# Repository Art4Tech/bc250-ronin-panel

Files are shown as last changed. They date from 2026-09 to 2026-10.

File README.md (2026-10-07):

# Ronin: A BC250 desktop

> [!NOTE]
> **Work in progress: the design and manual are changing rapidly.** You're welcome to build and remix Ronin. Check the revision notes and open decisions as you go. Rev0.3 is a provisional first edition, with fabrication and wiring details still to validate. If you have questions, [ask Arthur](https://artfedderson.tech/#start).

Ronin project logo

A custom desktop enclosure built around the BC250 board: a sheet-metal backbone, magnetically attached covers printed in transparent PCTG with a frosted finish, and an animated ESP32-P4 resource display at the base.

BC250 Ronin case visualization (https://artfedderson.tech/work/bc250-ronin)

**[Watch “The Computer They Didn't Make” — 89-second unofficial launch film](https://media.githubusercontent.com/media/Art4Tech/bc250-ronin-panel/main/case-design/Product_Renders_2026-10-03_V6/BC250_The_Computer_They_Didnt_Make_V6c.mp4)** · [Full project write-up](https://artfedderson.tech/work/bc250-ronin)

The film and images are CAD-based Blender visualizations. No case parts have been manufactured yet. Rendered features and lighting treatments are design proposals, not proof of completed hardware or firmware integration.

## Start with the case

| Location | Contents |
| --- | --- |
| [Printing and assembly manual — Rev0.3 draft](case-design/manual/README.md) | Illustrated PDF, editable BOM, open decisions, and proposed parts |
| [case-design/](case-design/README.md) | Design guide, download instructions, and portability notes |
| [BC250-Assy.SLDASM](case-design/BC250-Assy.SLDASM) | Main SolidWorks assembly, with component parts alongside it |
| [Backbone flat pattern](case-design/Flat%20pattern%20-%20Backbone.DXF) | Sheet-metal DXF export |
| [Latest film and website imagery](case-design/Product_Renders_2026-10-03_V6/) | V6c 89-second film, two Matchstick boards and untinted frosted PCTG |
| [Earlier V5 delivery](case-design/Product_Renders_2026-09-30_V5/) | Previous films and editable Blender scenes |
| [display/](display/README.md) | Published display baseline and current prototype status |
| [Rev A harness guide](case-design/manual/Ronin_LED_Harness_Rev_A.md) | Sourced connectors, numbered electrical maps, crimping and unverified interfaces |
| [October 6 manual updates](case-design/manual/REVISION_NOTES_2026-10-06.md) | Ordered adapter, new NVMe working-CAD route and next-revision checks |

Keep the contents of `case-design/` together so relative references stay intact. It includes the saved SolidWorks assembly and 45 part files, neutral CAD files, and all delivered render folders. It is a saved snapshot, not a clean-machine-validated Pack and Go export; see the [case guide](case-design/README.md) before fabrication.

## October 3 lighting revision

The latest rendered assembly replaces the rings and foot strip with two **Rainbow on a Matchstick boards by Blamm**, ten RGB LEDs per board. The revised CAD locations and printed diffusers are reflected in the new film. Untinted transparent PCTG is shown frosted, with 0.20 mm layer texture; the LEDs supply the color. See the [website update](https://artfedderson.tech/blog/bc250-matchstick-lighting-update) for component credits and current integration status. The original SolidWorks snapshot below is preserved and has not been replaced by this media release.

## October 6 hardware and display update

The **Ronin Rev A SATA-powered ESP32 LED adapter is ordered** and modeled in the current working CAD. It supplies two independent ten-pixel Matchstick channels while the display keeps USB power/control. One selector chooses 5 V or 12 V for both ports; **Matchstick V1.0 requires 5 V**. Delivery, bench checks, LED firmware and the real harness remain pending. Start with the [harness preparation guide](case-design/manual/Ronin_LED_Harness_Rev_A.md).

Ronin Rev A LED adapter design visualization

Design visualization from ordered fabrication layers and current CAD, not a physical-board photograph. Some component packages are simplified; the single 5 V selector shunt is illustrative. Native PCB/manufacturing files are not part of this public update.

Ronin Rev A adapter underside with exposed copper logo and board name

Ordered copper/mask artwork visualized in Blender with a gold ENIG finish. This is a design visualization, not an assembled-board photograph.

The working assembly now models an NVMe extension board, two printed extension mounts and an explicit ribbon route to the relocated SSD. Fit, retention and PCIe operation need physical testing. The repository's earlier CAD snapshot is unchanged; [October 6 revision notes](case-design/manual/REVISION_NOTES_2026-10-06.md) track the newer working CAD separately.

Current CAD locator of the NVMe extension, modeled ribbon and twin mounts

Pink identifies the ribbon route, lavender the two printed mounts, and teal the SSD/extension. The backbone and BC250 are ghosted for visibility. This is a current-CAD locator, not a cable cut-length, physical fit or storage-link validation.

## Current build status

- Machine internals are built and validated, with an initial cooling check complete.
- Software and the resource display are set up and working.
- Case fabrication is next. Fit and cooling need checking again inside the finished enclosure.
- Gamepad startup remains unfinished. The proposed LED layout still needs physical mounting and control integration.

Approximately **$375** has been spent so far, including the required filament. The remaining sheet-metal piece is estimated at **$275** for one unit, for an expected total around **$650**. A run of at least five targets a reduction of at least 60% in the sheet-metal cost (about $110 or less per piece); this is a target, not a confirmed quote for the whole machine.

## Get the complete design

CAD, Blender, and case media files use **Git LFS**. Install Git LFS, then:

```powershell
git lfs install
git clone https://github.com/Art4Tech/bc250-ronin-panel.git
cd bc250-ronin-panel
git lfs pull
git lfs fsck
```

Use a Git LFS checkout for the complete case assets. The [case-design README](case-design/README.md) includes SHA-256 verification instructions for the imported snapshot.

## Display and companion progress

The Windows prototype now has a native menu, profiles and six touch application tiles. Existing SolidWorks, Steam, Claude, PrusaSlicer, OBS and Codex windows come forward without duplicates; OBS also passed fresh-launch focus. USB resource telemetry and scene/audio controls work. [Current prototype status](display/CURRENT_STATUS.md) separates this local tested work from the earlier software package published here.

Linux, initially Bazzite, remains the design baseline. The shared app/protocol and portable profiles keep the workflow consistent; installed programs, sensors and desktop activation need host-specific bindings. Physical Linux/Wayland/Gaming Mode tests, Matchstick output, gamepad host wake and AI voice remain pending. Display Sleep/Wake affects the display, not PC power. Claude/Codex tiles open host apps; they are not the voice companion.

## Work on the display

The published baseline ESP32 firmware, resource companion, media, build scripts and original documentation live in **[display/](display/README.md)**. Start with that README and run its commands from `display/`. Its internal `project/` and `external-originals/` layout and pinned dependency release are preserved.

Third-party component models, software, and supplied media retain their existing rights. This repository assigns no blanket license to them.

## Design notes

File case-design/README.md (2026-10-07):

# Ronin case design

Ronin project logo

[Project overview](../README.md) · [Display software and its original README](../display/README.md)

> [!NOTE]
> **Work in progress: the design and manual are changing rapidly.** You're welcome to build and remix the case. The [Rev0.3 printing and assembly manual](manual/README.md) records the current revision and open decisions. Mounting, wiring, fit and assembly details still need validation. If you have questions, [ask Arthur](https://artfedderson.tech/#start).

Saved design and rendering snapshot imported on 2026-10-01. The original folder layout is retained so nearby parts, media and relative Blender references stay together.

## Printing and assembly manual

Start with the [Rev0.3 manual and editable companion files](manual/README.md). The PDF records current CAD locators, printing guidance, component evidence, and unresolved build decisions. The CSV and JSON files make the BOM, open items, and proposed parts easy to review and update. The saved October 1 CAD snapshot in this folder and the manual's later source revision must be checked together before fabrication.

## Latest media revision

[Product_Renders_2026-10-03_V6/](Product_Renders_2026-10-03_V6/) contains the new 89-second V6c film and compressed website images. It shows the updated two-board, twenty-LED Matchstick arrangement and frosted untinted PCTG. This is a media release; the October 1 SolidWorks snapshot is retained unchanged. The earlier V5 editable scenes remain available at their original paths.

## Open the design

- `BC250-Assy.SLDASM`: main SolidWorks assembly. The supplied `.SLDPRT` files are alongside it.
- `Flat pattern - Backbone.DXF`: backbone flat-pattern export.
- `.STEP` / `.stp` files: supplied neutral CAD component files.
- `bazziteBC250gui.png`: display reference artwork.
- `Product_Renders_2026-09-30_V5/`: earlier delivered photography and films, including the calm-audio commercial revisions and their editable Blender masters. Start with its `README.txt` and `Preview.html`.
- The original, V2 and V3 render folders preserve earlier deliverables.

The V5 handover states that GUI images, fonts and audio are packed where supported, and image strips use relative paths. Keep `cinematic_assets`, `stills`, and the other companion directories beside the Blender files. No raw render caches or rendering scripts are required to reopen these delivered scenes according to that handover.

The V5 lighting layout is a Blender proposal. Its reversed LED rings and foot strip are not completed mounting changes in the SolidWorks model. Rendered captions and effects do not establish that the panel firmware implements the depicted feature; see the repository's software status.

## October 6 working-CAD changes

The current working assembly includes one visible **Ronin Rev A SATA LED adapter**, one NVMe extension board, two printed extension mounts, one modeled extension ribbon and a relocated M.2 2280 SSD. The adapter has been ordered; delivery and bench acceptance are pending. The explicit ribbon route and mounts are modeled proposals awaiting physical fit, retention and PCIe checks.

Ordered LED adapter design visualization

Visualization from ordered fabrication layers and current CAD, not a physical photograph. Some packages are simplified; the optional single 5 V shunt is illustrated. This documentation/media update does not replace the saved October 1 assembly or publish native PCB/manufacturing files. See [manual revision notes](manual/REVISION_NOTES_2026-10-06.md) and [harness preparation](manual/Ronin_LED_Harness_Rev_A.md).

Ronin Rev A adapter underside with exposed copper logo and board name

Ordered copper/mask artwork visualized in Blender with a gold ENIG finish. This is a design visualization, not an assembled-board photograph.

Current CAD locator of the NVMe extension, modeled ribbon and twin mounts

Pink identifies the ribbon route, lavender the two printed mounts, and teal the SSD/extension. The backbone and BC250 are ghosted for visibility. This is a current-CAD locator, not a cable cut-length, physical fit or storage-link validation.

## Display progress

The current local Windows prototype has verified USB telemetry, scene/audio controls, a native menu/profiles and six application tiles. Existing app focus and duplicate suppression passed; OBS also passed fresh-launch focus. The repository retains an earlier software baseline. [Current status](../display/CURRENT_STATUS.md) explains the distinction and the Linux-first shared workflow.

Physical Linux GUI/Wayland/Gaming Mode, Matchstick output, gamepad host wake and AI voice remain pending. The two independent LED channels use SATA power; the display stays USB-powered. Matchstick V1.0 requires the adapter's **5 V** selection. Final wiring, mounts and firmware must be validated before applying power.

## Download and verify

CAD and media binaries are stored with Git LFS. With Git LFS installed:

```powershell
git lfs install
git clone https://github.com/Art4Tech/bc250-ronin-panel.git
cd bc250-ronin-panel
git lfs pull
git lfs fsck
```

`FILES-SHA256.json` lists every imported file, its size and SHA-256. From the repository root, verify the materialized files:

```powershell
$items = Get-Content -LiteralPath .\case-design\FILES-SHA256.json -Raw | ConvertFrom-Json
foreach ($item in $items) {
    $path = Join-Path .\case-design $item.path
    if ((Get-Item -LiteralPath $path).Length -ne $item.bytes -or
        (Get-FileHash -LiteralPath $path -Algorithm SHA256).Hash -ne $item.sha256) {
        throw "Verification failed: $($item.path)"
    }
}
"Verified $($items.Count) imported files."
```

Third-party component models retain their existing rights. No blanket license is assigned by this import.

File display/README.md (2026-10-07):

# Ronin display and companion

This is the original ESP32 resource-panel package, now contained in `display/`. The firmware and companion retain their existing paths under `project/` within this folder. For the enclosure, see the [project overview](../README.md) and [case-design guide](../case-design/README.md).

Case binary assets use **Git LFS**. Install Git LFS, then run `git lfs install` before cloning and `git lfs pull` inside the checkout afterward. Download ZIP is intended for the panel software workflow below; use a Git LFS checkout to obtain the complete case assets reliably.

## Baseline and newer prototype

The source, binaries and commands below are the **earlier published resource-panel baseline**. The newer local prototype has verified native menu/profiles and six Windows app tiles with existing-window focus and duplicate suppression. [Current status](CURRENT_STATUS.md) records its physical checks and Linux limits; this documentation update does not update the baseline firmware package.

The **Rev A SATA-powered LED adapter is ordered**. See [harness preparation](../case-design/manual/Ronin_LED_Harness_Rev_A.md) for sourced parts and unverified connector/mux interfaces. Two independent Matchstick channels, startup/fault handling and physical LEDs remain firmware/bench work.

## Resource panel — published baseline

An Elecrow CrowPanel Advanced **5-inch ESP32-P4 V1.0** display for a BC250 desktop, with a serene animated ronin/onsen scene, day/night transitions, per-clip sound, and USB serial resource monitoring from Windows or Linux.

**Working in this baseline:** CPU/RAM/disk usage, optional Windows CPU temperature through LibreHardwareMonitor, touchscreen sleep/wake, four SD video/audio clips, settings QR helper, and Bluetooth scanning/pairing experiments.

**Unfinished in this baseline:** the voice-companion workflow, two-board Matchstick ARGB control, app/page-aware touch shortcuts, reliable GameSir button input and PC power-on relay, standby wiring, controller handoff, and native USB microphone/speaker and video streaming. A successful BLE connection is not a completed PC power-on solution.

## Next display work

Linux, initially Bazzite, is the product baseline. Keep one shared companion/protocol and portable profiles, with explicit host-local paths, sensors, permissions and desktop bindings. Linux GUI/Wayland/Gaming Mode acceptance remains pending. Elgato software is not intended as a normal-operation requirement.

Planned work includes advanced effects for the two ten-pixel Matchsticks, resource-module configuration, automatic app-context/held shortcuts, gamepad host wake and AI voice. Current touch releases/manual profiles do not establish those broader features. Display Sleep/Wake does not operate PC power; scene audio and Claude/Codex host-app tiles are not a completed voice workflow. See [current status](CURRENT_STATUS.md) before choosing a package or making feature claims.

## Continue on Windows

Clone this repository into a short path, then open PowerShell there:

If Git is not installed yet, use GitHub's **Code → Download ZIP**, extract it to a short path such as `C:\BC250`, and run the same commands below. The dependency release includes Git for the firmware build.

```powershell
cd .\display
powershell -NoProfile -ExecutionPolicy Bypass -File .\Get-Dependencies.ps1
powershell -NoProfile -ExecutionPolicy Bypass -File .\Build-Firmware.ps1
```

Run all subsequent commands from `display/`. The dependency script downloads hash-verified release assets containing the pinned Windows SDK, toolchains and Python environments, then relocates them. The build script creates a fresh `build-migrated` directory. It does not flash the board. Windows x64 is required for these prebuilt tools. Firmware source and installed managed components are in `project/work/panel-test`.

The existing display can be moved without reflashing. Start the companion using the newly assigned COM port:

```powershell
$py='.\project\work\idf-tools\python_env\idf5.5_py3.12_env\Scripts\python.exe'
& $py .\project\outputs\Resource-Panel\resource_panel.py --list-ports
& .\project\outputs\Resource-Panel\Windows-Monitor.ps1 -Action Start -Port COM7
```

See [HANDOVER.md](HANDOVER.md) for build, flashing, SD layout, Windows temperature setup, Linux companion instructions, testing and unfinished work. It also describes the separate complete private migration package; private-only files mentioned there are intentionally absent from this public repository. See [PUBLICATION.md](PUBLICATION.md) for the exact boundary.

## Media and firmware

All six supplied MP4 originals and the generated artwork versions are included. Current SD files are the eight `day3`, `nite3`, `sleep3`, and `wake3` `.rvj`/`.pcm` assets under `project/outputs/Resource-Panel/video/movies-v3`; place them in `/BC250` on the card. Each clip has its own audio; transition audio continues into the idle scene. Initial caching takes about 47 seconds and playback is approximately 10 fps.

Current release binary: `project/outputs/Resource-Panel/firmware/dashboard-movies-v3.bin`. Historical C exports in outputs are snapshots; **edit the full project source** in `project/work/panel-test`.

`Prepare-Media.py` rebuilds conversions into a new directory without overwriting supplied assets. The old procedural warp preview was rejected; the current animation uses supplied videos.

Third-party source and tools retain their own licenses. No new blanket license is assigned to vendor code or supplied media by this repository.

## Display preview

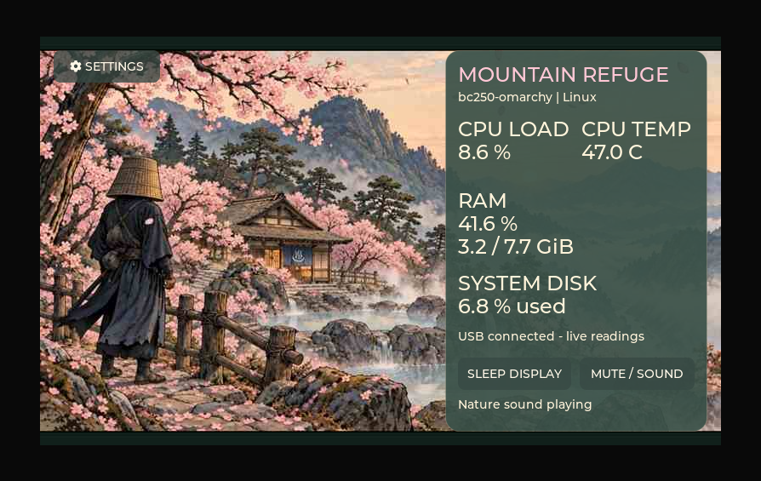
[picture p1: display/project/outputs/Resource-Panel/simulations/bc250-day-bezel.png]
Day scene with simulated Omarchy/BC250 readings


This preview uses an unchanged frame of the current day video and the firmware's bitmap fonts. The active image is 800 × 480 pixels. The [printable sizing preview](project/outputs/Resource-Panel/simulations/bc250-day-actual-size.html) and [physical-size SVG](project/outputs/Resource-Panel/simulations/bc250-day-actual-size.svg) use a 120.7 × 76.3 mm black front, with a centered 108 × 64.8 mm active area. Values are illustrative, assuming approximately 8 GiB assigned to system RAM; they are not measured BC250 results. See preview-details.json for assumptions. This is not a fabrication drawing.

## Bazzite preview — historical UI concept

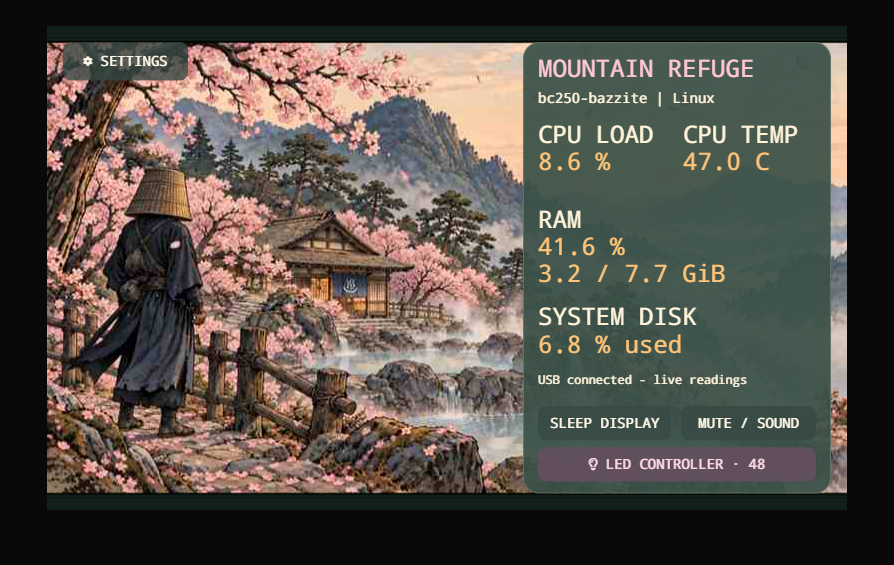
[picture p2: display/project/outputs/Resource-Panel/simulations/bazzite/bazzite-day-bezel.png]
Bazzite dashboard concept


[Interactive preview](project/outputs/Resource-Panel/simulations/bazzite/bazzite-interactive-preview.html) (download and open locally): DroidSansM Nerd Font Mono, LED controller concept for two 24-pixel rings, and 120.7 × 76.3 mm outer dimensions with 3.5 mm top and 7.5 mm bottom bands. Native image is 800 × 480; the physical illustration models a 108 × 65.3 mm active area. This is a simulated UI, not flashed firmware or a fabrication drawing. [Preliminary wiring notes](project/outputs/Resource-Panel/simulations/bazzite/NEOPIXEL-WIRING.md).

This preserved Bazzite preview predates the current lighting hardware. Its two 24-pixel ring controls are historical UI concepts; the current target is two ten-LED Rainbow on a Matchstick boards. Matchstick control, voice interaction, host gamepad wake and automatic context switching remain pending. Manually selected action pages now work in the newer local prototype described in [current status](CURRENT_STATUS.md); this historical preview remains unchanged.

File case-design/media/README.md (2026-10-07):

# Ronin October 6 hardware illustrations

These are Blender renders from the October 6 working CAD and the Gerbers used for the ordered Rev A PCB. They are design visualizations, not photographs of manufactured hardware.

- [Adapter top](ronin-led-adapter-top.jpg) and [detail](ronin-led-adapter-detail.jpg): current component bodies and ordered copper/mask/silkscreen. Some IC/fuse packages are simplified, and the single 5 V selector shunt is illustrative rather than a confirmed shipment configuration.
- [Adapter back](ronin-led-adapter-bottom.jpg): actual ordered exposed-copper logo and board-name artwork, with an ENIG material.
- [NVMe locator](ronin-nvme-route.jpg): current modeled extension, relocated 2280 SSD, two printed mounts and ribbon route. Pink is the ribbon, lavender the mounts, and teal the SSD/extension. Ghosted backbone/BC250 geometry makes the route visible. Colors do not describe actual material, temperature or airflow.

Board arrival, assembly inspection, electrical/thermal checks, installed fit and LED control remain pending. The cable drawing is not a cut-length, bend-limit or PCIe validation. The public CAD/software packages elsewhere in the repository remain earlier snapshots; see the manual revision notes and current display status.

Native PCB/CAD manufacturing inputs, Gerbers, BOM/CPL and Blender source files are withheld from this public media update.

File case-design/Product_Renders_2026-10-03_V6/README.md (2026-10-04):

# V6c — The Computer They Didn't Make

[Watch the 89-second film](https://media.githubusercontent.com/media/Art4Tech/bc250-ronin-panel/main/case-design/Product_Renders_2026-10-03_V6/BC250_The_Computer_They_Didnt_Make_V6c.mp4) · [Case study](https://artfedderson.tech/work/bc250-ronin) · [Lighting revision](https://artfedderson.tech/blog/bc250-matchstick-lighting-update)

Published media revision, October 3, 2026. 1920 × 1080, 24 fps, 89 seconds, H.264 with stereo AAC and fast-start metadata. Instrumental score; no narration, typing clicks or abrasive transition wipes. Twenty seconds of additional reading time are distributed across the captions. The final card uses “soon™.”

The current lighting assembly uses two Rainbow on a Matchstick boards by Blamm, ten RGB LEDs each, and their printed diffusers in the updated CAD positions. The earlier rings and foot strip have been removed. Transparent 3D-Fuel PCTG is visualized with frosted surfaces and visible 0.20 mm FDM layer lines; color comes from the RGB LEDs.

The case and its contents are native CAD renders. The maker-desk scenes combine them and official Voron V0.2r1 CAD with generated room/person backgrounds. This is an independent, unofficial thought experiment with no Voron endorsement. Images do not show a fabricated enclosure or establish performance, fit or thermal results. Enclosure fabrication, revised lighting integration and gamepad startup remain unfinished.

Specific contributor credits: Rainbow on a Matchstick by Blamm; EPS Power Adapter and PS_ON adapter by Mosfet.Party; the single 92 mm fan-shroud remix based on MandicReally's CAD.

This folder publishes the final film, its verification report, and compressed website imagery. It does not replace the original SolidWorks snapshot or claim to be a new Pack and Go export. Earlier V5 films and editable scenes retain their original paths. The new editable Blender masters and complete companion assets are in the local V6 delivery.

Binary files use Git LFS. `FILES-SHA256.json` records this media release independently of the original case snapshot's manifest. Third-party model/media rights remain with their respective owners; this release assigns no blanket license.

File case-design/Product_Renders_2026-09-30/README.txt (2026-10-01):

BC250 PRODUCT STUDIO — 30 September 2026

Open BC250_Product_Studio.blend in Blender 5.2 or newer.
The GUI image is packed into the project; no texture relinking is required.

DELIVERABLES (16-bit PNG masters; JPEG versions in share-ready)
01_BC250_Dark_Hero.png — dark front / left three-quarter, 2400 x 2400
02_BC250_Bright_Studio.png — bright front / right three-quarter, 2400 x 2400
03_BC250_Rear_Illumination.png — rear view with the two illuminated buttons, 2400 x 2400
04_BC250_Display_Detail.png — original backlit GUI and front detail, 2600 x 1800
05_BC250_PCTG_Layers.png — rear vents, printed texture and button lighting, 2600 x 1800
06_BC250_Animated_Studio_Loop.mp4 — four-second seamless 1080 x 1080 H.264 loop at 24 fps

BLENDER SCENES
01 | Dark studio
02 | Bright studio
03 | Animated studio loop

The CAD assembly, lighting additions and photographic studio are in separate
collections. Component and body names are retained. The model uses meters;
the interface is configured to display millimeters. Stills use Cycles,
adaptive sampling and denoising. The project supports AMD HIP GPU rendering.

PRINTED PCTG
Purple translucent appearances have been translated to rough transmission,
volume absorption and procedural ridges at 0.20 mm pitch. Wall panels use
assembled vertical as the print direction. The top cover stands on its rear
edge. Change each "Print direction" empty to adjust the build direction;
change the layer-pitch math node and bump distance in the PCTG materials
to adjust layer height and prominence. This is a visual surface model, not
a slicer toolpath simulation, volumetric infill or a measured filament match.

LIGHTING AND ANIMATION
A concept LED strip is placed beneath the BC250 PCB with soft internal fill.
The existing left power-ring diffuser and rear power/reset button geometry
have emissive finishes. The original GUI is textured at its SolidWorks sketch
picture coordinates. The animation adds a small live-status pulse and gentle
backlight variation, plus a slow camera move; it is not a live software feed.

IMPORT NOTE
67 visible components were imported from the open BC250-Assy assembly,
using 2,281,689 source triangles. Source CAD files were not saved or altered.
SolidWorks did not provide mesh triangles for four small curved surfaces on
the two 92 mm fans (approximately 330 square millimeters per fan). A second
CAD tessellation method also failed. The affected faces are omitted and
listed in the Blender project's READ ME text. Enclosure and display meshes
were unaffected. CAD material colors and assignments were translated to
Blender's physically based shaders; the shading systems are not identical.

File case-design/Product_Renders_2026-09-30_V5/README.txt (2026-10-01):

BC250 — V5 / INDEPENDENT LED OUTPUT

The 48 ring LEDs have 20 times their V3 output; the 12-pixel foot strip has 8 times its V3 output. This is 10 times and 4 times, respectively, the V4 preview output. LED direction, geometry, studio exposure, colors and animation timing are retained.

Lighting revision
The two imported 24-pixel rings now face the sheet-metal backbone in the Blender proposal. Their light bounces into real gaps and perforations; the PCB and backbone remain opaque. Only the forward lens faces emit. Package sides and backs do not emit, and the previous omnidirectional RGB light helpers have been removed.

An 80 mm strip with 12 individual RGB LED packages sits at the foot of the board and points upward along the component side. It uses lower output than the rings and follows their color treatments, animated rainbow, wake-up and dimming. There are 60 individually animated RGB emitters in total. Neutral white is included alongside cyan, magenta, mint and rainbow.

The ring orientation and foot strip are proposed physical layout changes represented in Blender. Original SolidWorks files were not changed. The strip is a rendering concept, not a completed CAD mounting design. Intensity is composed for photography, not a calibrated prediction of physical LED output.

Deliverables
BC250_60s_Directional_RGB.mp4 — 60 seconds, 1920 × 1080, 24 fps, H.264.
BC250_Showcase_Directional.blend — complete editable assembly, camera, lighting, animation and feature captions.
BC250_Directional_Studio.blend — separate still-photography studio.
stills — eight full-resolution 16-bit PNG masters.
share-ready — matching full-resolution JPEGs, quality 95.
Preview.html — local photo gallery and movie player.
Photo_Contact_Sheet.jpg — photo overview.

Photo treatments
01 Cyan / dark hero
02 Neutral white / rear three-quarter
03 Magenta / dark hero
04 Mint / bright studio
05 Addressable RGB / rear three-quarter
06 Addressable RGB / display and power-button detail
07 Addressable RGB / PCTG surface detail
08 Neutral white / dark hero

Film timing
00–03 Opening hero
03–10 Front view, 5.3-inch touch display, integrated ESP32, LED control and resource monitoring
10–16 Right side and four USB ports; neutral-white LEDs
16–22 Rear view and Wi-Fi 7 / BLE 5.3 via NVMe splitter; mint LEDs
22–28 Elevated flyover and NVMe in cooling airflow; magenta LEDs
28–34 Left side and Dual Arctic P9 PWM PST fans; neutral-white LEDs
34–41 Magnetic cover removal and reassembly; rainbow LEDs
41–46 Bright studio and gamepad startup
46–49 Studio fades to dark
49–51 Rings and foot strip wake in sequence
51–55 Display wakes while the rainbow pattern moves through individual LEDs
55–58 Display sleeps; RGB emitters dim to 8 percent
58–60 Dimmed hero and fade to black for looping

Blender scenes
01 | Dark studio
02 | Bright studio
03 | 60 second flyover — camera, RGB, studio lighting, screen and cover movement
04 | Final film + feature captions — editable captions and fades over Scene 03

Source and materials
All 79 visible SolidWorks component instances are represented. Both 24-pixel rings and ten additional magnets were imported from the refreshed assembly, together with changed backbone and front/top/rear-cover geometry. Raised LED packages and lens surfaces were added at the ring CAD footprints. The original GUI and fonts are packed. GUI animation represents backlight/status behavior rather than a recording of the software.

Translucent PCTG retains procedural 0.20 mm layers with upright panel print orientation. These surface layers approximate FDM appearance; internal infill and slicer toolpaths are not simulated. Cover movement is an illustrative exploded view returning to the imported positions. As in the previous deliverable, four small curved fan faces failed SolidWorks tessellation, about 330 square millimeters per fan; the other visible fan geometry is present.

Rendering
Cycles with ray-traced shadows and indirect illumination. Stills use 96 samples; the film uses 16 during motion and 48 on stationary holds, with denoising. Identical static film states reuse an identical rendered frame. The 60-pixel RGB animation, studio transitions, screen wake/sleep and original feature captions remain baked into the Blender files. No external scripts are required for playback or editing.

COMMERCIAL FILMS

BC250_Cinematic_Commercial.mp4
The first requested commercial: the 60-second all-sides camera tour with five close-up cutaways, animated feature captions, the magnetic-cover demonstration, and the studio / RGB / display wake-and-sleep finale. The close-ups are 2304 x 1296 Cycles renders with depth of field and subtle editorial push-ins. The cooling close-up temporarily removes the front cover for visibility; its caption states that the cover is removed.
BC250_Cinematic_Commercial.blend is the editable source. It contains the original full 3D tour, macro cameras, image cutaways, typography and audio.

BC250_Made_To_Be_Seen.mp4
The second requested commercial, with a separate creative treatment: 'Made to Be Seen'. A new grazing-light macro and low hero camera move open the film; a tighter editorial sequence moves through touch control, connectivity, airflow, magnetic covers and three lighting personalities. The studio-to-night sequence returns before the final BC250 signature. It has a new original score and effects mix.
BC250_Made_To_Be_Seen.blend is the editable master. It includes the original tour scene and the new eight-second light-study scene, using live 3D Scene strips rather than requiring the cached render frames.
BC250_Director_Light_Study.blend is the standalone new cinematography setup. The case and component mesh coordinates and topology were hashed before and after its preparation; all matched. No product meshes were added or edited. Cameras, studio lamps, LED output animation, editing, typography and sound were changed. Product surface materials and the physical LED occlusion are retained.

Both commercials are 60 seconds, 1920 x 1080, 24 fps, H.264 with 48 kHz stereo AAC audio at 256 kbps. BC250_60s_Directional_RGB.mp4 is the additional silent all-sides showcase.

The music and sound design were synthesised specifically for these films, with no third-party recordings or sampled songs. The two 60-second 48 kHz / 24-bit stereo WAV masters are included in cinematic_assets. Audio peaks and durations were checked numerically; the film containers were checked for both video and AAC audio tracks.

The new moving macro uses 48 Cycles samples, and the new moving hero uses 32, with denoising. The existing tour uses the sampling described above. The new eight-second shot sequence is reused for the closing hero; the rest of the second film uses a fresh edit of the accurate V5 tour and photographs.

PORTABLE PROJECTS
Keep the cinematic_assets and stills directories alongside the Blender files. GUI images, fonts and audio are packed where Blender supports it; VSE image strips use relative paths to the included images. No rendering scripts or raw frame caches are needed to reopen and edit the projects. The live tour scenes include compositor-based AgX finishing followed by a Standard inverse conversion, with the scene view set to Standard, so the editable scene strips retain the same photographic look as the final films. Comparison frames were rendered directly from both commercial projects and checked against the decoded exports. The videos are ready to share directly.

Preview.html and Photos.html play all three videos and display the eight photographs. The verification reports record video frame counts, dimensions, durations, audio tracks, and unchanged geometry. Original SolidWorks files remain untouched.

CALM AUDIO REVISION
Both commercials now have calm replacement mixes. Every noise-based transition sweep and scratchy mechanical click has been removed. The second film's noise-based hi-hat is also removed. The music retains its previous level; the remaining soft LED/display tones are approximately 14 dB quieter. No gain normalization was applied to compensate for the removed effects.

BC250_Cinematic_Commercial_Calm_Audio.mp4
BC250_Made_To_Be_Seen_Calm_Audio.mp4

The original video streams were copied without re-encoding and their hashes match exactly. The canonical commercial MP4 filenames also contain the revised mixes. Both editable commercial Blender files and their packed WAV masters have been updated. The silent all-sides showcase and photographs are unchanged.

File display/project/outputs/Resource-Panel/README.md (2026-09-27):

# USB Resource Panel

Elecrow CrowPanel Advanced 5-inch ESP32-P4 V1.0. Connect the computer to the panel's **UART0 USB-C** port with a data cable. No Wi-Fi is used.

## Current features

- Total CPU utilization, RAM utilization and used/total GiB.
- Used percentage of the host's system filesystem (not all attached drives).
- CPU temperature when a supported Linux sensor is available. The displayed Linux value is the hottest reading in the selected CPU sensor group.
- Host name and operating system.
- Readings clear after five seconds without valid updates.
- The on-panel microphone/speaker recording test remains available.

This firmware does **not** yet provide USB microphone/speaker endpoints, Bluetooth gamepad reception, GPU utilization, fan monitoring, or power-button control. The audio button runs a local recording/playback test only. Windows CPU temperature needs an additional hardware-monitor integration; this version shows Unavailable. It does not use the ESP32's own temperature as the PC temperature.

## Windows setup

Install Python 3 if necessary, then open a terminal in this folder:

```powershell
py -m venv .venv
.\.venv\Scripts\python.exe -m pip install -r requirements.txt
.\.venv\Scripts\python.exe resource_panel.py --list-ports
.\.venv\Scripts\python.exe resource_panel.py --port COM10
```

COM10 was the port on the development PC. Confirm the port on each computer. Keep the terminal open; Ctrl+C stops monitoring. Close serial monitors before running this program. No administrator privileges or network access are needed during normal monitoring.

## Debian, Ubuntu, Raspberry Pi OS, or Omarchy

Install Python 3 with venv/pip support through the distribution's package manager. For Debian/Ubuntu this is normally `sudo apt install python3-venv python3-pip`; Omarchy/Arch uses `sudo pacman -S python python-pip`.

```sh
python3 -m venv .venv
.venv/bin/python -m pip install -r requirements.txt
.venv/bin/python resource_panel.py --list-ports
.venv/bin/python resource_panel.py --port /dev/serial/by-id/YOUR-PANEL
```

Use the actual stable /dev/serial/by-id path when available; otherwise use the listed /dev/ttyUSB device. If access is denied, check its owning group with `ls -l /dev/ttyUSB*`. Add your user to the owning serial-access group (commonly dialout on Debian/Ubuntu or uucp on Arch), then log out and back in. Do not make the device world-writable.

The same script supports Windows and Linux; only Windows has been tested on physical hardware so far. Linux sensor availability depends on the board, kernel and exposed hwmon/thermal drivers.

## Checks

1. Start the companion; readings and host name should appear within two seconds.
2. Compare RAM usage with the host's monitor. Sampling and accounting may differ from Windows Task Manager.
3. Stop the companion. Within five seconds the panel should show Disconnected and clear its readings.
4. Restart it; readings should return. Unplugging/replugging is retried automatically when the port path remains the same.
5. Move the panel to another supported computer and run its local companion. No firmware change is required.

Use `--once` to inspect one sample without USB. Use `--disk D:\\` on Windows or `--disk /mnt/data` on Linux to monitor another filesystem. Use `--seconds 30` for a timed test.

The companion sends resource numbers and the host name over the USB cable. It does not open a network listener or send commands to the computer. It is not installed as an automatic startup service.

## Recovery

The adjacent Panel-Recovery folder contains the original 16 MB factory flash backup and its checksum. App-only images are not substitutes for that full backup. Preserve recovery files before modifying firmware.

## Convenient Windows start/stop

The panel's SETTINGS button now shows a verified QR code and readable link to the official Libre Hardware Monitor downloads, plus USB/CPU-temperature status. See [Windows-Setup.md](Windows-Setup.md). The companion optionally reads CPU temperatures from Libre Hardware Monitor's local WMI feed; keep windows_temperature.py beside resource_panel.py. No network listener is required. The QR links to the sensor helper, not an installer for this companion.

Run Windows-Monitor.ps1 -Action Start -Port COM10 to start monitoring in the background, and Windows-Monitor.ps1 -Action Stop to stop it. It uses this folder's .venv, or the existing development environment on this PC. It does not register a startup task. The monitor retries if USB is unplugged. Logs and a process record are kept beside the script.

## Sakura mountain refuge

The dashboard embeds matching day/night paintings, 36 drifting petals, a gently swaying foreground sakura branch, subtle water ripples, slow cloud drift and daytime mist. The ronin's poses crossfade over 2.2 seconds; this is not a skeletal or frame-by-frame character animation. Original artwork and built-in image-generation prompts are in `art/`.

Sleep Display hides the resource overlay, shows the sleeping ronin and dims the backlight from 60% to 12%. The panel stays powered and touch-sensitive. Tap anywhere to return to daylight. This button does not shut down the host computer.

The companion marks its first packet after opening USB, or after a sending gap longer than five seconds, as a wake event. The display also wakes when valid telemetry resumes after a five-second gap. Ordinary updates leave a manually sleeping display asleep. Restarting the companion therefore wakes the display too; this is a host-connection indication, not a verified BC250 power-state signal. Powering off the panel's USB supply prevents it from showing the night scene or receiving Bluetooth.

Test with the companion running: press Sleep Display, wait at least ten seconds, then tap to wake. Press Sleep again, stop the companion for more than five seconds and restart it: daylight should return automatically. Repeat during a transition to check responsiveness. Confirm the resource text stays readable and petals move smoothly. The local audio test remains available.

The experimental video firmware plays day/night MJPEG clips from microSD and includes GameSir BLE testing. The GameSir has paired in G-Touch mode; waking the display on a new controller connection is implemented but still needs a physical test. Home-button reports and BC250 power-relay operation are not implemented. No Wi-Fi connection is needed. See TEST-STATUS.md for current limitations; dashboard.bin remains the earlier artwork-only fallback.

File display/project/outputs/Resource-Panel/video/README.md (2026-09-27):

# Full-screen motion test

Open preview.html to preview the animated painting locally. These loops animate water, clouds, blossoms and the canopy from the existing artwork. The ronin remains in the standing or sleeping pose; this is not a frame-by-frame sit/stand character animation.

Each day.rvj/night.rvj contains 60 distinct baseline JPEG frames at 800×480, requesting 15 fps. The panel's P4 hardware JPEG decoder renders them from the card, retaining the live resource overlay and touch sleep/wake controls. Actual delivered FPS is logged as PANEL_VIDEO and must be measured on hardware with Bluetooth and SD activity running.

Files go in /BC250/day.rvj and /BC250/night.rvj on the card. The uploader refuses to overwrite existing clips or temporary files. It verifies SHA-256 on the panel and only renames the temporary file after a complete, matching transfer. No formatting is performed. Existing unrelated card files are preserved.

Stop Windows-Monitor.ps1 before running ../upload_video.py day.rvj night.rvj with the development Python environment. The uploader briefly changes serial speed to 460800 for transfer, then returns it to 115200. Restart Windows-Monitor.ps1 afterward. Do not remove the card or disconnect power during transfer. These RVJ files use our small frame container, not an AVI/MP4 container; arbitrary MP4 files do not play directly.

RV01 container: 16-byte little-endian header: magic RV01, uint16 width, uint16 height, uint16 fps, uint16 reserved, uint32 frame count. Each frame: uint32 JPEG byte length followed by JPEG data. Accepted dimensions are exactly 800×480, 1–30 fps, at most 9000 frames, and at most 256 KiB per compressed frame.

With no valid clip, the built-in scene remains available. Native USB live video streaming from the host is not implemented yet. This first test verifies local decode, display refresh, and SD throughput before adding a streaming transport.

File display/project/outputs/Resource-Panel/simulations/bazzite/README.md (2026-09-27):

# Bazzite preview

UI mockup only, not flashed firmware. Open bazzite-interactive-preview.html; the LED button opens a working local interaction preview with power, colors, brightness and effect selection. No hardware connection is made.

The PNG active area is exactly 800x480. The black bezel is horizontally centered and raised vertically: 3.5mm top / 7.5mm bottom with a modeled 108x65.3mm active area. Overall size is 120.7x76.3mm, as requested. Native PNGs remain 800x480; the bezel illustration applies slight vertical scaling. Print the HTML at Actual size / 100% for physical dimensions; on-screen size depends on monitor scaling.

Font: DroidSansM Nerd Font Mono, from https://github.com/ryanoasis/nerd-fonts/tree/master/patched-fonts/DroidSansMono . Font license is included under fonts/. The HTML embeds its font and video frame for offline viewing.

Readings are simulated light-desktop values, not Bazzite benchmarks. The planned count is 48 RGB pixels (two 24-pixel rings). Exact NeoPixel product, connector and a confirmed free ESP32-P4 GPIO are required before implementing its output.

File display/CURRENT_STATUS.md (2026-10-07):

# Ronin display and companion — current prototype

**Updated:** 2026-10-06. This summarizes the newer local prototype. Firmware, binaries and the resource helper elsewhere in this repository remain the earlier published baseline; this documentation update does not replace them.

## Working on the Windows test host

Live USB CPU/memory/disk telemetry, animated local scenes/audio, display Sleep/Wake and mute controls have physical verification. The newer prototype adds a native menu, saved profiles and a two-row, three-column application page:

| | Left | Middle | Right |
| --- | --- | --- | --- |
| Top row | SolidWorks | Steam | Claude |
| Bottom row | PrusaSlicer | OBS | Codex |

The user verified all six buttons bringing existing windows forward without duplicates; the existing-window path also restores minimized windows. OBS passed a fresh-launch/focus check. Other fresh launches have not been separately established. The host checks exact application identity and reports refused focus instead of blindly opening another copy.

In the current prototype, choose **RONIN MENU → Actions → Applications**. Normal startup requires **Enable reviewed tap actions for this session** in the companion. Short, completed releases execute reviewed actions; canceled/incomplete touches do not. One worker owns USB; run the paired companion rather than a second serial helper.

Physical Next/Previous/Home passed, with cached repeat changes faster than first load. A counter-only Bitfocus Satellite proof and guarded handoff are implemented; this does not establish every Bitfocus integration or automatic app-context switching.

The latest change is host-only: installed firmware remains **`ronin-inc3-20261004-r1`**. Verification recorded **302 Windows host tests** and **264 Linux pure-code tests**, plus physical Windows checks. Automated tests do not establish Linux desktop operation or physical LED output.

## Linux is the design baseline

Ronin targets Linux, initially Bazzite on the BC250, with one shared companion, firmware protocol and portable profiles wherever practical. Program paths, sensors, serial permissions, startup and desktop activation are host-specific bindings. A Windows SolidWorks binding does not make SolidWorks available on Linux: unavailable programs need an explicit alternative or remain unavailable.

The Linux X11 activation path uses `wmctrl`/`xprop` and exact process identity. Physical Linux GUI, native Wayland and Bazzite Gaming Mode tests remain pending. Normal operation is not intended to require Elgato Windows/macOS software. Bitfocus is the shared control-backend direction, with the Ronin app retaining sole USB ownership.

## Still being built

| Function | Status |
| --- | --- |
| Two ten-pixel Matchstick channels | Rev A SATA-powered adapter ordered; harness, mux, firmware and physical output unverified. See [harness preparation](../case-design/manual/Ronin_LED_Harness_Rev_A.md). |
| Resource monitor configuration/modules | Live telemetry works; broader module installation/configuration remains to develop. |
| Automatic app-context / held shortcuts | Pending; current reviewed releases and manually selected profiles are narrower. |
| Gamepad host wake/startup | Pending. **Display Sleep/Wake changes the display, not PC power.** |
| AI voice companion | Pending. Mic/speaker hardware and scene audio are not a completed voice workflow; Claude/Codex tiles launch host apps. |
| Linux GUI / hardware / Gaming Mode | Pending physical testing on the target BC250. |

Build and remix Ronin freely. It is evolving quickly; [reach out with questions](https://artfedderson.tech/#start). New source deliveries and tested instructions will have their own revision/evidence. The [Rev0.3 manual](../case-design/manual/README.md) is a frozen first-edition PDF, with newer work in [revision notes](../case-design/manual/REVISION_NOTES_2026-10-06.md).

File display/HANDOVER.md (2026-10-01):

# BC250 / Elecrow resource panel — migration handover

**Repository layout:** the package root referenced below is now `display/`. Open PowerShell there for these commands. The historical validation and private migration-package notes are retained.

Prepared 2026-09-26 for a new **Windows x64 development PC**. All original files on the old PC are preserved. This folder is the copyable package; copy the whole folder, not just the companion. No device was flashed, erased, or reformatted during packaging.

## First use on the new PC

1. Copy this folder to a short local path such as `C:\BC250`. Allow roughly 15 GB of free space for the package plus a fresh build. Avoid OneDrive and very deep folder paths for compilation.
2. Open PowerShell in that folder. Before changing anything, verify the supplied files:
   ```powershell
   & .\project\work\python\cpython-3.12.13-windows-x86_64-none\python.exe .\Verify-Package.py
   ```
   Expect zero failures. The manifest covers the payload, scripts and documentation; it excludes itself and the verification report.
3. Repair the two Python environments for their new location:
   ```powershell
   powershell -NoProfile -ExecutionPolicy Bypass -File .\Setup-Windows.ps1
   ```
   This uses bundled runtimes and packages, without pip downloads or global Python installation. Run it again if the folder moves. It updates the copied environments only. Use `python.exe -m pip`, not their old `pip.exe` launchers, which retain old paths.
4. Plug the display into a USB data port. Keep its existing microSD in place. No reflashing is needed to continue using it. Identify its new serial port:
   ```powershell
   $py='.\project\work\idf-tools\python_env\idf5.5_py3.12_env\Scripts\python.exe'
   & $py .\project\outputs\Resource-Panel\resource_panel.py --list-ports
   ```
   COM10 belonged to the old PC; substitute the detected port below.
5. Start monitoring, then check the display:
   ```powershell
   & .\project\outputs\Resource-Panel\Windows-Monitor.ps1 -Action Start -Port COM7
   # Stop it before flashing or uploading media:
   & .\project\outputs\Resource-Panel\Windows-Monitor.ps1 -Action Stop -Port COM7
   ```
   Start may require the same per-process PowerShell execution-policy invocation as setup. No startup task or service is installed. The original `running.json` is a historical PID record; the controller checks the exact script path and process creation time before acting, so it will not treat an unrelated PID as its companion.

## What is included

* `project/work/`: the entire original development tree, including the full ESP-IDF checkout, vendor checkout, managed components, toolchains, Python environments, standalone Python 3.12, build output, scripts, tests and diagnostic logs. Redundant pip/uv caches are excluded; their installed dependencies are included.
* `project/outputs/`: the complete runbook, companion, firmware versions, factory backup, artwork, prompts, previews, media conversions and status documents.
* `external-originals/Downloads/`: all six user-supplied MP4s, copied directly from Downloads: day, night, dayidle, nightidle, sleepytime, wakeuptime.
* `external-originals/generated-images/`: all five images generated for this task, including earlier versions outside the project folder.
* `dependencies/Python314/`: the original Python 3.14.7 base used by the esptool environment; `dependencies/Git/`: Git for Windows 2.52.0 including its command-line runtime and licenses.
* `dependencies/LibreHardwareMonitor.NET.10.zip` and its extracted application folder, including existing settings. The optional system runtime/driver requirements are below.
* `SOURCE-PROVENANCE.json`: original absolute path, copied path and size for every source file; hashes or prior-copy verification records accompany them. This records the pre-migration source snapshot. `MANIFEST-SHA256.json` describes the final package, including migration scripts. Source files adapted for relocation may therefore intentionally differ between these two records.
* Exact Python package lists and ESP-IDF revision/submodule inventory are at the package root. Licenses supplied with dependencies are retained in their original directories.

## Authoritative source and build

**Edit `project/work/panel-test`, not the exported historical C files in outputs.**

* `main/main.c`: dashboard, settings/QR, resource parsing and scene state.
* `main/panel_movie.c`: current four-clip player, caching, clocks and audio-tail behavior.
* `main/panel_video.c`: SD mount, JPEG decode and serial upload protocol.
* `main/panel_bluetooth.c`: experimental GameSir pairing/reconnect/display wake.
* `peripheral/bsp_illuminate/bsp_illuminate.c`: RGB/LVGL display synchronization and byte order.
* `sdkconfig`, `partitions.csv`, `dependencies.lock`, `main/idf_component.yml`, all CMake files and `managed_components/`: reproducible configuration and resolved source dependencies.

ESP-IDF **5.5.4**, LVGL **9.1.0**, esp_hosted **2.12.12**, esp_wifi_remote **0.16.3**. Target ESP32-P4; 16 MB flash, 32 MB PSRAM; CPU 360 MHz, PSRAM 200 MHz. RISC-V compiler `esp-14.2.0_20260121`, Ninja 1.12.1. The vendor checkout revision is `76dac1b5754d17771f5a15acf0d4606e80164ea2`.

```powershell
powershell -NoProfile -ExecutionPolicy Bypass -File .\Build-Firmware.ps1
```

The migration build script uses bundled Git and creates `project/work/panel-test/build-migrated/`, avoiding the archived original build cache's absolute paths. Do not reuse `build/` on the new PC. The original `work/build-panel.ps1` is preserved as historical source and assumes system Git. If you move the package again after building, use a new build directory or remove only the disposable `build-migrated` directory after verifying its path. Do not delete the archived build.

Some historical preview, media and vendor-probing scripts contain the old username or Edge path. The portable media preparation script described below handles current media; archival experimental scripts are not the supported build entry point.

## Firmware and recovery

Installed/current release: `project/outputs/Resource-Panel/firmware/dashboard-movies-v3.bin`.
SHA256: `75AEC525CFAF081945918EC849013312C9163561432A1B804DCBC90FF78F9791`.

The existing board only needs the application at **0x10000**. Stop the companion and any serial terminal first:

```powershell
& .\project\work\panel-tools\Scripts\python.exe -m esptool --chip esp32p4 --port COM7 --baud 460800 write-flash --flash-mode dio --flash-size 16MB --flash-freq 80m 0x10000 .\project\outputs\Resource-Panel\firmware\dashboard-movies-v3.bin
```

Substitute `project/work/panel-test/build-migrated/5inch_Lesson09.bin` only after a successful new build. Restart the companion afterward. Do not erase all flash or flash the C6 radio as part of ordinary development.

Original P4 factory backup: `project/outputs/Panel-Recovery/elecrow-p4-v1-factory-backup.bin` (16 MB), SHA256 `5D5B6C9437E802AB09C00E48050198035139E6D17A66325358690804546D085F`. Its recovery documents are beside it. This is an original factory snapshot, **not a current NVS/bonding backup**, and does not contain C6/STC8 firmware or eFuses. The physical board retains those when moved. Replacing hardware requires additional consideration.

The archived build includes bootloader, partition table, initial OTA data, ELF/map and flasher arguments. Its documented layout is bootloader 0x2000, partition table 0x8000, OTA data 0xd000, app 0x10000. These extra images are for deliberate recovery, not routine app updates. Earlier binaries in outputs are preserved fallbacks/experiments, not the current release.

## Media and SD card

Current assets are in `project/outputs/Resource-Panel/video/movies-v3/`:

| State | Original | Board files |
|---|---|---|
| Awake idle | dayidle.mp4 | day3.rvj, day3.pcm |
| Sleep idle | nightidle.mp4 | nite3.rvj, nite3.pcm |
| Going to sleep | sleepytime.mp4 | sleep3.rvj, sleep3.pcm |
| Waking | wakeuptime.mp4 | wake3.rvj, wake3.pcm |

All eight belong in **`/BC250/` on the microSD**. They are already on the existing display's card. The package contains all project-generated card assets, but is not a byte-for-byte image of the card and does not copy unrelated card contents. No card adapter is needed just to move the display.

The two idle loops are 20.1 seconds; visible transitions are 5.2 seconds, with black video tails removed. Each file uses its **own audio**. The full approximately 7.8/9.13-second transition audio is retained and continues into idle before handing over to idle audio. The obsolete shared nature track belongs to v2 only.

RV01 is a 16-byte little-endian header (`<4sHHHHI`, magic, width, height, fps, reserved, frame count), then length-prefixed JPEG frames. Current frames are 800x480 at 10 fps, with 800x450 content letterboxed by 15 pixels. PCM is signed little-endian 16-bit, stereo, 16 kHz, 35% source gain. JPEG quality 28. All 506 frames were validated. Playback caches about 23.7 MB; loading takes about 47 seconds, while built-in artwork remains visible. Measured playback is about 10 fps.

`Prepare-Media.py` is the relocated version of the current conversion script. Run from the package root with the build Python. It reads the bundled external originals and writes a **new** `media-rebuilt/` directory, preserving all supplied originals and installed assets. It retains the original script separately in project/work. FFmpeg 7.1 is bundled through imageio-ffmpeg.

For serial card uploads use `project/outputs/Resource-Panel/upload_video.py --help`. Stop the companion first. Current firmware supports `--chunk-size 1024`, CRC32 per packet and SHA256 verification on finish. Uploads reject existing destinations and an existing `UPLOAD.TMP`; do not assume overwrite/resume. Existing `work/install-v3-assets.ps1` refers to COM10 and is historical. For a replacement card, a card reader and direct copy of the eight files is simplest. Keep the existing FAT filesystem; don't format a card with data you need.

Rejected procedural preview `preview-motion-v2-standalone.html` distorted the scene and was never installed. Preserve it as history, but use the user's current MP4s for further work.

## Windows temperature monitoring

The companion alone supplies CPU/RAM/disk usage. CPU temperature additionally needs LibreHardwareMonitor running with sensor access, generally elevated. Its app ZIP and extracted files are included, but the **.NET 10 Windows Desktop x64 runtime and PawnIO kernel-driver installation are system prerequisites**, not transferable by copying an app directory. The old PC has WindowsDesktop 10.0.11; the runtime inventory is included. Use the official runtime/helper installation prompts on the new PC if missing.

Enable LibreHardwareMonitor's Remote Web Server on port **8085**. The companion reads `http://127.0.0.1:8085/data.json`; its HTTP client bypasses proxies. The old application bound to `0.0.0.0`, which also listens on other interfaces. Keep access local with Windows Firewall if that is still the available binding. No LAN access is needed for this project.

The installed .NET 10 app's WMI namespace was unavailable; HTTP worked. The reader handles numeric and unit-bearing RawValue, Celsius/Fahrenheit and decimal commas, prefers CPU Package/Tctl/Tdie, excludes GPU/disk and distance-to-TjMax, and expires stale readings after 20 seconds. A background poll avoids blocking USB updates. User confirmed live temperature operation on the old PC.

The on-device Settings QR links to the official LibreHardwareMonitor releases page, not a hosted installer for the companion. Some on-device instructions still describe WMI and need updating to the working HTTP method. No automatic LHM installation or startup was implemented.

## Linux host use

The firmware and SD media do not change. A Linux companion still must be installed and run; it is not plug-and-play telemetry without host software. Copy `project/outputs/Resource-Panel` and create a Linux Python venv (the bundled Windows runtimes cannot run on Linux):

```sh
python3 -m venv .venv
.venv/bin/python -m pip install -r requirements.txt
.venv/bin/python resource_panel.py --list-ports
.venv/bin/python resource_panel.py --port /dev/ttyUSB0
```

Debian/Ubuntu may need `python3-venv` and serial membership in `dialout`; Arch/Omarchy commonly uses `uucp`. Check the device's actual owning group and log out/in after membership changes. Prefer `/dev/serial/by-id/...` for stable naming. Linux temperature collection uses psutil sensors plus thermal-zone fallback, subject to hardware/kernel support. No systemd service is supplied or installed. Physical validation on Linux is still pending.

## Hardware and unfinished work

Elecrow CrowPanel Advanced **5-inch ESP32-P4 V1.0**, 800x480 RGB panel. CH340 USB serial, normal 115200 baud; flashing/uploads 460800 when requested. UART GPIO38/37. Native USB audio/video is not implemented. The speaker/microphone board tests passed, but that does not make it a USB sound card for the host.

RGB clock 18 MHz; internal bounce buffers and correct frame-completion synchronization fixed earlier corruption/flashing. Native display byte swapping is disabled; JPEG video conversion applies its required byte swap separately. Avoid undoing one to fix the other. Resource float labels deliberately use libc snprintf rather than LVGL's formatter, which previously displayed literal `f`.

C6 hosted radio: SDMMC slot1 CLK53/CMD54/D0=52/D1=51/D2=50/D3=49, reset GPIO20; factory hosted firmware 2.3.0 uses a legacy initialization path. SD card: slot0 CLK43/CMD44/D0=39, one-bit 10 MHz. Do not casually change these shared peripheral settings.

GameSir Nova 2 Lite: G-Touch BLE mode Home+RB for 2 seconds (cyan); Home+Screenshot for rapid pairing. It appeared as `GameSir-Nova 2 Lite_G`. BLE scan, pairing and HID connection succeeded; **A/Home input reports did not**, and button-specific wake is unfinished. Firmware wakes the display on a new successful HID connection; reliable physical confirmation is still needed. Android Home+A/yellow mode was not successfully discovered. No BC250 power-switch relay output, standby-power integration or gamepad handoff is implemented.

The intended future chain is standby-powered panel + Bluetooth wake + isolated pulse across the BC250 starter's power-button contacts, with serial telemetry when the host is on. Consult `project/outputs/BC250-Omarchy-Runbook.html` for the hardware plan. Do not wire a GPIO directly to ATX power or infer a completed relay design from this software.

Commander Duo's two temperature probes and lightweight RGB control are **future work**. Linux OpenLinkHub was identified as a possible host-side backend, but no backend or display controls have been implemented or tested. Confirm the exact controller and USB connection, then integrate through the host companion. Keep pump/fan safety independent of display availability.

## Checks and next steps

The user reported the current dashboard working well, including usage and Windows temperature. Historical TEST-STATUS entries contain older pending items and superseded binaries; this handover identifies the current source. Detailed transition audio-tail behavior still merits a specific listening test.

After migration: verify files, run setup, start companion on the new port, confirm live CPU/RAM/disk readings, configure optional LHM temperature, then test sleep/wake and all four clips with sound. Allow a minute after power-up for card caching. Build before editing to establish a baseline. Continue next with controller input reports and power hardware, then Commander Duo integration.

## Excluded or nonportable dependencies

* Windows itself, system .NET runtimes, installed PawnIO/CH340 drivers, registry entries, device bindings, elevation state and firewall rules are **not cloned**. LHM app files are included; its drivers/runtime must be installed on the new PC if needed. Windows may install the CH340 driver automatically; otherwise obtain the manufacturer's driver.
* Edge/Chromium and its browser profile are not copied. Old procedural preview scripts expect system Edge; this is not needed to build firmware, run the companion or convert current MP4s.
* Global Git credentials/configuration, SSH keys, Wi-Fi credentials, unrelated Downloads and unrelated Codex sessions are not part of this project migration. Git program files and project repository metadata are included.
* Live board NVS/bonding, C6/STC8 firmware/eFuses, and unrelated SD files are not read back in this task. The existing hardware retains them. The original P4 factory backup and all known project media are included.
* Linux-native runtimes/packages and future OpenLinkHub/Commander Duo software are not bundled. Exact installed Windows Python package versions are recorded; their installed files are bundled, not a cross-platform wheelhouse.

No old-PC application, original media, source tree or tool installation has been deleted or disabled. Retire the old setup after the new PC passes the above device checks.

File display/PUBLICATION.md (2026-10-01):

# Public repository contents and private migration boundary

The panel package now lives in `display/`. Paths in the case-design section below are relative to the repository root; the [case-design guide](../case-design/README.md) is alongside this package.

## Case-design addition (2026-10-01)

`case-design/` adds the saved SolidWorks assembly and component files, neutral CAD files, display reference image, and all four delivered render folders (original, V2, V3 and V5). CAD and media binaries use Git LFS. `case-design/FILES-SHA256.json` records the imported files and their verified SHA-256 hashes. SolidWorks lock files and local `.codex` state are excluded. The original design folder is preserved. Third-party component models retain their existing rights; this addition assigns no blanket license to them.

This is a snapshot of saved files, not unsaved SolidWorks edits or a validated SolidWorks Pack and Go export. External assembly references have not been resolved by reopening the model on a clean machine. See the case-design README for portability limits.

## Panel software and migration package

The public repository contains the full application source, companion, managed component source, project configuration, firmware application versions, user-supplied media originals, generated artwork, conversion tools, tests, hardware runbook and handover. Large SDK/toolchain/runtime dependencies are attached to the pinned GitHub release rather than committed as Git objects.

The separate local migration package preserves the complete old setup, including the following **not published** items:

* Raw factory/full-flash recovery backups, which can contain device state outside the application.
* Serial/runtime/build logs, PID records and personal-machine telemetry.
* Original source-provenance manifest with personal absolute filesystem paths.
* Old build cache/objects, duplicate pip/uv/download caches, local editor state and repository reflogs.
* LibreHardwareMonitor's machine-specific settings. Obtain the app from its official release link in Settings or the handover; the local package also contains the original ZIP.

Account credentials, GitHub sign-in state, SSH keys and unrelated user files are never part of either project publication. Source copies generalize the old Windows username/path and controller address in documentation. Bundled Python environment configuration is deliberately reset and repaired by `Setup-Windows.ps1` after download.

Windows/.NET/PawnIO/USB-driver installations are not portable application folders. The new machine may need those system dependencies. Edge is optional for historical browser previews; it is not required for current video conversion or firmware builds.

The existing physical display retains its card and NVS/bonding state when moved. This repository is not a clone of every flash partition or every file on its microSD card.

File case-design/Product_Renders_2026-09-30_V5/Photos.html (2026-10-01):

BC250 / THE V5 COLLECTION

# Made to be seen.

Photorealistic studio imagery built from the SolidWorks assembly. Concealed RGB arrays, a 12-pixel foot strip, and the texture of upright 0.20 mm translucent PCTG layers.

60 seconds1920 × 1080 / 24 fpsOriginal music + sound design8 product photographs

## The cinematic showcase · Calm audio

The complete feature story, macro cutaways, RGB wake and sleep, and an original electronic score.

Download MP4Editable Blender project

## Made to Be Seen · Calm audio

A second creative treatment: grazing light, a closer hero reveal, a color triptych, and a new music and sound-design mix.

Download MP4Editable Blender project

## The all-sides showcase

The uninterrupted camera tour and feature captions, without music.

Download MP4Editable Blender project

## Product photography

Click an image for the full-resolution JPEG. Each photograph also has a 16-bit PNG master.

CyanNeutral whiteMagentaMintRGB rainbow

Cyan / dark studio

Cyan / dark studioPNG master

Neutral white / rear

Neutral white / rearPNG master

Magenta / dark studio

Magenta / dark studioPNG master

Mint / bright studio

Mint / bright studioPNG master

RGB rainbow / rear

RGB rainbow / rearPNG master

Display and power-ring detail

Display and power-ring detailPNG master

0.20 mm PCTG layer detail

0.20 mm PCTG layer detailPNG master

Neutral white / dark studio

Neutral white / dark studioPNG master

Photography studioProject notesPhoto overview

The V5 rings use 20× V3 output; the foot strip uses 8× V3 output. The commercial lighting is composed for the camera. The proposed foot strip and ring orientation are represented in Blender; SolidWorks files are unchanged. Keep the cinematic_assets and stills folders beside the Blender projects.

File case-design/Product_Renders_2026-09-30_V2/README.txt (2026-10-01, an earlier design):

BC250 — V2 PRODUCT SHOWCASE / CORRECTED LED OCCLUSION

Deliverables
• BC250_60s_Showcase.mp4 — 60 seconds, 1920 × 1080, 24 fps, H.264.
• stills — seven 16-bit PNG masters, 2400 × 2400 or 2600 × 1800.
• share-ready — matching full-resolution JPEGs, quality 95.
• BC250_Showcase_V2.blend — complete editable assembly, animation and captions.
• BC250_Showcase_Cycles.blend — original Cycles animation scene for alternate offline rendering.
• BC250_LED_Studio.blend — separate still-photography studio with the updated assembly and lighting.

Photo treatments
01 Cyan / dark hero
02 Amber / rear three-quarter
03 Magenta / dark hero
04 Mint / bright studio
05 Addressable RGB / rear three-quarter
06 Addressable RGB / display and power-button detail
07 Addressable RGB / PCTG surface detail

Film timing
00–03 Opening hero
03–10 Front view and 5.3-inch touch display / ESP32 / LED control / resource monitoring
10–16 Right side and four USB ports
16–22 Rear view and Wi-Fi 7 / BLE 5.3 via NVMe splitter
22–28 Elevated flyover and NVMe in the cooling airflow
28–34 Left side and Dual Arctic P9 PWM PST fans
34–41 Magnetic cover removal and reassembly
41–46 Bright studio and gamepad startup caption
46–49 Studio fades to dark
49–51 The two RGB arrays wake
51–55 Display wakes and the rainbow pattern moves through individual pixels
55–58 Display goes to sleep; LEDs dim to 8 percent
58–60 Dimmed hero and fade to black for looping

Blender scenes
01 | Dark studio
02 | Bright studio
03 | 60 second flyover — camera, lighting, RGB pixels, screen and covers
04 | Final film + feature captions — editable text and fades over Scene 03

Import and rendering notes
The current SolidWorks assembly was read without saving or changing the CAD files. All 79 visible component instances are represented. Both 24-pixel NeoPixel rings and ten additional magnets were imported. Changed geometry on the backbone and front, top and rear covers was also refreshed. Other existing mesh data was checked against the new export.

The ECAD ring models provide package footprints. Small raised packages and emitting diffusers were added at the 48 original CAD footprint centers, in the original component transforms. The older concept LED strip was removed. All 48 light helpers now cast shadows and sit just above the added diffuser surfaces, outside the PCB. The prior helper overlap with the PCB and the shadow bypass have been removed. The opaque PCB and aluminum backbone block light; visible illumination passes through actual gaps and perforations. LED intensity is composed for product photography and is not a calibrated prediction of physical lumen output.

The power-button ring and rear indicators remain illuminated. The original GUI image is packed in the Blender files. Its backlight, status indicator and sleep behavior are animated; this is not a live recording of the controller software.

Translucent PCTG keeps the 0.20 mm procedural surface layers. Wall panels use upright print orientation; the top cover is oriented as standing on its rear edge. These are surface-shader approximations rather than slicer toolpaths or simulated internal infill. Covers move for an illustrative exploded view and return to their imported positions.

As in V1, SolidWorks could not tessellate four small curved faces on the two fan components (about 330 square millimeters per fan). The remaining visible fan geometry is present. No new export warnings appeared.

Feature specifications and the fan/display wording follow the owner's supplied descriptions. Both stills and the film use Blender Cycles with ray-traced shadows and indirect light. Stills use 96 samples; animation uses 16 samples during motion and 48 on stationary holds, with denoising. All 48 emitting surfaces and matching shadow-casting helpers retain independent RGB animation. Both animation project files contain the corrected Cycles scene. Fonts and GUI artwork are packed. No external Python scripts are required to edit or render the saved scene.

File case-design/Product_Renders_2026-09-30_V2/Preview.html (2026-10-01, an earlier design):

PRODUCT SHOWCASE / V2 · UPDATED LIGHTING

# BC250

A 60-second tour. Two RGB arrays. Bright and dark studio photography.

Download the 1080p filmEditable Blender showcaseProject notes

BC250 front hero with cyan LEDs

01 · Cyan / dark hero

BC250 rear view with amber LEDs

02 · Amber / rear three-quarter

BC250 front hero with magenta LEDs

03 · Magenta / dark hero

BC250 in a bright studio with mint LEDs

04 · Mint / bright studio

BC250 rear view with multicolor RGB illumination

05 · Addressable RGB / rear

Backlit GUI and illuminated power ring detail

06 · Display and power-button detail

Translucent PCTG with procedural 0.20 mm print layers

07 · PCTG surface detail

JPEGs are ready to share. Full-resolution 16-bit PNG masters are in the stills folder. Geometry comes from the updated SolidWorks assembly; material and lighting approximations are documented in the project notes.

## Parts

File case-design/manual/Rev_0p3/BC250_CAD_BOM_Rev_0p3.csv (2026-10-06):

ID | CAD source | CAD quantity | Provisional class | Source-named PN | Purchased PN | Purchase status | Source links | Instances | Open notes
cad_5d363ea21b12 | 10x2_Magnet.SLDPRT | 6 | bought |  |  | unconfirmed |  | 10x2_Magnet-1 | 10x2_Magnet-2 | 10x2_Magnet-3 | 10x2_Magnet-4 | 10x2_Magnet-6 | 10x2_Magnet-5 | Modeled count is the active assembly count, not a purchased or final required quantity. | Dimension label comes from CAD basename; magnet grade/coating/polarity/retention and supplier PN are unconfirmed.
cad_8d5f897e6762 | 16mm_Power_Button.SLDPRT | 1 | bought |  |  | unconfirmed |  | 16mm_Power_Button-1 | Modeled count is the active assembly count, not a purchased or final required quantity.
cad_6d644622411d | 180degree_USB_Adapter.SLDPRT | 2 | bought |  |  | unconfirmed |  | 180degree_USB_Adapter-2 | 180degree_USB_Adapter-3 | Modeled count is the active assembly count, not a purchased or final required quantity.
cad_770e1006735b | 6x3_Magnet.SLDPRT | 14 | bought |  |  | unconfirmed |  | 6x3_Magnet-3 | 6x3_Magnet-4 | 6x3_Magnet-9 | 6x3_Magnet-10 | 6x3_Magnet-8 | 6x3_Magnet-7 | 6x3_Magnet-13 | 6x3_Magnet-15 | 6x3_Magnet-11 | 6x3_Magnet-12 | 6x3_Magnet-14 | 6x3_Magnet-16 | 6x3_Magnet-1 | 6x3_Magnet-2 | Modeled count is the active assembly count, not a purchased or final required quantity. | Owner requests additional 6 x 3 magnets; extra quantity and final magnet specification remain open. | Dimension label comes from CAD basename; magnet grade/coating/polarity/retention and supplier PN are unconfirmed.
cad_cc9b0a25d7ac | 80mm_Fan_Grill.SLDPRT | 1 | printed |  |  | unconfirmed |  | 80mm_Fan_Grill-1 | Modeled count is the active assembly count, not a purchased or final required quantity.
cad_bbb76eda1cce | 90718A110_High-Strength Glass-Filled Nylon Plastic Washer.SLDPRT | 3 | bought | 90718A110 |  | unconfirmed | https://www.mcmaster.com/products/shims/thickness~0-500-mm/thickness~0-5-mm/ | 90718A110_High-Strength Glass-Filled Nylon Plastic Washer-1 | 90718A110_High-Strength Glass-Filled Nylon Plastic Washer-2 | 90718A110_High-Strength Glass-Filled Nylon Plastic Washer-3 | Modeled count is the active assembly count, not a purchased or final required quantity.
cad_ebda0ab48c7d | 92MM_Arctic_PST_FAN.SLDPRT | 2 | bought |  |  | unconfirmed | https://www.arctic.de/en/P9-PWM-PST-Black/ACFAN00298A | 92MM_Arctic_PST_FAN-1 | 92MM_Arctic_PST_FAN-2 | Modeled count is the active assembly count, not a purchased or final required quantity. | P9 ACFAN00298A is a primary product candidate; generic Arctic PST CAD filename does not prove this purchased SKU.
cad_5a28d4baaf93 | 92MM_Arctic_PST_Split_Insert.SLDPRT | 2 | printed |  |  | unconfirmed |  | 92MM_Arctic_PST_Split_Insert-2 | 92MM_Arctic_PST_Split_Insert-1 | Modeled count is the active assembly count, not a purchased or final required quantity.
cad_0f109b8e4c7a | 93657A009_Nylon Unthreaded Spacer.SLDPRT | 3 | bought | 93657A009 |  | unconfirmed | https://www.mcmaster.com/products/94639A258/ | 93657A009_Nylon Unthreaded Spacer-2 | 93657A009_Nylon Unthreaded Spacer-1 | 93657A009_Nylon Unthreaded Spacer-3 | Modeled count is the active assembly count, not a purchased or final required quantity.
cad_e4d8bb1694b8 | 93886A220_Reinforced Plastic Knurled-Head Thumb Nut.SLDPRT | 3 | bought | 93886A220 |  | unconfirmed | https://www.mcmaster.com/products/knurled-thumb-screw-nuts/ | 93886A220_Reinforced Plastic Knurled-Head Thumb Nut-2 | 93886A220_Reinforced Plastic Knurled-Head Thumb Nut-1 | 93886A220_Reinforced Plastic Knurled-Head Thumb Nut-3 | Modeled count is the active assembly count, not a purchased or final required quantity.
cad_dc7f205830dd | 94180A333_Brass Tapered Heat-Set Inserts for Plastic.SLDPRT | 8 | bought | 94180A333 |  | unconfirmed | https://www.mcmaster.com/products/ultrasonic-inserts/ | 94180A333_Brass Tapered Heat-Set Inserts for Plastic-1 | 94180A333_Brass Tapered Heat-Set Inserts for Plastic-5 | 94180A333_Brass Tapered Heat-Set Inserts for Plastic-6 | 94180A333_Brass Tapered Heat-Set Inserts for Plastic-4 | 94180A333_Brass Tapered Heat-Set Inserts for Plastic-3 | 94180A333_Brass Tapered Heat-Set Inserts for Plastic-8 | 94180A333_Brass Tapered Heat-Set Inserts for Plastic-2 | 94180A333_Brass Tapered Heat-Set Inserts for Plastic-7 | Modeled count is the active assembly count, not a purchased or final required quantity. | Owner states modeled heat-set inserts may not be final; final PN, dimensions, holes and quantity remain open.
cad_4b6ba0b506c2 | Apevia_500_SFX.SLDPRT | 1 | bought |  |  | unconfirmed |  | Apevia_500_SFX-1 | Modeled count is the active assembly count, not a purchased or final required quantity.
cad_0af6f34f1220 | Backbone.SLDPRT | 1 | custom |  |  | unconfirmed |  | Backbone-1 | Modeled count is the active assembly count, not a purchased or final required quantity. | Sheet-metal manufacture is owner-confirmed; exact alloy, thickness, fabrication source and final drawing remain open.
cad_e99f1dd5efea | bc250_after_heatsink_mod.step.SLDPRT | 1 | custom |  |  | unconfirmed |  | bc250_after_heatsink_mod.step-3 | Modeled count is the active assembly count, not a purchased or final required quantity. | Custom/modified geometry; source assembly instance is not a retail part number. Fabrication process and final revision remain unconfirmed.
cad_4dd575723499 | bc250_am4_adapter_mount_v1.SLDPRT | 1 | custom |  |  | unconfirmed |  | bc250_am4_adapter_mount_v1-1 | Modeled count is the active assembly count, not a purchased or final required quantity. | Custom/modified geometry; source assembly instance is not a retail part number. Fabrication process and final revision remain unconfirmed. | Decompose the imported subassembly into fabricated parts and required hardware; reconcile against top-level washers, spacers and thumb nuts to avoid double-counting. Modeled component count remains one.
cad_3f9bb53cd308 | Dual_92MM_FAN_Shroud.SLDPRT | 1 | printed |  |  | unconfirmed |  | Dual_92MM_FAN_Shroud-1 | Modeled count is the active assembly count, not a purchased or final required quantity.
cad_69b1461d44c0 | ESP32-P4-5_0-inch-20251230.stp.SLDPRT | 1 | bought |  |  | unconfirmed | https://www.elecrow.com/crowpanel-advanced-5inch-esp32-p4-hmi-ai-display-800x480-ips-touch-screen-with-wifi-6.html | ESP32-P4-5_0-inch-20251230.stp-2 | Modeled count is the active assembly count, not a purchased or final required quantity. | Elecrow model identity supported; exact physical revision/options, GPIO harness and mounting fit need confirmation.
cad_7190ca57490e | Front_Cover.SLDPRT | 1 | printed |  |  | unconfirmed |  | Front_Cover-1 | Modeled count is the active assembly count, not a purchased or final required quantity.
cad_57be749e2d42 | Left_Apron.SLDPRT | 1 | printed |  |  | unconfirmed |  | Left_Apron-1 | Modeled count is the active assembly count, not a purchased or final required quantity.
cad_8c980fa3a192 | M2_Splitter.SLDPRT | 1 | bought |  |  | unconfirmed |  | M2_Splitter-1 | Modeled count is the active assembly count, not a purchased or final required quantity.
cad_d2362404ca8e | M3x16_91294A134_Black-Oxide Alloy Steel Hex Drive Flat Head Screw.SLDPRT | 3 | bought | 91294A134 |  | unconfirmed | https://www.mcmaster.com/products/flat-head-screws/specifications-met~din-7991/ | M3x16_91294A134_Black-Oxide Alloy Steel Hex Drive Flat Head Screw-1 | M3x16_91294A134_Black-Oxide Alloy Steel Hex Drive Flat Head Screw-2 | M3x16_91294A134_Black-Oxide Alloy Steel Hex Drive Flat Head Screw-3 | Modeled count is the active assembly count, not a purchased or final required quantity. | Owner requests different M3 countersunk bolts; replacement PN, length, head geometry and final quantity remain open.
cad_c7528557a862 | M3x45_91420A138_Steel Phillips Flat Head Screws.SLDPRT | 8 | bought | 91420A138 |  | unconfirmed | https://www.mcmaster.com/91420A138/ | M3x45_91420A138_Steel Phillips Flat Head Screws-5 | M3x45_91420A138_Steel Phillips Flat Head Screws-1 | M3x45_91420A138_Steel Phillips Flat Head Screws-2 | M3x45_91420A138_Steel Phillips Flat Head Screws-3 | M3x45_91420A138_Steel Phillips Flat Head Screws-4 | M3x45_91420A138_Steel Phillips Flat Head Screws-8 | M3x45_91420A138_Steel Phillips Flat Head Screws-6 | M3x45_91420A138_Steel Phillips Flat Head Screws-7 | Modeled count is the active assembly count, not a purchased or final required quantity. | Owner requests different M3 countersunk bolts; replacement PN, length, head geometry and final quantity remain open.
cad_6ab458265e62 | PanelMnt_SMA_Antenna_Cable.SLDPRT | 2 | bought |  |  | unconfirmed |  | PanelMnt_SMA_Antenna_Cable-2 | PanelMnt_SMA_Antenna_Cable-1 | Modeled count is the active assembly count, not a purchased or final required quantity.
cad_001439195b30 | rainbow-matchstick-diffuser.SLDPRT | 2 | printed |  |  | unconfirmed |  | rainbow-matchstick-diffuser-2 | rainbow-matchstick-diffuser-1 | Modeled count is the active assembly count, not a purchased or final required quantity.
cad_a2d7b506c6d9 | Rainbow_Matchstick.step.SLDPRT | 2 | bought |  |  | unconfirmed | https://github.com/VoronDesign/Voron-Hardware/tree/master/Daylight/Rainbow_on_a_matchstick | Rainbow_Matchstick.step-5 | Rainbow_Matchstick.step-4 | Modeled count is the active assembly count, not a purchased or final required quantity. | Chosen positions exist in CAD, but mounting, connectors, harness, display output and power/current budget are unresolved.
cad_e6f58f0613fe | Rear_Cover_Whole.SLDPRT | 1 | printed |  |  | unconfirmed |  | Rear_Cover_Whole-1 | Modeled count is the active assembly count, not a purchased or final required quantity.
cad_3cf2ecf0674e | Right_Apron.SLDPRT | 1 | printed |  |  | unconfirmed |  | Right_Apron-1 | Modeled count is the active assembly count, not a purchased or final required quantity.
cad_f49a6b79ecc5 | snowman_mc75-8_heatsink_v1.SLDPRT | 1 | bought |  |  | unconfirmed |  | snowman_mc75-8_heatsink_v1-1 | Modeled count is the active assembly count, not a purchased or final required quantity.
cad_35bc922ba3c7 | Speaker.SLDPRT | 2 | bought |  |  | unconfirmed |  | Speaker-2 | Speaker-1 | Modeled count is the active assembly count, not a purchased or final required quantity.
cad_a3f594caf952 | SSD_M2_2230.SLDPRT | 2 | bought |  |  | unconfirmed |  | SSD_M2_2230-1 | SSD_M2_2230-2 | Modeled count is the active assembly count, not a purchased or final required quantity.
cad_124f6fc1c790 | SSD_M2_2280.SLDPRT | 1 | bought |  |  | unconfirmed |  | SSD_M2_2280-1 | Modeled count is the active assembly count, not a purchased or final required quantity.
cad_5429a83cd569 | Stubby_SMA_Wifi_Antenna.SLDPRT | 2 | bought |  |  | unconfirmed |  | Stubby_SMA_Wifi_Antenna-1 | Stubby_SMA_Wifi_Antenna-2 | Modeled count is the active assembly count, not a purchased or final required quantity.
cad_6e2a9d87d639 | Top_Cover.SLDPRT | 1 | printed |  |  | unconfirmed |  | Top_Cover-2 | Modeled count is the active assembly count, not a purchased or final required quantity.
cad_8a5caa14b72d | USB_Hub.SLDPRT | 1 | bought |  |  | unconfirmed |  | USB_Hub-1 | Modeled count is the active assembly count, not a purchased or final required quantity.

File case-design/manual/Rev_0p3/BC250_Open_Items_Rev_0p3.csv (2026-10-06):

ID | Item | Modeled baseline | Additional/final qty | Final PN | Status | Confirmation needed
additional_6x3_magnets | Additional 6 x 3 magnets | 14 | TBD |  | open | Additional quantity, grade, coating, polarity/orientation and retention fit.
m3_countersunk_replacements | Different M3 countersunk bolts | 11 | TBD |  | open | Length, head angle/diameter, drive, grade, quantity, thread engagement and countersink fit; existing model has 3 x16 and 8 x45.
threaded_magnets | Owner-requested 3 mm threaded magnets | 0 | TBD |  | open | Clarify M3 thread versus 3 mm body size, male/female thread, envelope, quantity, mounting and polarity.
final_heatsets | Final heat-set inserts | 8 | TBD |  | open | Final PN, thread, OD/length, hole geometry, insertion method, quantity and pull-out test.
display_led_harness | Display to LED bar 1 to LED bar 2 harness | 0 | TBD |  | open | Display output GPIO/header mapping, logic levels, +5V source/budget, common ground, LED revision pinout, connector housings/crimps, wire gauge, lengths, keyed orientation and test.
led_mounting | Mounts/fasteners/clips for two chosen LED positions | 0 | TBD |  | open | Support surfaces, hole alignment, insulated clearance, insert/bolt selection, connector access, diffuser retention and service removal; no mount validated.
usb_extensions | USB extension cables | 0 | TBD |  | open | Connector genders, USB speed/power requirements, length, bend radius, panel retention and exact quantity.
usb_right_angle | 90 degree USB-C to USB-A cable | 0 | TBD |  | open | Connector genders/orientation, data capability, cable length, bend clearance, strain relief and exact quantity; separate from two modeled 180-degree USB adapters.
optional_p12 | Possible ARCTIC P12 Slim PWM PST | 0 | TBD |  | open | Selection/quantity, airflow direction, 120 x120 x15 mm clearance, hole pattern, fan power/header budget, wiring and mount validation.
mosfet_distribution | Mosfet.Party EPS power distribution adapter | 0 | TBD |  | open | Confirm product/revision/quantity, PSU cable compatibility, board bounds, mounting, both BC250 power paths and harness retention.
mosfet_ps_on | Mosfet.Party PS_ON control adapter | 0 | TBD |  | open | Confirm ATX button/header versus LITE variant, board bounds/holes, button/LED connector pinout, PSU and BC250 sense wiring, quantity and mounting.
psu_cable_management | Excess PSU cable retention | 0 | TBD |  | open | Choose case anchor/tie-point locations, zip-tie/mount PN/quantity, routing, bend radius, insulation, fan clearance and service slack.
small_cable_management | Small/USB/LED/audio cable retention | 0 | TBD |  | open | Choose separate anchor/tie-point locations, zip ties/mounts/retainers, lengths, strain relief, connector access and service slack.
speakers | Speaker wiring and final speaker parts | 2 | TBD |  | open | Exact speaker PN/impedance/rating, PH2.0 housing/pin orientation, harness length, mounting and clearance.
wireless_identity | Wireless card and antenna identity | 0 | TBD |  | open | No explicitly named wireless card instance; confirm installed card PN, interface, adapter and antenna/bulkhead cable identities from owner evidence.
nvme_splitter_identity | M.2 splitter identity | 1 | TBD |  | open | Manufacturer/PN, topology/interface compatibility, power, mounting and attached devices; generic CAD filename cannot establish exact purchased splitter.
storage_identity | Final SSD identities | 3 | TBD |  | open | PN/capacity/interface and role for 2 modeled 2230 and 1 modeled 2280 bodies.
usb_hub_identity | USB hub identity | 1 | TBD |  | open | Exact PN, ports/speed, power source, cable and mounting.
psu_identity | PSU identity and cable set | 1 | TBD |  | open | Apevia 500 SFX filename only; confirm exact label PN/revision, connectors/pinouts and cable gauges.
am4_custom_subassembly_bom | Decompose the custom AM4 adapter subassembly | 1 | TBD |  | open | One imported custom CAD component contains 19 exported bodies. Identify fabricated parts and separately required hardware, checking against top-level washers, spacers and thumb nuts to avoid double-counting. Manufacturing/material and final physical quantities remain open; do not decompose bought board/PSU chips into separate purchases.
remaining_items | Other owner-mentioned missing components |  | TBD |  | open | Owner to identify remaining components; inventory is not a purchasing checklist.

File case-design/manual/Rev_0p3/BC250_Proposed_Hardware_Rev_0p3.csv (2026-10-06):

Proposal ID | Item | Role | Kind | Owner proposed quantity | Unit | Quantity basis | Proposed specification | Related CAD IDs / modeled counts | Reconciliation status | Family arithmetic only | Final quantity | Purchased quantity | Purchased PN | Open notes
proposal_heatsets_fan_inserts | Fan-insert heat-set inserts | Four in each of two 92 mm fan inserts | hardware | 8 | piece | explicit_owner_quantity | {"thread": "M3 candidate; final insert selection open", "per_insert": 4, "insert_count": 2} | cad_dc7f205830dd: 8 | cad_5a28d4baaf93: 2 | owner_count_matches_candidate_cad_family | 0 |  |  |  | Owner scope explicitly establishes eight. The CAD has eight 94180A333-named heatsets, but source-named PN is not a final purchased selection. | Verify insert geometry, thread, plastic hole/installation fit and screw engagement before ordering.
proposal_heatsets_filter_mounts | Future fan-filter mount heat-set inserts | Filter mounts not yet designed | hardware | 4 | piece | explicit_owner_quantity | {"thread": "not finalized", "mount_design": "absent/unresolved"} | cad_dc7f205830dd: 8 | additional_proposed_allocation_not_modeled_as_filter_mounts |  |  |  |  | Separate proposed allocation of four; do not allocate the same eight modeled inserts twice. | The additional filter mounts, insert selection and joints require design. Aggregate proposal is twelve inserts versus eight modeled, a planning difference of four only.
proposal_fan_filter_mounts | Printed fan-filter mounts | Bottom of backbone | custom_part |  | piece | not_specified | {"design_status": "not yet designed"} |  | no_separately_named_cad_row |  |  |  |  | Number of mount pieces and all mount-to-backbone fastener quantities remain unstated. | Four proposed filter heatsets do not establish four physical mounts.
proposal_magnets_6x3 | 6 x 3 magnets in printed parts | Magnetic cover/apron retention | hardware |  | piece | not_specified | {"owner_size_label_mm": "6x3"} | cad_770e1006735b: 14 | related_cad_rows_require_role_and_spec_confirmation |  |  |  |  | Owner gives no total quantity or distribution. Keep the fourteen actual modeled instances unchanged; do not use maximum suffix 16 as a count. | Extra magnets were an earlier owner open item; supplier grade/coating/polarity, hole fit and retention remain open.
proposal_magnets_10x2 | 10 x 2 magnets in printed parts | Magnetic retention | hardware |  | piece | not_specified | {"owner_size_label_mm": "10x2"} | cad_5d363ea21b12: 6 | related_cad_rows_require_role_and_spec_confirmation |  |  |  |  | Owner gives no total quantity or distribution. Keep six modeled instances unchanged. | The source name does not establish that these six are the six threaded magnets later requested.
proposal_threaded_magnets | Threaded magnets on backbone | Rear-cover magnetic retention | hardware | 6 | piece | explicit_owner_quantity | {"thread": "M3 requested in earlier owner open item; exact purchased thread and body dimensions unconfirmed", "body_size_mm": null} | cad_5d363ea21b12: 6 | threaded_identity_and_cad_role_unresolved |  |  |  |  | Six is an owner-proposed requirement, not six verified additional purchases. | The six generic 10x2 modeled magnets are not proof of six threaded magnets; distinguish by actual drawings and purchased revision before replacing or adding rows. | Exact size, polarity, thread depth and countersunk attachment geometry remain open.
proposal_threaded_magnet_fasteners | Countersunk bolts for threaded magnets | Front of backbone into rear threaded magnets | hardware |  | piece | not_specified | {"head": "countersunk", "thread": null, "length_mm": null} |  | no_separately_named_cad_row |  |  |  |  | Six threaded magnets do not authorize inventing an explicit bolt quantity in this reconciliation. | Check exact magnet thread, depth, countersink, sheet thickness and clearance.
proposal_bc250_spacers | 6 mm BC250 spacers | Three board mounting positions | hardware | 3 | piece | explicit_owner_quantity | {"length_mm": 6, "threaded_or_unthreaded": "unresolved"} | cad_0f109b8e4c7a: 3 | cad_d2362404ca8e: 3 | cad_e4d8bb1694b8: 3 | count_matches_but_joint_and_spacer_type_unresolved | 0 |  |  |  | Three modeled 93657A009 parts are explicitly Nylon Unthreaded Spacer with a 6 mm local envelope. | Owner proposes rear countersunk bolts plus separate front M3x8 screws. Resolve the complete joint stack and where each screw engages; do not silently treat an unthreaded spacer as a threaded standoff. | Final material, insulation, length, screw thread engagement and stand-off clearance need confirmation.
proposal_bc250_spacer_rear_bolts | Rear countersunk bolts for BC250 spacer joint | Rear of backbone | hardware |  | piece | not_specified | {"head": "countersunk", "thread": null, "length_mm": null} | cad_d2362404ca8e: 3 | related_cad_rows_require_role_and_spec_confirmation |  |  |  |  | Owner gives three spacer positions but does not state rear-bolt quantity or length. | Determine the complete spacer/bolt/nut arrangement without double-counting existing M3x16 screws and thumb nuts.
proposal_bc250_mount_m3x8 | BC250-to-spacer screws | Board attachment to three 6 mm spacers | hardware | 3 | piece | explicit_owner_quantity | {"thread": "M3", "length_mm": 8, "head": "not specified"} | cad_0f109b8e4c7a: 3 | cad_d2362404ca8e: 3 | new_specification_needs_joint_reconciliation |  |  |  |  | Root task explicitly clarifies three M3x8 screws. No separately named M3x8 row is present in the top-level CAD BOM. | Verify engagement, protrusion, electrical insulation and whether the spacer joint is threaded; do not silently replace three modeled M3x16 screws.
proposal_fan_shroud_m3x45 | Fan/shroud countersunk screws | Eight fan holes | hardware | 8 | piece | explicit_owner_quantity | {"thread": "M3", "length_mm": 45, "head": "countersunk"} | cad_c7528557a862: 8 | owner_count_and_nominal_size_match_cad | 0 |  |  |  | Owner specifies all eight holes. CAD contains eight M3x45 91420A138-named screws. | This verifies quantity/name correspondence only; head standard, chosen replacement SKU, length through the stack and heatset engagement are not physically validated.
proposal_psu_mount_candidate | PSU mounting screws: M3x8 candidate OR supplied screws | Apevia 500 W SFX to backbone | hardware | 4 | piece | explicit_owner_quantity | {"candidate_thread": "M3", "candidate_length_mm": 8, "candidate_head": "countersunk", "alternative": "screws supplied with exact PSU", "actual_psu_thread": null} | cad_4b6ba0b506c2: 1 | owner_count_known_psu_thread_and_screw_spec_unconfirmed |  |  |  |  | Do not approve M3 based on this proposal. Actual Apevia SKU, housing thread and allowable screw penetration are unverified. | Four candidate screws and four supplied screws are alternatives, not eight required screws. | No separately named M3x8 row exists in the baseline.
proposal_psu | Apevia 500 W SFX PSU | Primary power supply | hardware | 1 | piece | explicit_owner_quantity | {"owner_brand": "Apevia", "power_w": 500, "form_factor": "SFX", "exact_sku": null} | cad_4b6ba0b506c2: 1 | related_cad_rows_require_role_and_spec_confirmation |  |  |  |  | CAD name and owner description correspond, but exact purchased model/revision and supplied hardware remain unconfirmed. | Apevia selection does not establish compatibility with the Mosfet.Party FSP500-30AS plug-and-play variant.
proposal_iec_90_adapter | 90 degree IEC adapter | PSU inlet, facing rear as proposed | hardware | 1 | piece | explicit_singular_owner_item | {"angle_degrees": 90, "connector_standard": null, "current_voltage_rating": null} |  | no_separately_named_cad_row |  |  |  |  | A single adapter is proposed. Confirm exact PSU inlet, orientation, earth continuity, rating, clearance and retention; no exact PN or separately named CAD row is established.
proposal_fans_92 | 92 mm fans | Two shroud fans | hardware | 2 | piece | explicit_owner_quantity | {"nominal_size_mm": 92, "exact_sku": null} | cad_ebda0ab48c7d: 2 | related_cad_rows_require_role_and_spec_confirmation |  |  |  |  | Two owner fan cables correspond to two modeled 92MM_Arctic_PST_FAN instances. | P9 ACFAN00298A is a manufacturer-supported candidate, not a confirmed purchased identity. Airflow direction and final wiring require physical checks.
proposal_fan_120 | 120 mm fan | Third fan connected to splitter | hardware | 1 | piece | explicit_owner_quantity | {"nominal_size_mm": 120, "exact_sku": null, "thickness_mm": null} | cad_f49a6b79ecc5: 1 | owner_quantity_known_exact_fan_and_overlap_unresolved |  |  |  |  | Owner specifies one 120 mm fan. P12 Slim PWM PST remains a candidate, not a final selection. | Check whether the cooler's 79-body CAD component represents/bundles the same fan before counting an additional purchased fan. | Fan mounting, current, airflow, blade clearance and retention remain open.
proposal_fan_splitter_3_to_1 | Three-to-one fan splitter | Two 92 mm fans plus one 120 mm fan to CPU FAN | hardware | 1 | piece | explicit_singular_owner_item | {"fan_outputs": 3, "board_input": "CPU FAN as owner-proposed", "part_number": null} | cad_5a28d4baaf93: 2 | no_electrical_splitter_row_and_electrical_limits_open |  |  |  |  | The printed 92MM_Arctic_PST_Split_Insert is not an electrical fan splitter. The M2_Splitter is also unrelated. | Verify BC250 header pinout/rating, all actual fan startup/current labels, splitter power/PWM/tach implementation and one appropriate tach return before approval. | Conditional two P9 plus one P12 Slim manufacturer-listed running current is 0.36 A; that arithmetic does not establish header safety.
proposal_stock_heatsink_screws_remove | Original stock heatsink screws removed and retained | Handling of existing BC250 hardware | reused_hardware | 8 | piece | explicit_owner_quantity | {"original_thread_length": null} | cad_e99f1dd5efea: 1 | owner_retained_hardware_count_only |  |  |  |  | Owner says eight; creator exact instructions are not independently confirmed here. This is a retained-hardware handling count, not a new purchase requirement. | Do not overwrite this owner-specific count with a generic guide's different count.
proposal_stock_outer_sink_screws_reuse | Original screws reused for outer heatsink sections | Two outer stock sink sections | reused_hardware | 4 | piece | explicit_owner_quantity | {"springs": "removed as owner-proposed", "actual_thread_length": null} | cad_e99f1dd5efea: 1 | subset_of_retained_eight_not_new_purchase |  |  |  |  | These four are a subset of the eight retained screws, not four extra new screws. Remaining retained screw uses are not established. | Confirm actual stock screw engagement, retention and PCB load; no creator-verifiable screw/thread data was obtained.
proposal_stock_outer_sink_washers | M3 washers behind PCB for outer sink sections | Four reused stock-screw positions | hardware | 4 | piece | explicit_owner_quantity | {"nominal_screw_size": "M3", "material": null, "outer_diameter_mm": null, "thickness_mm": null} | cad_bbb76eda1cce: 3 | owner_four_vs_modeled_three_role_unresolved | 1 |  |  |  | Four is the owner proposal; only three 90718A110-named glass-filled nylon washers are separately modeled. | Arithmetic difference is one at washer-family level only. Their CAD role may differ; no purchased increment or PN equivalence is established. | Confirm electrical insulation, dimensions, hardware-stack pressure and locations before reusing the modeled washer SKU.
proposal_rear_sink_adapter_m3 | M3 screws for rear center heatsink through cooler adapter | Rear VRAM sink attachment | hardware |  | piece | not_specified | {"thread": "M3 proposed", "length_mm": null, "head": null} | cad_4dd575723499: 1 | related_cad_rows_require_role_and_spec_confirmation |  |  |  |  | Quantity and length are not stated; no count is invented from a figure or imported bodies. | Adapter component contains nineteen exported bodies. Decompose fabricated parts and embedded hardware, checking existing top-level screws, washers, spacers and thumb nuts to avoid double-counting. | Confirm stock sink thread, engagement and PCB pressure; exact creator screw/thread instructions remain unconfirmed.
proposal_cooler_mount_hardware | Cooler's stainless mounting hardware | APU cooler to AM4 adapter | hardware |  | piece | not_specified | {"owner_material_description": "stainless mounts", "interface": "exact cooler/adapter revision unconfirmed"} | cad_f49a6b79ecc5: 1 | cad_4dd575723499: 1 | related_cad_rows_require_role_and_spec_confirmation |  |  |  |  | Owner states use of the cooler's mounts but gives no quantity, screw length, thread, bracket revision or tightening specification. | Creator explicitly tested only one heatsink; generic AM4 identity does not certify all cooler hardware. | Separate bundled hardware from new purchases during adapter sub-BOM decomposition.
proposal_utp6_front | Upsiren UTP-6 thermal putty: front components | Outer sink contact regions | consumable |  | gram | not_specified | {"owner_brand_product": "Upsiren UTP-6", "initial_deposit_height_mm": 4, "compressed_gap_mm": null, "coverage_map": "record actual original contact regions"} |  | no_separately_named_cad_row |  |  |  |  | Four millimetres is an initial deposit before compression, not a measured final gap or bondline. | Mass, volume, exact coverage, compatibility, pressure and final contact are unconfirmed. No dose is invented.
proposal_utp6_rear | Upsiren UTP-6 thermal putty: rear VRAM | Rear VRAM to reused center sink | consumable |  | gram | not_specified | {"initial_ball_height_mm": 6, "initial_ball_count": null, "initial_rule": "one per actual VRAM module", "compressed_gap_mm": null} |  | no_separately_named_cad_row |  |  |  |  | Six millimetres is initial ball height before compression. Owner provides no chip count; no number of balls or mass is inferred. | Measure/validate final contact, sink clearance and pressure before a final material quantity or installation procedure.
proposal_mx6_apu | Arctic MX-6 thermal paste | APU interface | consumable |  | gram | not_specified | {"owner_product_recommendation": "Arctic MX-6", "dose_g": null} |  | no_separately_named_cad_row |  |  |  |  | Owner recommendation only; selected pack size and application dose are unstated. Do not substitute thermal putty at the APU interface based on these rows.
proposal_ipa | 99% IPA | Thermal interface cleaning | consumable |  | millilitre | not_specified | {"owner_concentration_percent": 99} |  | no_separately_named_cad_row |  |  |  |  | No volume, procedure approval or final material compatibility is established.
proposal_microfiber | Soft microfiber cloth | Owner-proposed APU cleaning | consumable |  | piece | not_specified | {} |  | no_separately_named_cad_row |  |  |  |  | No explicit quantity or validated cleaning method is supplied.
proposal_microsd | Display microSD card | Display assets | hardware | 1 | piece | explicit_singular_owner_item | {"owner_capacity_text": "16-32GB minimum", "selected_capacity_gb": null, "filesystem": null, "speed_class": null} |  | no_separately_named_cad_row |  |  |  |  | Single card is stated. Preserve the owner's ambiguous capacity phrase; do not silently turn it into a confirmed upper limit or format requirement. | Confirm exact firmware/file layout, card compatibility and selected capacity separately.
proposal_display_usb_90 | 90 degree USB cable to display UART0 | Host display connection | hardware | 1 | piece | explicit_singular_owner_item | {"angle_degrees": 90, "owner_destination_label": "UART0", "exact_connector_and_orientation": null} | cad_69b1461d44c0: 1 | cad_6d644622411d: 2 | no_exact_90_degree_cable_row |  |  |  |  | A cable is proposed, not one of the two modeled 180 degree USB adapters. | Confirm physical connector, power/data routing, length and bend direction on exact display revision; UART0 alone is not a cable PN.
proposal_led_boards | Left and right Matchstick LED boards | Owner's left-first, right-second chain intent | hardware | 2 | piece | owner_describes_left_and_right_boards | {"owner_chain_intent": ["left", "right"], "validated_din_dout_orientation": null} | cad_a2d7b506c6d9: 2 | related_cad_rows_require_role_and_spec_confirmation |  |  |  |  | Two native CAD Matchstick boards remain two; no new board geometry is proposed here. | Physical top/bottom is not proof of DIN/DOUT. Exact purchased revision, voltage, pin order, logic and chain orientation still need validation. | Manual figure callout numbers are component identifiers and do not determine the electrical chain order.
proposal_led_diffusers | Matchstick diffusers | Covers on LED boards | hardware |  | piece | not_specified | {"exact_revision": null} | cad_001439195b30: 2 | related_cad_rows_require_role_and_spec_confirmation |  |  |  |  | Two diffusers are modeled. Owner gives no separate purchase/fabrication count or final mounting specification in this paragraph.
proposal_led_mounts | LED mounts/brackets | Support two Matchsticks at chosen positions | custom_part |  | piece | not_specified | {"design_status": "mounting unresolved"} |  | no_separately_named_cad_row |  |  |  |  | No mount piece count or final manufactured design is given. LED positions are chosen, but support has not been validated. | Reference PCB two M3-capable plated-ground holes and outline data are design references, not a purchased-revision pinout/mount approval. | Do not clamp LED faces or rely on connector cables for support. Check case clearance and removable support concept.
proposal_led_board_mount_m3 | M3 screws for Matchstick/diffuser to mounts | LED assembly attachment | hardware |  | piece | not_specified | {"thread": "M3 proposed", "length_mm": null, "head": null} | cad_a2d7b506c6d9: 2 | cad_001439195b30: 2 | related_cad_rows_require_role_and_spec_confirmation |  |  |  |  | Owner does not state quantity; two reference PCB holes per board are not a final fastener count. | Confirm exact hole revision, plated-ground contact, electrical isolation if needed, standoff stack and diffuser clearance.
proposal_led_mount_backbone_bolts | Bolts for LED mounts to backbone | Bracket attachment | hardware |  | piece | not_specified | {"thread": null, "length_mm": null, "head": null} |  | no_separately_named_cad_row |  |  |  |  | Count and size are unspecified. No holes, anchors or hardware are fabricated by this report.
proposal_led_control_harness | Display-to-first Matchstick control harness | Display to left bar as proposed | hardware | 1 | piece | explicit_singular_owner_item | {"owner_display_connector": "*connector (unresolved)", "owner_bar_end": "top of left bar", "verified_pins": null} |  | no_separately_named_cad_row |  |  |  |  | One cable is described, but pinout/connector PN, length, voltage, current and logic conversion remain open. | Reference-design 2.50 versus 2.54 mm discrepancy and reference pin-order evidence must remain reference-only; do not assert final purchased-board pinout. | The source-defined auxiliary twenty RGB LEDs and fixed white ring are distinct controls; no firmware change is implied.
proposal_led_interbar_harness | First-to-second Matchstick bridge harness | Left bottom under PCB to right bottom as proposed | hardware | 1 | piece | explicit_singular_owner_item | {"owner_routing_description": "under PCB around bottom of rear center sink", "validated_route": false, "verified_din_dout_pins": null} |  | no_separately_named_cad_row |  |  |  |  | One bridge wire is described. Route remains owner intent rather than a modeled/clearance-checked cable path. | Bottom-to-bottom must not be treated as DOUT-to-DIN until the exact board orientation and purchased pinout are inspected.
proposal_speakers | Speakers | One in each side apron | hardware | 2 | piece | one_per_two_aprons | {"model_impedance_power": null, "connector": null} | cad_35bc922ba3c7: 2 | related_cad_rows_require_role_and_spec_confirmation |  |  |  |  | Two owner-described speakers correspond to two generic modeled Speaker instances; electrical ratings and exact display outputs/connectors remain open.
proposal_power_button | Power button | Left apron | hardware | 1 | piece | explicit_singular_owner_item | {"exact_contact_illumination_spec": null} | cad_8d5f897e6762: 1 | related_cad_rows_require_role_and_spec_confirmation |  |  |  |  | One modeled 16 mm button is generic; PS_ON adapter type, contact wiring and any illumination are unconfirmed.
proposal_usb_hub | USB hub | Right apron | hardware | 1 | piece | explicit_singular_owner_item | {"exact_model": null} | cad_8a5caa14b72d: 1 | related_cad_rows_require_role_and_spec_confirmation |  |  |  |  | One modeled generic hub; power/data cable and interface remain unconfirmed.
proposal_ps_on_adapter | Mosfet.Party PS_ON adapter | Power button/PSU control | hardware | 1 | piece | explicit_singular_owner_item | {"exact_variant": null, "owner_ground_extension": "proposed cut/solder extension", "purchased_board_pinout": null} |  | no_separately_named_cad_row |  |  |  |  | The selected Apevia PSU does not establish the FSP500-30AS plug-and-play variant. Resolve button/header/Lite/prewired choice using the exact PSU and official revision. | Ground pin, solder/strain relief, insulation and retention need verified source and physical checks; this row authorizes no cutting or connection.
proposal_eps_adapter | Mosfet.Party power adapter (EPS intent) | BC250 power input conversion | hardware | 1 | piece | explicit_singular_owner_item | {"owner_literal_name": "esp adapter", "interpreted_intent": "EPS power adapter; exact revision not confirmed"} |  | no_separately_named_cad_row |  |  |  |  | Retain the owner's original naming and mark the EPS interpretation. Do not invent the purchased adapter PN. | Parent official-source review requires CPU 8-pin into the EPS adapter and PCIe 8-pin into the onboard BC250 connector; these are not interchangeable. | No installation, soldering or power test is performed by this report.
proposal_ps_on_ground_extension | PS_ON ground extension wire and insulation/strain relief | Under-PCB control connection | hardware |  | piece | not_specified | {"wire_length_gauge_connector": null} |  | no_separately_named_cad_row |  |  |  |  | Exact wire length/gauge, terminal, insulation and retention hardware quantities are not specified. Do not infer an approved PCB ground pin or cable route.
proposal_hot_glue | Hot glue as owner-proposed retention | Ground connection retention | consumable |  | gram | not_specified | {"amount": "small amount per owner", "validated_retention_method": false} |  | no_separately_named_cad_row |  |  |  |  | No mass, temperature rating, material selection or validation is supplied; it does not substitute for suitable electrical/strain-relief design.
proposal_nvme_extension | NVMe extension cable/assembly | Existing OS NVMe moved from BC250 to remote mount | hardware | 1 | piece | explicit_singular_owner_item | {"length_form_factor_connector": null} |  | no_separately_named_cad_row |  |  |  |  | The extension is a distinct product from the M.2 splitter. Exact electrical lanes, drive compatibility, bend radius, retention and clearance remain open. | Owner loop and 90 degree bend are routing intent, not validated cable geometry.
proposal_nvme_extension_plate | NVMe extension plate | Extension assembly to NVMe mount | custom_or_bundled_part_unresolved | 1 | piece | explicit_singular_owner_item | {"exact_design": null} |  | no_separately_named_cad_row |  |  |  |  | Owner names a plate but no separately named plate CAD row exists. It may be part of an extension product; no fabrication or purchased identity is assumed.
proposal_nvme_mount | NVMe mount | Bottom of backbone | custom_part | 1 | piece | explicit_singular_owner_item | {"exact_design": null} |  | no_separately_named_cad_row |  |  |  |  | No separately named NVMe mount row exists. The nineteen-body AM4 cooler adapter is not this NVMe mount. | Confirm physical design, attachment, drive retention and access before final BOM.
proposal_nvme_plate_m3 | M3 screws: extension plate to NVMe mount | First NVMe joint | hardware | 4 | piece | explicit_owner_quantity | {"thread": "M3", "length_mm": null, "head": null} |  | no_separately_named_cad_row |  |  |  |  | Four explicitly proposed. Length, head, nut/insert requirements and final joint are unstated; no exact matching top-level screw row is established.
proposal_nvme_mount_backbone_m3 | M3 screws: NVMe mount to backbone | Second NVMe joint, initially loose | hardware | 4 | piece | explicit_owner_quantity | {"thread": "M3", "length_mm": null, "head": null, "owner_initial_state": "loose until wiring arranged"} |  | no_separately_named_cad_row |  |  |  |  | Separate set of four explicitly proposed; not the same four as the plate joint. No length/head/retention is specified. | Final tightening, access, PCB clearance and thread engagement remain unvalidated.
proposal_os_nvme_reuse | Same OS NVMe reused after installation | Direct-board installation then extension location | existing_device_reuse | 1 | piece | explicit_same_owner_device | {"capacity_form_factor": null, "same_device_across_steps": true} | cad_124f6fc1c790: 1 | cad_a3f594caf952: 2 | reuse_does_not_change_three_modeled_ssds |  |  |  |  | The OS drive in the first and later steps is the same owner-described device, not two purchases. | Baseline remains one 2280 plus two 2230 modeled drives. Their actual purchased identities and use roles remain unconfirmed; do not reduce three CAD instances or select one silently.
proposal_wifi7_m2 | Wi-Fi 7 M.2 board | Owner's rear splitter slot | hardware | 1 | piece | explicit_singular_owner_item | {"exact_part_number": null, "electrical_key_interface": null} |  | no_separately_named_cad_row |  |  |  |  | Single board is stated, but no separately named wireless card row establishes its purchased identity. | Confirm PCIe/USB interfaces, keying, exact splitter slot support and antennas; filename or generic splitter geometry cannot prove Wi-Fi 7 compatibility.
proposal_m2_splitter | M.2/NVMe splitter | BC250 M.2 slot feeding Wi-Fi and NVMe extension | hardware | 1 | piece | explicit_singular_owner_item | {"exact_part_number": null, "lane_keying_slot_support": null} | cad_8c980fa3a192: 1 | related_cad_rows_require_role_and_spec_confirmation |  |  |  |  | One generic M2_Splitter is modeled. It does not confirm an electrical bifurcation/switching design or wireless-card support. | Owner's front/back slot description is unverified for the exact purchased board.
proposal_wifi_antennas_and_cables | Wi-Fi antennas and panel-mount cables | Rear cover RF connections | hardware |  | piece | not_specified | {"connector_polarity_cable_loss": null} | cad_5429a83cd569: 2 | cad_6ab458265e62: 2 | related_cad_rows_require_role_and_spec_confirmation |  |  |  |  | Two stubby antennas and two panel-mount cables are modeled; owner paragraph gives no new total or extra quantity. | Confirm exact wireless module connector, frequency support and SMA/RP-SMA identity before declaring compatible.
proposal_usb_extensions_alternative | USB extension cables (alternative) | Display and hub host connections | hardware |  | piece | not_specified | {"alternative_group": "usb_host_extension_choice", "alternative_to": "proposal_usb_180_alternative", "length_connector_rating": null} |  | no_separately_named_cad_row |  |  |  |  | Owner proposes extension cables OR 180 degree adapters; do not add both alternatives as mandatory quantities. | Display/hub port assignments are owner intent, not verified USB topology or exact port pinout. Cable quantities and specifications remain unstated.
proposal_usb_180_alternative | 180 degree USB adapters (alternative) | Display and hub host connections | hardware |  | piece | not_specified | {"alternative_group": "usb_host_extension_choice", "alternative_to": "proposal_usb_extensions_alternative"} | cad_6d644622411d: 2 | related_cad_rows_require_role_and_spec_confirmation |  |  |  |  | Two adapters are modeled, but owner does not state a final required adapter count. Preserve two CAD instances; chosen alternative and exact orientation remain open.
proposal_zip_ties | Zip ties | Excess PSU and signal wiring management | hardware |  | piece | not_specified | {"locations": "unresolved", "keep_clear": "fan-to-sink-to-top airflow path"} |  | no_separately_named_cad_row |  |  |  |  | No quantity, size, anchors, routing or tension are specified. Do not invent physical tie points from rendered illustrations. | Check insulation, connector strain relief, service access, sharp-edge contact, fan/blade clearance and airflow in physical assembly.
proposal_cable_retention_mounts | Cable anchors/tie points/harness retention | Prior owner open item; supports wiring management | custom_or_bought_unresolved |  | piece | not_specified | {"design_status": "unresolved", "validated_locations": null} |  | no_separately_named_cad_row |  |  |  |  | No fabricated mount, anchor quantity or installed location is established. Keep this as a design dependency, not a modeled/finished feature.
proposal_fan_filter_media | Fan filter/media | Future filter mount system | hardware |  | piece | not_specified | {"size_material": null} |  | no_separately_named_cad_row |  |  |  |  | Mount heatset count does not establish filter count, material, fasteners or finished airflow performance.
proposal_installer_usb_drive | USB installer drive | Owner's selected Bazzite setup workflow | hardware | 1 | piece | explicit_singular_owner_item | {"capacity": null, "workflow": "parent source review; no commands in this BOM"} |  | no_separately_named_cad_row |  |  |  |  | A single installer USB device is stated; it is distinct from the display microSD and reused OS NVMe. | No new purchase or flashing permission is implied by the proposed item.
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

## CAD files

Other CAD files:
case-design/Rear_Cover_Whole.SLDPRT
case-design/BC250-Assy.SLDASM
case-design/Right_Apron.SLDPRT
case-design/BC250_HeatSink_Section3.SLDPRT
case-design/PSU_SFX_APEVIA_500.SLDPRT
case-design/SSD_M2_2230.step
case-design/SSD_M2_2280.step
case-design/bc250_bare.SLDPRT
case-design/ESP32-P4-5_0-inch-20251230.stp.SLDPRT
case-design/Backbone.SLDPRT
case-design/16mm_Power_Button.SLDPRT
case-design/Dual_92MM_FAN_Shim.SLDPRT
case-design/BC250_HeatSink_Section1.SLDPRT
case-design/High-efficiency Noctua 80mm fan grill v3.SLDPRT
case-design/Flat pattern - Backbone.DXF
case-design/snowman_mc75-8_heatsink_v1.SLDPRT
case-design/Stubby_SMA_Wifi_Antenna.SLDPRT
case-design/USB_Hub.SLDPRT
case-design/10x2_Magnet.SLDPRT
case-design/180degree_USB_Adapter.SLDPRT
case-design/6x3_Magnet.SLDPRT
case-design/80mm_Fan_Grill.SLDPRT
case-design/90718A110_High-Strength Glass-Filled Nylon Plastic Washer.SLDPRT
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

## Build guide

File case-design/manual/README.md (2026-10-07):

# Ronin printing and assembly manual

> [!NOTE]
> **Work in progress — changing rapidly.** You're welcome to use this manual to build and remix Ronin. Rev0.3 is a draft for review and iteration, with provisional CAD locator illustrations. Fabrication and wiring details remain unresolved, and the assembly sequence is provisional. Check the source revision and open decisions before choosing parts. [Ask Arthur](https://artfedderson.tech/#start) if you have questions.

**Revision:** Rev0.3 · **Status:** provisional first edition · **Publication date:** 2026-10-04 · **Live documentation update:** 2026-10-06 (Rev0.3 PDF/BOM retained)

[Open the illustrated PDF](Rev_0p3/BC250_Ronin_Build_Manual_Rev_0p3.pdf)

## Newer working documents

- [Rev A LED harness preparation](Ronin_LED_Harness_Rev_A.md): exact sourced cable parts, numbered electrical maps, crimping steps and required checks. The SATA-powered adapter is ordered; harness, LED firmware and bench acceptance remain pending.
- [October 6 revision notes](REVISION_NOTES_2026-10-06.md): adapter, modeled NVMe extension/twin mounts/ribbon and concrete next-manual followups.
- [Current display prototype](../../display/CURRENT_STATUS.md): physical Windows acceptance and Linux/feature limits; newer than the published firmware baseline.

These are live addenda. The Rev0.3 PDF and companion data below preserve their original source revision and counts.

## Editable companion files

| File set | CSV | JSON | Purpose |
| --- | --- | --- | --- |
| CAD inventory / provisional BOM | [CAD inventory](Rev_0p3/BC250_CAD_BOM_Rev_0p3.csv) | [CAD inventory](Rev_0p3/BC250_CAD_BOM_Rev_0p3.json) | 34 CAD source rows covering 83 active assembly instances, with sourcing and verification status |
| Open items | [Open items](Rev_0p3/BC250_Open_Items_Rev_0p3.csv) | [Open items](Rev_0p3/BC250_Open_Items_Rev_0p3.json) | 21 original unresolved fit, hardware, mounting, routing, and validation decisions |
| Proposed hardware / context | [Proposed hardware](Rev_0p3/BC250_Proposed_Hardware_Rev_0p3.csv) | [Proposed hardware](Rev_0p3/BC250_Proposed_Hardware_Rev_0p3.json) | 59 proposal, context, reuse, alternative, and routing rows requiring confirmation |

Unconfirmed quantities, specifications, supplier part numbers, and interfaces remain explicitly open. A file present in the CAD folder is not evidence that the part is used in the active assembly. Match the manual's CAD source/revision notes to the design you intend to build; the repository's original saved CAD snapshot is described in the [case-design guide](../README.md).

These are public companion derivatives for this manual revision. They preserve modeled counts, stable IDs, proposal quantities, specifications, and unresolved purchase fields. The proposal register includes existing hardware reuse and alternatives; the final purchase BOM remains unfinished.

## CAD revision used by this draft

Rev0.3 records a native CAD export with 83 active instances and 34 unique CAD source paths. The saved `BC250-Assy.SLDASM` was observed on **2026-10-03 at 21:11:25 UTC**, with SHA-256 `9373a60ab27ae99628ebbc556cbeacaa1fa84fe42846cb7406cfa16978e2c861`. The export SHA-256 is `6629e8ec61feadab36cd367e2baddc19778b2425403b07549a4b3b1a90aa8ac1`. The export postdates that saved assembly; this does not prove every referenced component is unchanged.

The [assembly preserved in the repository](../BC250-Assy.SLDASM) is the earlier imported snapshot, with Git LFS SHA-256 `271cf7703d2a2d1c0b56d6f5e30ba2481672cdabf75e36cca64796add342484a`. It differs from the saved assembly observed for this manual. **Check the current CAD source and unresolved parts before fabrication.** [Ask Arthur](https://artfedderson.tech/#start) if anything is unclear. This manual publication does not update that preserved CAD snapshot.

## How to use this draft

1. Read the revision status and unresolved decisions in the PDF before selecting parts or committing to a print.
2. Check the BOM's modeled, sourced, and physically verified evidence for each component.
3. Treat printed orientations, mounting/routing concepts, and current-CAD locators as provisional wherever indicated.
4. Confirm final wiring and mechanical interfaces before applying power or following an assembly sequence.

The design uses two ten-LED **Rainbow on a Matchstick boards by Blamm**; the power-button indicator is separate. The ordered Rev A adapter now supplies two independent LED channels from SATA while the display retains USB power; the [harness addendum](Ronin_LED_Harness_Rev_A.md) supersedes the older stick-to-stick proposal. Mounting, real connector fit and LED output remain unverified. The **Mosfet.Party EPS Power Adapter and PS_ON Adapter** remain subject to variant, mounting, and harness confirmation. Credit for the single remixed 92 mm fan shroud belongs to **MandicReally**. Component manufacturer sources and remaining verification work are recorded in the manual and companion data.

The current Windows prototype has physically verified live USB telemetry, the native menu, profile selection and touch actions. All six app buttons bring existing SolidWorks, Steam, Claude, PrusaSlicer, OBS and Codex windows forward; OBS also passed a fresh launch and focus check. The [repository display package](../../display/README.md) contains an earlier baseline, while the [latest prototype writeup](https://artfedderson.tech/blog/bc250-display-native-menu-profiles) covers this newer work. The Rev0.3 PDF software chapter still reflects its earlier draft. Linux hardware and Gaming Mode, other fresh application launches, physical LED control, gamepad host wake and AI/voice functions remain pending.

## Keeping the revision current

Mechanical, electronics, printing, display, and host-software changes must update the relevant manual/BOM entries or record a concrete documentation follow-up for the next revision. Keep proposed parts separate from confirmed BOM entries. Refresh figures from the stated assembly source when CAD changes; final exploded views and detailed assembly order depend on resolving the remaining interfaces.

The illustrations and manual prose are original project work. Voron's documentation organization was a clarity reference; no Voron artwork, diagrams, icons, page assets, or prose are reused, and this project is not affiliated with Voron. Third-party components and models retain their existing rights; this manual adds no blanket license to them.

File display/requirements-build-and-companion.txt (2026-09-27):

annotated-types==0.8.0
bitarray==3.11.0
bitstring==4.4.0
bleak==3.0.2
certifi==2026.7.22
cffi==2.1.1
charset-normalizer==3.5.1
click==8.1.8
colorama==0.4.6
construct==2.10.70
cryptography==44.0.3
ecdsa==0.19.2
esp-coredump==1.17.2
esp-idf-diag==0.2.0
esp-idf-kconfig==2.5.4
esp-idf-monitor==1.10.0
esp-idf-size==1.7.1
esp-pylib==1.1.5
esp_idf_nvs_partition_gen==0.1.9
esp_idf_panic_decoder==1.5.0
esptool==4.12.0
freertos-gdb==1.0.4
greenlet==3.5.6
idf-component-manager==2.5.2
idna==3.20
imageio-ffmpeg==0.6.0
intelhex==2.3.0
jsonref==1.1.0
markdown-it-py==4.2.0
mdurl==0.1.2
packaging==26.3
pathvalidate==3.3.1
pillow==12.3.0
playwright==1.63.0
psutil==7.2.1
pyclang==0.7.0
pycparser==3.0
pydantic==2.13.5
pydantic-settings==2.15.0
pydantic_core==2.46.5
pyee==13.0.1
pyelftools==0.33
pygdbmi==0.11.0.0
Pygments==2.21.0
pyparsing==3.2.5
pyserial==3.5
python-dotenv==1.2.3
PyYAML==6.0.3
qrcode==8.2
reedsolo==1.7.0
requests==2.34.2
requests-file==3.0.1
requests-toolbelt==1.0.0
rich==15.0.0
rich-click==1.9.9
ruamel.yaml==0.19.1
setuptools==84.0.0
six==1.17.0
tibs==0.5.7
tqdm==4.70.1
tree-sitter==0.26.0
tree-sitter-c==0.24.2
truststore==0.10.4
typing-inspection==0.4.4
typing_extensions==4.16.0
urllib3==1.26.20
windows-curses==2.4.2
winrt-runtime==3.2.1
winrt-Windows.Devices.Bluetooth==3.2.1
winrt-Windows.Devices.Bluetooth.Advertisement==3.2.1
winrt-Windows.Devices.Bluetooth.GenericAttributeProfile==3.2.1
winrt-Windows.Devices.Enumeration==3.2.1
winrt-Windows.Devices.Radios==3.2.1
winrt-Windows.Foundation==3.2.1
winrt-Windows.Foundation.Collections==3.2.1
winrt-Windows.Storage.Streams==3.2.1
zxing-cpp==3.1.1

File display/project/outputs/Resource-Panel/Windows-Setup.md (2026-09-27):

# Windows monitoring setup

Tap SETTINGS on the display. The QR code and printed link lead to the official Libre Hardware Monitor release page:

https://github.com/LibreHardwareMonitor/LibreHardwareMonitor/releases/latest

The code opens a website on the scanning device. If you scan with your phone, send that link to the Windows PC. It does not install anything automatically.

1. Download the appropriate Windows release from that official page and follow its installation instructions, including required sensor components.
2. Run Libre Hardware Monitor as administrator and leave it running. Confirm it shows a CPU Package or AMD CPU temperature.
3. In Options → Remote Web Server, configure 127.0.0.1 (localhost), port 8085, and enable Run. The installed .NET 10 build did not expose the expected WMI namespace on this PC. Keep this folder's USB companion running; it reads the local web sensor feed, with WMI as a fallback for builds that expose it. The display still uses USB, not Wi-Fi.
4. Within about 20 seconds, the panel should show a CPU temperature if a supported sensor is exported. SETTINGS shows whether a CPU temperature is being received. N/A remains appropriate when no valid sensor is available.

The reader prefers CPU Package or Tctl/Tdie, otherwise the highest CPU temperature. It does not substitute SSD/GPU temperatures. Invalid and stale readings are discarded. Real sensor operation still needs verification with Libre Hardware Monitor running on the target PC.

The QR downloads the sensor helper only. Our companion is currently a local package, not a publicly hosted installer. For a new PC, copy this Resource-Panel folder and follow README.md to install Python dependencies and start the companion. A future complete setup QR needs a public download URL for that package.

Neither helper autostart nor administrator approval is silently configured.

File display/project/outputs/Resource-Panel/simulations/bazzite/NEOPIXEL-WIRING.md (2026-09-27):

# Planned two-ring connection

Concept only: no GPIO has been assigned or firmware output enabled.
The proposed rings sound like Adafruit 1586, 24 RGB pixels, nominal 66 mm diameter. Confirm the exact SKU before ordering connectors (RGBW requires different pixel configuration).

```text
Confirmed-free P4 GPIO -> 74AHCT125 (5 V) -> 330 ohm -> Ring 1 DIN
Ring 1 DOUT --------------------------------------> Ring 2 DIN
Regulated 5 V supply --------+---------------------> Ring 1 5V
                            +---------------------> Ring 2 5V
Common GND: supply, P4, level shifter, both rings
```

Data is daisy chained; power is parallel. Connect the level shifter enable appropriately (74AHCT125 /OE low), and add its supply decoupling. Put a 500–1000 uF capacitor rated at least 6.3 V across the LED supply near the rings, observing polarity.

Budget conservatively up to 2.88 A at 5 V for 48 RGB pixels at full white (60 mA per pixel); actual draw depends on revision and brightness. Supply the LEDs from a suitably rated 5 V PSU branch, not a GPIO or an unverified display-board power header. Do not join independent USB and PSU 5 V sources. Common ground is required. Standby power for the panel does not imply enough standby capacity for the LEDs; initially plan LEDs off while the PC is off.

These rings use solder pads. A matching locking pigtail is useful, but it is not automatically compatible with the Elecrow connector. Verify connector current rating, wire gauge, polarity and pin order. Separate power feeds to each ring are preferable to passing all LED current through an undersized connector. Add strain relief. Board V1.0 schematic and existing pin assignments must be reviewed before choosing the GPIO or board-side pigtail.

Sources:
- https://www.adafruit.com/product/1586
- https://learn.adafruit.com/adafruit-neopixel-uberguide/basic-connections
- https://learn.adafruit.com/adafruit-neopixel-uberguide/powering-neopixels

The HTML preview provides power, brightness, palette and effect selection. It does not drive LEDs. The current device firmware remains unchanged.

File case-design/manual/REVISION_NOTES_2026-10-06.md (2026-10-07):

# Ronin manual — October 6 revision notes

These supplement the frozen Rev0.3 PDF/BOM. They do not silently change its counts or replace the repository's earlier saved CAD. Build and remix Ronin freely; check revisions/open interfaces and [ask Arthur](https://artfedderson.tech/#start) if you have questions.

## Ordered adapter and revised harness

The **Ronin Rev A SATA-powered ESP32 LED adapter** is ordered and appears as one visible component in the working SolidWorks assembly. The 44 × 34 mm board uses SATA LED power; the display stays USB-powered/controlled. One 5/12 V selector supplies both outputs; Matchstick V1.0 requires **5 V**. Two independent channels replace the earlier display-powered, stick-to-stick harness proposal, letting planned firmware address all twenty pixels without daisy-chain connectors absent from V1.0.

Delivery and bench tests are pending. [Harness preparation](Ronin_LED_Harness_Rev_A.md) covers electrical maps, sourced parts, crimps and checks. Actual display plug fit/cavity orientation, mux, lengths, LED brackets and insulating mounts remain provisional. PCB source, Gerbers, manufacturing BOM/CPL and factory files are not included in this public release. Approved images can illustrate the board without publishing those files.

## NVMe arrangement in working CAD

The October 6 live inventory confirms **one NVMe extension board, two `NVME_Extension_Mount` instances, one modeled NVMe extension ribbon and one relocated `SSD_M2_2280`**. Extension board, twin mounts and explicit ribbon route are additions relative to the October 3 render export; SSD placement changed too. The working assembly has 157 unsuppressed instances, 151 visible. These observations do not update frozen Rev0.3 counts or the repository's preserved October 1 CAD snapshot.

The long vertical ribbon leg and extension sit behind the backbone's main sheet. The connector end returns toward the front-side M.2 splitter. This describes the modeled placement, not a collision or bend-radius check.

This route helps locate intended hardware and review service access. It does not prove ribbon bend limits, connector clearance, fit, PCIe performance or final purchase part numbers. World-axis bounds of the tilted assembly are not local part dimensions.

Current CAD locator of the NVMe extension, modeled ribbon and twin mounts

Pink identifies the ribbon route, lavender the two printed mounts, and teal the SSD/extension. The backbone and BC250 are ghosted for visibility. This is a current-CAD locator, not a cable cut-length, physical fit or storage-link validation.

## Display prototype

The Windows prototype now has native menu/profiles and six reviewed app tiles. Existing-window focus/duplicate suppression passed physical testing; OBS also passed fresh-launch/focus. Repository firmware remains the earlier baseline. See [current status](../../display/CURRENT_STATUS.md). LED output, Linux desktop/Gaming Mode, PC gamepad wake and AI voice remain pending.

## Next-manual followups

| Change | Next revision must record | Acceptance still required |
| --- | --- | --- |
| LED adapter | Installed revision, mounts, selector, assembly photo and route | Received-board inspection; controlled power, voltage, load, heat and backfeeding |
| Independent LED leads | Lengths, real cavity photos, terminals, ties and removal slack | HY2.0 fit/continuity; mux; firmware and pixel/color tests |
| NVMe extension/twin mounts | Exact extension/ribbon source, fasteners and exploded views | Bend/clearance fit, retention and PCIe/NVMe operation |
| Menu/app controls | Paired source/install package, bindings and screenshots | Target Linux GUI, Wayland/Gaming Mode and real launches |
| Cable management | Serviceable ties/anchors and excess PSU routing | Fan/vent clearance, edge protection and cover removal |

Blamm's Matchsticks, Mosfet.Party's EPS Power Adapter/PS_ON Adapter, and MandicReally's single remixed 92 mm fan shroud retain their credits/upstream terms. The power-button indicator remains separate.

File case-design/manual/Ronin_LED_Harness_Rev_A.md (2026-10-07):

# Ronin LED harness — Rev A preparation guide

**Updated:** 2026-10-06 · **Hardware:** Rev A adapter ordered; delivery, assembly inspection and bench tests pending.

You're welcome to build and remix Ronin. This records the intended harness and remaining checks; it is not a tested plug-and-play wiring release. [Ask Arthur](https://artfedderson.tech/#start) if you have questions. Working display touch controls are separate from LED integration, which still needs firmware and physical testing.

## What the adapter does

The 44 × 34 mm adapter takes LED power from the PSU's SATA cable. The ESP32-P4 display keeps its USB power and host connection. A four-wire display lead supplies two data signals, a 3.3 V logic reference and shared ground; **it does not carry LED power**.

Two independent outputs are intended to drive one ten-LED **Rainbow on a Matchstick V1.0 board by Blamm**. This avoids needing a second daisy-chain connector on V1.0. Planned firmware will address twenty individual pixels across two channels. That firmware, startup/fault handling and physical output are not verified yet.

One jumper selects **5 V or 12 V for both outputs together**. Matchstick V1.0 uses **5 V only**. The connector cannot detect a wrong voltage. Future 12 V addressable LEDs also need their pin order and protocol checked; four-wire analog RGB strips are unsupported.

```text
PSU SATA power ── modified extension ── J1 [Ronin Rev A adapter]
                                           ├─ J2 ── Matchstick A, 10 LEDs
                                           └─ J3 ── Matchstick B, 10 LEDs
ESP32-P4 display UART0_OUT ────────────── J4
USB host ─────────────────────────────── display power + control
```

This shows electrical connections, not final routing or connector viewing directions. LED brackets, cable lengths and insulating mounts need fit checks. The integral power-button indicator remains separate.

## Cable parts

Quantities cover one harness, excluding spare terminals. Source links identify parts; availability and final lengths still need checking.

| Part | Quantity | Exact reference / source | Use |
| --- | --- | --- | --- |
| SATA extension | 1 | [StarTech SATAPOWEXT8](https://www.startech.com/en-us/cables/satapowext8) | Replaceable 203.2 mm, 18 AWG donor lead; trim after measuring |
| SATA-input housing | 1 | JST **VHR-3N**, [part reference](https://jlcpcb.com/partdetail/C157899) | 3.96 mm VH, mates with J1 |
| VH terminals | 3 | JST **SVH-21T-P1.1**, [part reference](https://www.digikey.com/en/products/detail/jst-sales-america-inc/SVH-21T-P1-1/527368) | One conductor per contact; 18–22 AWG, insulation OD 1.7–3.0 mm |
| LED housings | 4 | JST **XHP-3**, [part reference](https://jlcpcb.com/partdetail/C144402) | Both ends of two LED leads; 2.50 mm XH |
| Display adapter-end housing | 1 | JST **XHP-4**, [part reference](https://jlcpcb.com/partdetail/C144403) | Mates with J4; 2.50 mm XH |
| XH terminals | 16 | JST **SXH-001T-P0.6**, [part reference](https://jlcpcb.com/partdetail/C140573) | 12 LED + 4 display; 22–28 AWG, insulation OD 0.9–1.9 mm |
| Display-end donor lead | 1 lead | Elecrow **CPC03044C**, [five-pack](https://www.elecrow.com/4-pin-crowtail-cable5-pcs-p-1561.html) | Candidate Crowtail lead; actual fit, wire size and mapping need confirmation |
| LED wire | Length pending | [Alpha Wire 3051](https://www.alphawire.com/products/wire/hook-up-wire/premium/3051/), 22 AWG | Insulation OD 1.575 ± 0.051 mm, within selected XH contact range |
| Selector shunt | 1 | [Harwin M7567-05](https://www.harwin.com/products/M7567-05), 3 A | J5 pins 1–2 for Matchsticks |
| Insulating mounts | 2 sets, dimensions pending | M2.5 standoffs/screws, supplier pending | 2.7 mm board holes; height, screw length and clearance need checks |

Buy spare terminals: a practice crimp costs less than a damaged display. Check the selected contacts in the [JST XH catalog](https://www.jst-mfg.com/product/pdf/eng/eXH.pdf) and [JST VH catalog](https://www.jst-mfg.com/product/pdf/eng/eVH.pdf). “JST connector” alone does not identify a compatible part.

## Read numbers before choosing wire colors

**All tables use electrical pin numbers.** A plug's mating-face view and wire-entry view reverse left and right. Do not copy an unqualified left-to-right photo. On the adapter, identify pad 1 from its square PCB pad and markings; identify the matching housing cavity from the connector drawing or continuity with a mating header. Label ends before inserting terminals.

| Adapter connector | Pin 1 | Pin 2 | Pin 3 | Pin 4 |
| --- | --- | --- | --- | --- |
| **J1**, SATA / VH | SATA +5 V | Ground | SATA +12 V | — |
| **J2**, LED A / XH | Data A | Selected LED supply | Ground | — |
| **J3**, LED B / XH | Data B | Selected LED supply | Ground | — |
| **J4**, display / XH | GPIO48 / A | GPIO47 / B | Display 3.3 V reference | Ground |
| **J5**, selector | +5 V | Selected input | +12 V | — |

Matchstick V1.0 has **pin 1 DIN, pin 2 +5 V, pin 3 GND**. Each LED cable maps 1→1, 2→2, 3→3. DOUT solder pads remain unused. Check actual revisions and markings against [Blamm's upstream design](https://github.com/VoronDesign/Voron-Hardware/tree/36355e8f7d3c6e8d8915fddd307beab8e69d1425/Daylight/Rainbow_on_a_matchstick).

For the **Elecrow Advanced 5-inch ESP32-P4 V1.0**, the supplied manufacturer schematic identifies **J2 UART0_OUT** as **HY2.0-4P-SMT**:

| Display UART0_OUT pin | Signal | Adapter J4 pin |
| --- | --- | --- |
| 1 | GPIO48 | 1 |
| 2 | GPIO47 | 2 |
| 3 | VDD3V3 | 3 |
| 4 | Ground | 4 |

This four-pin connector is **separate from the USB-C UART0 programming socket**. HY2.0 is not a confirmed JST PH part: equal pitch does not prove shell fit. Start with the manufacturer's lead and check fit and every conductor. The [manufacturer V1.0 CAD/schematic](https://github.com/Elecrow-RD/-CrowPanel-Advanced-5inch-ESP32-P4-HMI-AI-Display-800x480-IPS-Touch-Screen/tree/421a2d8c797f04151337ffd3ae03ad50bee0ac28) establishes electrical numbering, not the physical housing's left/right cavity view.

The display multiplexes these signals with an optional wireless interface. **SEL0 must be low** for UART0_OUT; switch labels alone are insufficient because vendor prose and circuit description disagree. The display's secondary STC controller can also affect this routing and needs checking. Confirm routing electrically and prevent two interfaces driving the lines before enabling LED firmware. GPIO47/48 are proposed LED signals based on that circuit; current firmware does not enable them as LED outputs.

## Make one cable at a time

Gather a wire cutter, suitable wire stripper, magnifier, multimeter, labels, heat-shrink and open-barrel crimp tooling. Match the contact and terminal form to the [JST tooling catalog](https://www.jst-mfg.com/product/pdf/eng/eCRIMPING_MACHINES_AND_TOOLS.pdf). The tool must suit the exact contact and wire; a generic “Dupont” crimper is not automatically suitable. Correctly made pre-crimped leads are an alternative. Check the factory display lead's gauge and insulation OD before choosing terminals.

Use the contact/tool instructions for strip length; there is no universal length. Practice first. Following [JST handling guidance](https://www.jst-mfg.com/product/pdf/eng/handling_e.pdf):

1. Strip without nicking or losing strands.
2. Seat all strands in the conductor barrel and insulation in the insulation barrel.
3. Crimp with the specified tool. Inspect both grips and mating section; reject crushed, bent or incomplete crimps.
4. Check retention gently, then insert into the planned cavity until retained. Recheck it cannot slide out.

Do not trim strands to fit oversized wire or put multiple conductors in a single-wire contact. Never use 18 AWG SATA wire in these XH contacts. Meter through a mating test header or breakout rather than oversized probes in female sockets.

Modify a **replaceable SATA extension**, retaining device-side male SATA blades to mate with the PSU plug. Verify which wire reaches +5 V, ground and +12 V, then map to J1. Red/black/yellow are clues, not proof. Individually insulate unused wires and exposed joins. **Do not modify or repin the PSU's modular-end cable:** its pinout depends on the PSU.

Measure lengths with the case assembled enough to represent the route. Keep data beside ground, leave unplugging slack, and anchor cables so they cannot pull on connectors. Clear fan blades, vents, hot heatsinks, sharp edges and magnetic-cover removal paths. Final lengths and tie points belong in the next CAD/manual revision.

## Check before power

With **USB and SATA both disconnected**, meter every cable end-to-end against the numbered tables. Check neighboring pins for shorts, latch orientation and labels. Confirm the modified SATA lead's polarity; verify PSU output voltages separately before connecting the adapter.

Install **one** shunt at J5 **1–2 for 5 V**. Never bridge both sides. To change it, disconnect USB and SATA, allow discharge and meter the rail first. Both LED outputs share the voltage choice. Label this harness **5 V ONLY — Matchstick V1.0**.

First board power-up is a controlled bench test: display/sticks disconnected, current-limited supply. Inspect assembly, check logic/output rails and complete parts omitted by the selected assembly service. Do not bridge a missing fuse. Someone comfortable with a bench supply and meter should perform these checks; a PSU straight into an unknown harness is not the first test.

After firmware is ready, test one dim pixel per output, then channel identity, color order and all ten pixels per stick. Rev A has no LED power-good data gating or verified rail-sensing interface. Software alone has not been shown able to detect SATA power loss. Keep LED signal outputs dormant until a validated sequencing/gating solution and bench acceptance are in place. USB-only, SATA-only and power-off tests must check backfeeding through the data level shifter and display 3.3 V reference as well as the power rails. Load voltage/temperature measurements and strain relief are also required before publishing a validated installation procedure.

**Current stopping point:** adapter ordered and modeled. Display plug fit/cavity orientation, lengths, mounting, mux behavior, LED firmware and bench acceptance remain open. Working application buttons do not establish working LEDs.

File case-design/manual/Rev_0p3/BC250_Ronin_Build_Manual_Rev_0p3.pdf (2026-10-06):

BC250 / RONIN | ARTFEDDERSON.TECH / RONIN
Ronin build manual.

Printing, build preparation and proposed assembly order / 04 October 2026

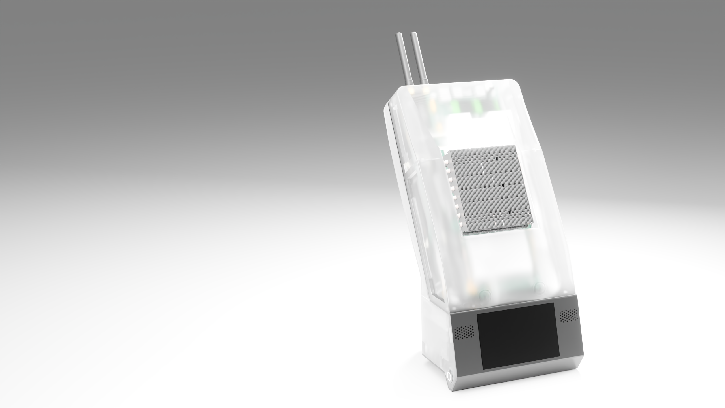
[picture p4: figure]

REV 0.3 | RAPIDLY CHANGING DRAFT | BUILD + REMIX WELCOME | 01

## RONIN

Printed layers.
Borrowed silicon.
A sensible number of LEDs.

## WORK IN PROGRESS

## Build and remix this case freely, and make it your own. This project is changing rapidly: CAD, parts and build steps are still being revised. If you have questions, reach out to Arthur. (https://artfedderson.tech/#start) This draft is not a verified

assembly guide.

Original SolidWorks-derived product render. Independent Art4Tech project; no official Voron affiliation. All manual artwork and prose are original.

NAVIGATION | ARTFEDDERSON.TECH / RONIN
Where each chapter starts.

Page numbers link to each chapter. Check what is confirmed and what still needs design or testing.

Read first / workflow | 3-4
Current CAD locator views | 5-6
BOM legend and all modeled parts | 7-11
PCTG preparation, coupons and rear printing | 12-15
Magnets, countersunk screws and inserts | 16-17
LED locations and mounting concept | 18-19
Cable-management planning and retention | 20-21
LED harness reference and power adapters | 22-23
Display: working behavior and roadmap | 24
Open register / release checklist | 25-28
Sources, credits and CAD provenance | 29-30
Owner-proposed assembly order and hardware delta | 31+

READ FIRST | ARTFEDDERSON.TECH / RONIN
Check the parts before building.

Start with the current inventory, then resolve missing hardware and fit details.

## BUILD + REMIX WELCOME

Build and remix this project freely. It is a rapidly evolving work in progress: CAD, the BOM and build steps may change. Check the current files and open issues as you go. If you have questions, reach out to Arthur. (https://artfedderson.tech/#start)

## What is established

## The export contains 83 active component instances from 34 unique CAD paths. Two Matchstick boards carry twenty RGB LEDs. Existing display firmware plays local animation/audio and receives serial

resource values.

## What remains open

Additional magnets, replacement countersunk screws, LED mounts,

## harnesses, USB cables, power-adapter variants, cable retention and possible extra cooling. Final quantities and purchase part numbers

are not yet complete.

CAD quantity counts the instances in this export. Check the required quantity before buying; instance suffixes do not give the count.

Read the open register before buying, printing a full set or wiring. A part number in the CAD filename may be a modeling reference.

The owner-proposed order starts on page 31. Completed CAD is still needed for final exploded views and verified installation details. Diagrams are labeled as locators or concepts.

A magnet cannot proofread a BOM. Fortunately, we can.

DESIGN READINESS | ARTFEDDERSON.TECH / RONIN
Check one interface at a time.

Finish these design checks. The proposed physical assembly order begins on page 31.

## 01 / IDENTIFY

## Check labels and purchased revisions

against the quantities and supplier links.

## 02 / PRINT TRIAL

## Dry PCTG and check the nozzle profile. Print

clarity and fit coupons.

## 03 / FIT CAD

Resolve rear-cover split, magnets, inserts, LED mounts and optional fan.

## 04 / ROUTE

## Model cable retention. Measure harness

lengths with enough slack for service.

## 05 / VERIFY

## Check connector mapping and power

distribution against the exact boards.

## 06 / BUILD + TEST

## Add final exploded pages, assemble, check

covers/airflow, then repeat thermal tests.

CAD MAP | ARTFEDDERSON.TECH / RONIN
The current assembly.

Locator view only - covers and internals retain the current CAD positions.

## Printed shell

Untinted transparent PCTG is specified.

## Product renders use a frosted finish and 0.20 mm layer lines. Upright panels are

preferred where practical.

## Still to design

LED positions are chosen. The mounts,

## extra magnet locations and cable-retention features still need CAD

work.

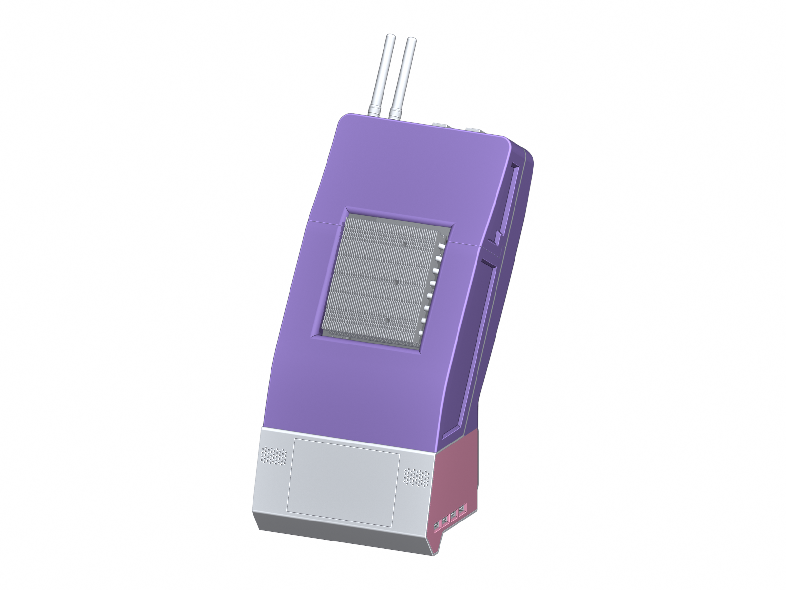
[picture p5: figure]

Native CAD geometry. Diagram colors identify parts; they are not proposed filament colors.

CAD MAP | ARTFEDDERSON.TECH / RONIN
Inside the covers.

Selected covers are hidden to show the current assembly. Components stay in their CAD positions.

## Keep access clear

Leave access to the BC250 board,

## backbone, PSU, fans, storage and display. Allow room to unplug harnesses and remove and refit the

magnetic covers.

## Next CAD pass

Add the selected power boards,

## mounting hardware and cable routes

before finalizing the assembly order.

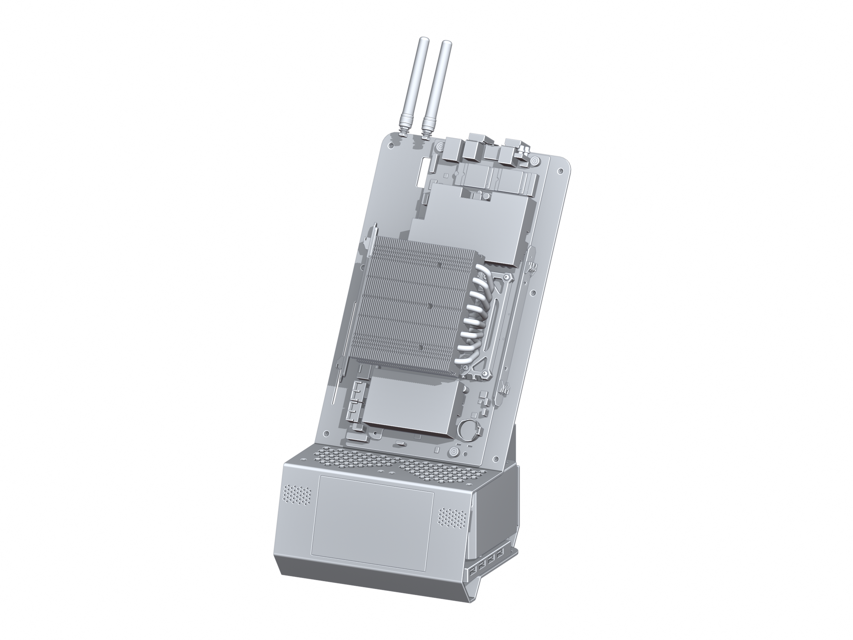
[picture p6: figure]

The current export has four untessellated fan-face warnings. The figure record retains the source export hash. These warnings have not been repaired.

BOM / HOW TO READ IT | ARTFEDDERSON.TECH / RONIN
Count the models before ordering.

All 34 unique CAD paths are covered in the following four pages and editable CSV/JSON.

Field | Meaning
CAD qty | Active instances in this export: 83 in total. Additional or unmodeled items are listed separately.
Source PN | Part number in a CAD filename, where present. Confirm it before purchasing.
Purchase PN | Exact selected product/revision, supported by a label, order or supplier drawing. Still unconfirmed in this inventory.
Primary source | Official design or manufacturer reference. See editable BOM links and source appendix.
Open item | A choice to confirm before completing the BOM, buying hardware or writing the installation step.

## Revision rule

When hardware or CAD changes, update the inventory, open register and affected figures. A similar model in the folder does not confirm the quantity or specification of a new part.

BOM / MODELED PARTS | ARTFEDDERSON.TECH / RONIN

# CAD inventory 1 / 4

CAD quantity is not the final required or purchased quantity. Source filenames are preserved in the editable inventory.

CAD source label | CAD
qty
Class | Source PN | Release status | Sourcing
10x2 Magnet | 6 | bought | - | Exact purchased PN/revision open | Source TBD
16mm Power Button | 1 | bought | - | Exact purchased PN/revision open | Source TBD
180degree USB Adapter | 2 | bought | - | Exact purchased PN/revision open | Source TBD
6x3 Magnet | 14 | bought | - | Exact purchased PN/revision open | Source TBD
80mm Fan Grill | 1 | printed | - | Fabrication/specification open | Source TBD
90718A110 High-Strength Glass-Filled Nylon Plastic Washer | 3 | bought | 90718A110 | Exact purchased PN/revision open | Source ref(s)
92MM Arctic PST FAN | 2 | bought | - | Exact purchased PN/revision open | Source ref(s)
92MM Arctic PST Split Insert | 2 | printed | - | Fabrication/specification open | Source TBD
93657A009 Nylon Unthreaded Spacer | 3 | bought | 93657A009 | Exact purchased PN/revision open | Source ref(s)

Sourcing and replacements still need decisions. BC250_CAD_BOM_Rev_0p3.json retains CAD basenames, stable IDs, all instance names and source references.

BOM / MODELED PARTS | ARTFEDDERSON.TECH / RONIN

# CAD inventory 2 / 4

CAD quantity is not the final required or purchased quantity. Source filenames are preserved in the editable inventory.

CAD source label | CAD
qty
Class | Source PN | Release status | Sourcing
93886A220 Reinforced Plastic Knurled-Head Thumb Nut | 3 | bought | 93886A220 | Exact purchased PN/revision open | Source ref(s)
94180A333 Brass Tapered Heat-Set Inserts for Plastic | 8 | bought | 94180A333 | Exact purchased PN/revision open | Source ref(s)
Apevia 500 SFX | 1 | bought | - | Exact purchased PN/revision open | Source TBD
Backbone | 1 | custom | - | Fabrication/specification open | Source TBD
bc250 after heatsink mod | 1 | custom | - | Fabrication/specification open | Source TBD
bc250 am4 adapter mount v1 | 1 | custom | - | Fabrication/specification open | Source TBD
Dual 92MM FAN Shroud | 1 | printed | - | Fabrication/specification open | Source TBD
ESP32-P4-5 0-inch-20251230 | 1 | bought | - | Exact purchased PN/revision open | Source ref(s)
Front Cover | 1 | printed | - | Fabrication/specification open | Source TBD

Sourcing and replacements still need decisions. BC250_CAD_BOM_Rev_0p3.json retains CAD basenames, stable IDs, all instance names and source references.

BOM / MODELED PARTS | ARTFEDDERSON.TECH / RONIN

# CAD inventory 3 / 4

CAD quantity is not the final required or purchased quantity. Source filenames are preserved in the editable inventory.

CAD source label | CAD
qty
Class | Source PN | Release status | Sourcing
Left Apron | 1 | printed | - | Fabrication/specification open | Source TBD
M2 Splitter | 1 | bought | - | Exact purchased PN/revision open | Source TBD
M3x16 91294A134 Black-Oxide Alloy Steel Hex Drive Flat Head Screw | 3 | bought | 91294A134 | Exact purchased PN/revision open | Source ref(s)
M3x45 91420A138 Steel Phillips Flat Head Screws | 8 | bought | 91420A138 | Exact purchased PN/revision open | Source ref(s)
PanelMnt SMA Antenna Cable | 2 | bought | - | Exact purchased PN/revision open | Source TBD
rainbow-matchstick-diffuser | 2 | printed | - | Fabrication/specification open | Source TBD
Rainbow Matchstick | 2 | bought | - | Exact purchased PN/revision open | Source ref(s)
Rear Cover Whole | 1 | printed | - | Fabrication/specification open | Source TBD
Right Apron | 1 | printed | - | Fabrication/specification open | Source TBD

Sourcing and replacements still need decisions. BC250_CAD_BOM_Rev_0p3.json retains CAD basenames, stable IDs, all instance names and source references.

BOM / MODELED PARTS | ARTFEDDERSON.TECH / RONIN

# CAD inventory 4 / 4

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

CAD source label | CAD
qty
Class | Source PN | Release status | Sourcing
snowman mc75-8 heatsink v1 | 1 | bought | - | Exact purchased PN/revision open | Source TBD
Speaker | 2 | bought | - | Exact purchased PN/revision open | Source TBD
SSD M2 2230 | 2 | bought | - | Exact purchased PN/revision open | Source TBD
SSD M2 2280 | 1 | bought | - | Exact purchased PN/revision open | Source TBD
Stubby SMA Wifi Antenna | 2 | bought | - | Exact purchased PN/revision open | Source TBD
Top Cover | 1 | printed | - | Fabrication/specification open | Source TBD
USB Hub | 1 | bought | - | Exact purchased PN/revision open | Source TBD

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

PRINTING / INVENTORY | ARTFEDDERSON.TECH / RONIN
Twelve instances screened for fit.

Ten distinct part types were screened for printing. Confirm how each will be made before preparing a final slicer or G-code pack.

Instance | Intended-frame envelope / mm | Fit status
Rear_Cover_Whole-1 | 200.0 x 169.8 x 299.4 | Rear: exceeds height
80mm_Fan_Grill-1 | 83.6 x 2.2 x 83.6 | Geometric fit only
Dual_92MM_FAN_Shroud-1 | 194.2 x 100.4 x 70.0 | Geometric fit only
92MM_Arctic_PST_Split_Insert-2 | 93.7 x 94.2 x 16.0 | Geometric fit only
bc250_am4_adapter_mount_v1-1 | 107.0 x 67.0 x 96.3 | Geometric fit only
92MM_Arctic_PST_Split_Insert-1 | 93.7 x 94.2 x 16.0 | Geometric fit only
Front_Cover-1 | 200.0 x 166.4 x 193.4 | Geometric fit only
Top_Cover-2 | 200.0 x 121.1 x 113.3 | Geometric fit only
Left_Apron-1 | 100.0 x 194.0 x 106.4 | Geometric fit only
Right_Apron-1 | 100.0 x 194.0 x 106.4 | Geometric fit only
rainbow-matchstick-diffuser-2 | 4.7 x 80.2 x 131.0 | Geometric fit only
rainbow-matchstick-diffuser-1 | 4.7 x 80.2 x 131.0 | Geometric fit only

Dimensions come from unchanged mesh vertices. The top cover stands on its edge. The AM4 adapter is one CAD component with 19 bodies. Reconcile its physical parts and hardware before printing; review supports, brims and reliability in the slicer.

PRINTING / PCTG | ARTFEDDERSON.TECH / RONIN
Trial clear PCTG before a panel.

Start with a small trial. These proposed settings have not been validated for a full panel.

First coupon trial | Starting point
Machine / material | CORE One+ INDX 8T / 3D-Fuel Natural/Clear Pro PCTG
Nozzle / layer / width | 0.6 mm / 0.20 mm / 0.66 mm
Nozzle / textured PEI bed | 260 C / 80 C
Outer / inner wall speed | 15 / 20 mm/s; initial max volumetric speed 3 mm3/s
Cooling / flow | 0% long-wall fan; test 0-10% locally. Calibrated 100% flow first.
Fill / seam | Avoid internal air gaps; aligned solid fill if present. Put seam on a less visible edge.

## Prepare the material

## Manufacturer drying guidance: 70 C for 6-8 h or 65 C for 8-12 h. Use the correct installed-nozzle INDX profile; the earlier active profile

declared all tools 0.4 mm.

## Check clarity and fit

## Compare visibility and RGB diffusion. A readable sample that no

longer fits its magnet pocket has not won the competition.

PRINTING / COUPONS | ARTFEDDERSON.TECH / RONIN
Measure haze. Measure fit.

The existing generic clarity coupons are 20 mm wide and 30 mm tall, in 1.5, 2.0 and 2.5 mm thicknesses.

## Choose the thickness nearest the panel wall. Print upright, then make a second

sample rotated 90 degrees around Z.

## Compare 0.20 and 0.12 mm layers on the 0.6 nozzle. Test the 0.8 nozzle only if it still

resolves the real features.

## Keep the best geometry settings. Compare 255 / 260 / 265 C, then calibrated 100 / 101

/ 102% flow if dry samples show gaps. Change one variable at a time.

## Place the same text card 5 mm behind each coupon and compare under the same

neutral light and LED color. Record thickness, haze, fit and settings.

## Print a small actual part before a panel. Check pockets, bridges and clips. The 0.4

nozzle remains useful for fine details.

## Trial files

## See the existing print_trials folder and PCTG_Print_Guide.html. The coupon geometries are generic test pieces. They do not replace case

parts or validate a production print.

## Keep the evidence

## Photograph each labeled coupon and record its material/nozzle settings. Use a recipe for case parts

only after actual print and fit checks.

PRINTING / REAR COVER | ARTFEDDERSON.TECH / RONIN
The rear is taller than the printer.

A one-piece geometric fit exists with tilt, but the split decision remains open.

## INDX height: 270 mm

## Rear upright: 299.4 mm

## Option A / one piece tilted

## Verified unchanged-mesh envelope: 243.583 x 200.000 x 266.639 mm. Candidate transform: Rx(-19.2 degrees), then Rz(+90 degrees) in assembly axes. Import the supplied oriented trial as millimetres; do not copy those angles blindly into an

arbitrary slicer.

## Option B / split for upright printing

## A split can give more print margin and keep the layers upright, but adds CAD and assembly work. The split, seam placement and join hardware have not been

designed.

The tilted object leaves about 2.21 / 2.50 mm per XY side and 3.36 mm top clearance. A 2 mm brim fits the object envelope geometrically; 3 mm does not. Supports and printer keep-outs remain unverified.

MECHANICAL / MAGNETIC COVERS | ARTFEDDERSON.TECH / RONIN
Check how the covers come off.

Use the current CAD count as a baseline. More magnets still need locations.

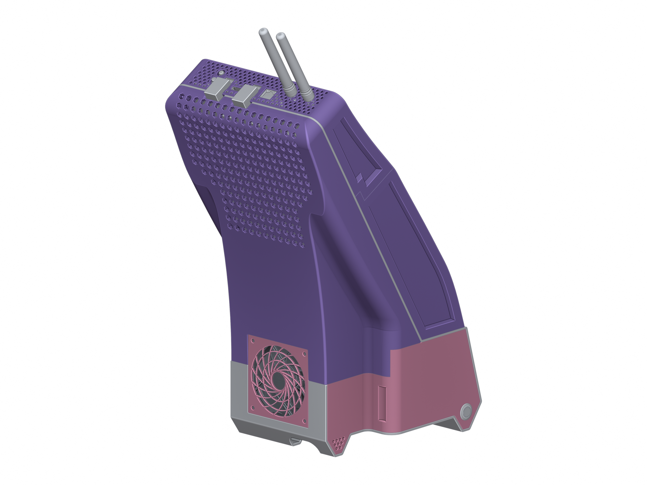
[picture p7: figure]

## Current inventory

## 14 modeled 6 x 3 magnets; 6 modeled 10 x 2

magnets. Grade, coating, exact supplier PN, retention and final count remain open.

## Before installing magnets

Pair and mark polarity on the actual build.

## Confirm pocket fit and retention with a small printed trial. Resolve the requested threaded

magnets and their exact thread/body size.

Rear hexagonal vents are shown in their current geometry. Final cover-removal and magnet-location diagrams will use the revised CAD.

MECHANICAL / THREADED JOINTS | ARTFEDDERSON.TECH / RONIN
Choose the screw that fits the joint.

The current screws and inserts are modeling references. Replacements still need to be selected.

Modeled baseline | Decision needed
8 x M3x45; source label 91420A138 | Select countersunk head standard, drive, head diameter/angle, length and engagement for each joint.
3 x M3x16; source label 91294A134 | Confirm countersink geometry and replacement product, rather than copying the old filename.
8 x inserts; source label 94180A333 | Confirm thread, OD, length, hole geometry and PCTG insertion procedure.
Washers / spacers / thumb nuts | Check the complete stack and mating hardware; CAD counts are retained in the BOM.

## Check the joint before buying

Measure the countersink and assembled stack. Check full engagement without bottoming out. The head should sit flush without splitting the plastic and clear the electronics. Test the chosen insert in a coupon before setting installation temperatures and steps.

LIGHTING / CAD LOCATIONS | ARTFEDDERSON.TECH / RONIN
Twenty LEDs. Two chosen locations.

Positions come from the current assembly. Mounting remains a design task.

## Respect the optical path

## The PCB and sheet-metal backbone occlude the emitters. Keep the useful glow around the board, through gaps and perforations, then through frosted

PCTG.

## No extra RGB fixtures

## Only the two ten-LED Matchstick boards provide auxiliary RGB. The display backlight and fixed-white power-button

indicator are separate.

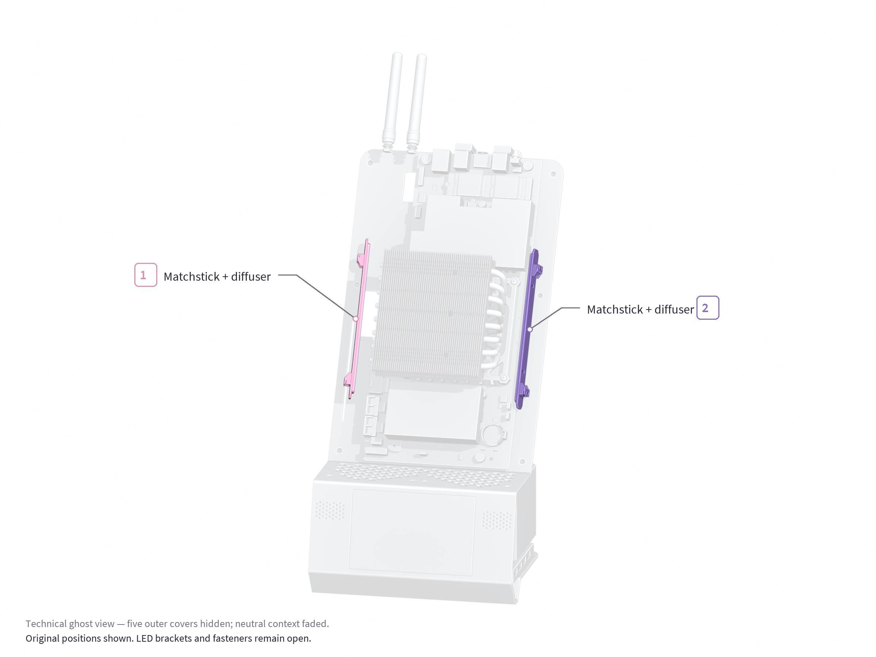
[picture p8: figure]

Technical ghost view: five covers are hidden and nearby parts, including PCB/backbone, are faded to show occluded Matchsticks. CAD positions are unchanged. Numbers locate boards. The owner intends left first, right second; physical DIN/DOUT and connector orientation remain unverified. This view does not show physical transparency or measured light output.

LIGHTING / MOUNTING CONCEPT | ARTFEDDERSON.TECH / RONIN
Support the boards and leave access.

Original reference drawing and proposed bracket constraints. Check the actual purchased revision.

## Reference outline: 158 x 11 mm

Two 3.2 mm plated mounting holes, tied to GND. Reference center distance: approximately 85.00 mm.

## Bracket concept to check

## Try a removable printed bracket with insulated standoff clearance at

the reference mounting holes. First confirm the actual hole locations, nearby geometry and appropriate M3 hardware.

## Alternative to compare

## If screws are hard to reach, consider edge clips that leave the LEDs clear. Do not clamp LED faces or support boards by their cables. Keep

connectors accessible and diffusers removable.

Board and LEDs are schematic. Native KiCad thickness is 1.6 mm; imported CAD PCB is 1.58 mm. No bracket has been modeled, collision-checked or physically validated.

CABLE MANAGEMENT / PLANNING | ARTFEDDERSON.TECH / RONIN
Plan where spare cable will sit.

Three proposed routing regions. Anchor positions and hardware still need selection.

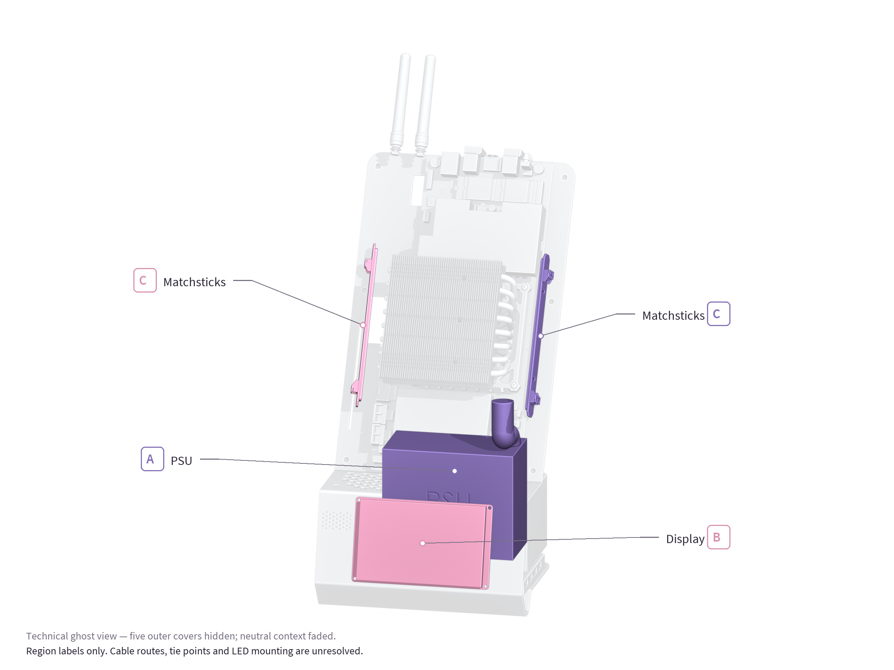
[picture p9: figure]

## A / PSU service loop

## Bundle excess length near the PSU exit, clear of fans and vents. Leave it accessible for

service.

## B / display + USB + audio

Separate small cables from bulky power leads.

## Support connectors and leave the screen and

covers removable.

## C / LED perimeter harness

## Plan the harness from the display to bar 1 to bar 2 along an accessible edge. Leave

connector slack and keep wires off LED faces.

Technical ghost view: five covers are hidden and surrounding parts faded. A/B/C mark planning regions, not approved tie points or cable routes. Check the real harness, fan sweep and cover-removal path in revised CAD.

CABLE MANAGEMENT / RETENTION | ARTFEDDERSON.TECH / RONIN
Service access beats a beautiful knot.

Measure the route before selecting mounts, cable ties, reusable straps and screws for the BOM.

## Heavy PSU wiring

## Compare tie saddles or reusable straps secured to checked backbone/bracket features. Support the bundle without using the

cover as a structural anchor.

## Small harnesses

## Give USB, display and LED connectors separate strain relief. Match tie width and saddle shape to the bundle, and keep the bend radius of

the selected cable.

Plan access for unplugging and removing each cover before placing a tie saddle.

Model the anchor body and fastener envelope. Check fan sweep, vent openings and nearby electronics.

Mock up cable lengths with PSU excess and the bend direction of the right-angle connector. Leave enough slack for service, then secure the cables.

Trial the fans, covers and service access before writing a numbered cable-routing page.

WIRING / REFERENCE CHECK | ARTFEDDERSON.TECH / RONIN
Do not assume a straight-through harness.

Official Matchstick design reference only. Verify the purchased boards and connector orientation before crimping.

Board interface | Reference pin assignment | Not yet established
J1 / input | 1 DIN | 2 +5V | 3 GND | Exact purchased revision and physical pin-1 orientation
J2 / output | 1 GND | 2 +5V | 3 DOUT | Correct housing, terminals and continuity mapping
J3 / alternate output | Single DOUT pad | Whether it is used in this build
Connector footprint | JST XH S3B-XH-A-1; nominal 2.50 mm | README says 2.54 mm; use actual connector drawing/revision

## Chain intent

Display controller -> DIN of bar 1; DOUT of bar 1 -> DIN of bar 2.

## Shared reference ground and the correct +5V LED supply are

required. Reference J2/J1 pin order differs.

## Firmware / power boundary

Display GPIO/header, logic-level compatibility, supply budget,

## protection, wire gauge, connector orientation and measured harness

lengths remain open. This is not a connection-ready display pinout.

POWER / PART SELECTION | ARTFEDDERSON.TECH / RONIN
The adapter input is EPS, not PCIe.

Select the exact Mosfet.Party variants and add their mounting to CAD before writing final wiring pages.

## EPS 8-pin to dual Micro-Fit

## Official adapter takes a CPU EPS 8-pin input and distributes power to two Micro-Fit connections. The designer specifies use alongside the BC250 PCIe 8-pin input. Follow the exact product documentation; do

not substitute a PCIe plug for EPS.

## PS_ON adapter

## Button, case-header, LITE and PSU-specific variants exist. Select the board for the actual PSU and case-button behavior. Model its

mounting, terminals and harness before writing the installation step.

Confirm actual PSU model, connector inventory and cable compatibility. Never infer a modular PSU cable pinout from connector appearance.

Add both selected boards and any spacers, screws and cable restraints to the revised assembly and BOM.

Document the main power-button indicator separately from the auxiliary RGB control path.

Exact product references are in the source appendix. No mains wiring or final power harness is designed in this edition.

DISPLAY / CURRENT AND PLANNED | ARTFEDDERSON.TECH / RONIN
What the display can do today.

The existing firmware works. The integrations below still need implementation.

## Working today

## Existing firmware plays local animated scenes with audio and receives CPU/memory/disk values over serial. An October 3 UART0 test showed live laptop values; LibreHardwareMonitor supplies

Windows temperature. No new firmware was flashed for that test.

## Next firmware work

Advanced twenty-pixel RGB scenes; resource-monitor options; context/page touch buttons that call host scripts; gamepad wake; and a voice-agent portal using the display mic/speakers.

The local companion prototype saves LED scenes, touch profiles and agent endpoint/model settings on the host. New device-control commands, script execution, voice integration and Windows/Linux installers still need implementation.

The promotional film animates genuine installed screen media with reconstructed source-defined GUI placeholders. Cinematic dim/sleep behavior is a render treatment, not a newly implemented firmware feature.

OPEN REGISTER | ARTFEDDERSON.TECH / RONIN

# Before the next revision 1 / 3

Additional quantities and final part numbers remain open. Resolve these items in the next CAD pass.

Open item | Modeled baseline

Required confirmation

Additional 6 x 3 magnets | 14 | Additional quantity, grade, coating, polarity/orientation and retention fit.
Different M3 countersunk bolts | 11 | Length, head angle/diameter, drive, grade, quantity, thread engagement and countersink fit; existing model has 3 x16 and 8 x45.
Owner-requested 3 mm threaded magnets | 0 | Clarify M3 thread versus 3 mm body size, male/female thread, envelope, quantity, mounting and polarity.
Final heat-set inserts | 8 | Final PN, thread, OD/length, hole geometry, insertion method, quantity and pull-out test.
Display to LED bar 1 to LED bar 2 harness | 0 | Display output GPIO/header mapping, logic levels, +5V source/budget, common ground, LED revision pinout, connector housings/crimps, wire gauge, lengths, keyed orientation and test.
Mounts/fasteners/clips for two chosen LED positions | 0 | Support surfaces, hole alignment, insulated clearance, insert/bolt selection, connector access, diffuser retention and service removal; no mount validated.
USB extension cables | 0 | Connector genders, USB speed/power requirements, length, bend radius, panel retention and exact quantity.

OPEN REGISTER | ARTFEDDERSON.TECH / RONIN

# Before the next revision 2 / 3

Additional quantities and final part numbers remain open. Resolve these items in the next CAD pass.

Open item | Modeled baseline

Required confirmation

90 degree USB-C to USB-A cable | 0 | Connector genders/orientation, data capability, cable length, bend clearance, strain relief and exact quantity; separate from two modeled 180-degree USB adapters.
Possible ARCTIC P12 Slim PWM PST | 0 | Selection/quantity, airflow direction, 120 x120 x15 mm clearance, hole pattern, fan power/header budget, wiring and mount validation.
Mosfet.Party EPS power distribution adapter | 0 | Confirm product/revision/quantity, PSU cable compatibility, board bounds, mounting, both BC250 power paths and harness retention.
Mosfet.Party PS_ON control adapter | 0 | Confirm ATX button/header versus LITE variant, board bounds/holes, button/LED connector pinout, PSU and BC250 sense wiring, quantity and mounting.
Excess PSU cable retention | 0 | Choose case anchor/tie-point locations, zip-tie/mount PN/quantity, routing, bend radius, insulation, fan clearance and service slack.
Small/USB/LED/audio cable retention | 0 | Choose separate anchor/tie-point locations, zip ties/mounts/retainers, lengths, strain relief, connector access and service slack.
Speaker wiring and final speaker parts | 2 | Exact speaker PN/impedance/rating, PH2.0 housing/pin orientation, harness length, mounting and clearance.

OPEN REGISTER | ARTFEDDERSON.TECH / RONIN

# Before the next revision 3 / 3

Additional quantities and final part numbers remain open. Resolve these items in the next CAD pass.

Open item | Modeled baseline

Required confirmation

Wireless card and antenna identity | 0 | No explicitly named wireless card instance; confirm installed card PN, interface, adapter and antenna/bulkhead cable identities from owner evidence.
M.2 splitter identity | 1 | Manufacturer/PN, topology/interface compatibility, power, mounting and attached devices; generic CAD filename cannot establish exact purchased splitter.
Final SSD identities | 3 | PN/capacity/interface and role for 2 modeled 2230 and 1 modeled 2280 bodies.
USB hub identity | 1 | Exact PN, ports/speed, power source, cable and mounting.
PSU identity and cable set | 1 | Apevia 500 SFX filename only; confirm exact label PN/revision, connectors/pinouts and cable gauges.
Decompose the custom AM4 adapter subassembly | 1 | One imported custom CAD component contains 19 exported bodies. Identify fabricated parts and separately required hardware, checking against top-level washers, spacers and thumb nuts to avoid double-counting. Manufacturing/material and final physical quantities remain open; do not decompose bought board/PSU chips into separate purchases.
Other owner-mentioned missing components | None | Owner to identify remaining components; inventory is not a purchasing checklist.

RELEASE CHECKLIST | ARTFEDDERSON.TECH / RONIN
Checks before final build instructions.

Confirm these items before treating the concepts as assembly instructions.

Finalize hardware selection and source links. Compare required, purchased and modeled quantities. Resolve or remove placeholder parts.

Update the SolidWorks assembly with extra magnets, threaded magnets, inserts, power boards, selected cable ends, LED mounts and cable retention.

Check the rear printing strategy in the actual INDX slicer profile. Print and measure representative PCTG parts.

Verify all harness pin mapping and chosen board revisions. Measure lengths with service slack and document strain relief.

Generate original exploded views from that CAD revision. Write one mechanically verified operation per step, with its hardware count.

Check cover removal, fan clearance and LED mounting on the build. Repeat cooling checks with the enclosure installed. Record firmware and companion versions separately.

SOURCES / CREDITS | ARTFEDDERSON.TECH / RONIN
Source links and design credits.

Primary references researched 03 October 2026. Candidate identities do not prove the purchased SKU.

Rainbow on a Matchstick - Blamm / official design (https://github.com/VoronDesign/Voron-Hardware/tree/master/Daylight/Rainbow_on_a_matchstick)

ARCTIC P9 PWM PST Black - ACFAN00298A (https://www.arctic.de/en/P9-PWM-PST-Black/ACFAN00298A)

Optional ARCTIC P12 Slim PWM PST - ACFAN00187A (https://www.arctic.de/en/P12-Slim-PWM-PST/ACFAN00187A)

CrowPanel Advanced 5-inch ESP32-P4 - candidate DHE04005D (https://www.elecrow.com/crowpanel-advanced-5inch-esp32-p4-hmi-ai-display-800x480-ips-touch-screen-with-wifi-6.html)

Mosfet.Party - EPS 8-pin to dual Micro-Fit (https://mosfet.party/products/eps-8pin-to-dual-microfit)

Mosfet.Party - PS_ON PC-case-header variant (https://mosfet.party/products/adapter-4)

Mosfet.Party - PS_ON design (https://github.com/mosfetparty/bc250-psu-adapter)

3D-Fuel Natural Pro PCTG / material guidance (https://www.3dfuel.com/products/pro-pctg-natural-1-75mm)

3D-Fuel print-profile guidance (https://support.3dfuel.com/hc/en-us/articles/22046343945495-Pro-PCTG-Print-Profiles)

Prusa INDX 8-tool kit / print volume (https://www.prusa3d.com/product/indx-conversion-kit-8-toolhead/)

CNC Kitchen / PETG clarity experiment, inference for PCTG (https://www.cnckitchen.com/blog/transparent-fdm-3d-prints-are-clearly-stronger)

MandicReally: source CAD credit for the remixed 92 mm fan shroud, supplied by the owner. Exact original-model URL remains open; a different model is not substituted. Voron manuals informed documentation structure only; no artwork, page assets or prose are reused.

REVISION / PROVENANCE | ARTFEDDERSON.TECH / RONIN
Keep this manual with the CAD revision.

Editable companion data, BOM and open register accompany this PDF. Update figures when the CAD changes.

Source assembly: BC250-Assy.SLDASM
Export: 83 active instances / 34 unique paths / current native CAD tessellation.
Export SHA256: 6629e8ec61feadab36cd367e2baddc19778b2425403b07549a4b3b1a90aa8ac1

Saved assembly observation: 03 October 2026, 21:11:25 UTC; observed saved-file SHA256: 9373a60ab27ae99628ebbc556cbeacaa1fa84fe42846cb7406cfa16978e2c861

## Rev 0.3 / design and build preparation

This edition covers the exported CAD inventory; procurement and mechanical interfaces remain unfinished. It includes original lavender/sakura artwork, CAD locator views, LED mount and harness concepts, print trials and a revision register. The owner-proposed sequence starts on page 31. Final exploded views, physical fit validation, procurement and newly flashed features are still pending.

The repository CAD differs from this snapshot. Check current files and open issues for your build or remix; questions are welcome. When the project changes, update the affected BOM rows and links, record the CAD revision and refresh the diagram. Add assembly or test steps after verification. Keep unresolved decisions in the open register.

ASSEMBLY ORDER / OVERVIEW | ARTFEDDERSON.TECH / RONIN
Build it once. Keep access open.

This order comes from the owner's build plan. It will become the final assembly chapter after CAD and a physical build verify it.

Prepare on the bench | Assemble the machine | Close and commission
01 Test BC250 and prepare BIOS | 05 Backbone and mounts | 13 Power adapters and wiring
02 Install Linux on direct NVMe | 06 Aprons, speakers and display | 14 Relocate storage and add Wi-Fi
03 Prepare display and SD media | 07 Fans and shroud | 15 USB, covers and cable retention
04 Inserts and magnets | 08 PSU and IEC adapter | 16 First boot at stock settings
| 09-11 Heatsink conversion and APU cooler | Then: optional tuning, one change at a time
| 12 Matchsticks and their harnesses

## Why this order?

## Test the board before building around it. Install the display cables before the aprons close around the glass. Thread the fan cables before fastening the shroud. Leave cable access until the final cover

check.

## How to use the draft

Follow the order for planning. A step with an unresolved cut, pinout,

## fastener or mount needs its listed check before use. The appendix

keeps proposed hardware separate from the 83 modeled instances.

ASSEMBLY ORDER / PROPOSED | ARTFEDDERSON.TECH / RONIN

# 01 / Test the board before the case

Owner-proposed sequence. Confirm the details in the right-hand boxes before doing the work.

1

## Use the elektricM BC250 guides for the initial check. On the bench, connect the required power and display connections with no NVMe installed. Fit the stock cooling

components and working temporary fans before first power.

## 2 Make a brief first boot, record the BIOS version and confirm the board reaches firmware setup. Shut down after recording it. Keep cooling running throughout every

powered test and BIOS flash.

3

## Prepare the community BIOS procedure for this exact board. Record the selected

ROM, its hash, the stock backup and a recovery method before starting.

4

## Follow the selected guide and its matching toolkit. The linked kit's Flash.nsh expects Robin5.00. Its bundled stock image is not automatically the modified P3.00 ROM. Do

not combine filenames from another flashing script.

## Check before moving on

## A successful initial POST and a recorded BIOS version come before case assembly. Keep cooling active. The evidence does not establish

a safe uncooled boot interval.

## Still needs confirmation

## Board revision, owner-selected release, original backup and recovery procedure need recording. No BIOS has been flashed as part of

this documentation.

BC250 initial setup and BIOS flashing guide (https://elektricm.github.io/amd-bc250-docs/bios/flashing/) Original community BIOS project (https://gitlab.com/TuxThePenguin0/bc250-bios/)

ASSEMBLY ORDER / PROPOSED | ARTFEDDERSON.TECH / RONIN

# 02 / Install Linux with direct storage

Owner-proposed sequence. Confirm the details in the right-hand boxes before doing the work.

1

## Install the intended OS NVMe directly in the BC250 for this bench stage. Prepare the current Bazzite-Deck / Steam Gaming Mode installer using the linked guides. Keep the

display microSD card separate from this USB installer.

2

## Boot the installer normally from the firmware boot menu. If the board drops to an EFI

shell, use its mapping information to identify the actual USB filesystem and boot file. USB mappings vary. Do not assume one universal BLK0 or FS0 alias.

3

## Install to the intended NVMe and confirm it boots. Follow current kernel, Mesa and firmware guidance. The old-version Flatpak Mesa override on the wiki is not a blanket

instruction for a current installation.

4

## Shut down completely and disconnect the bench connections. Keep this same OS

drive for the later relocation step. This sequence does not call for an extra SSD.

## Check before moving on

The BC250 supports several Linux distributions.

## Bazzite and Arch-based options are our preferred starting points because the community has dedicated guides and tooling

for them. Bazzite is the worked example here.

## Still needs confirmation

Other distributions need compatible kernel,

## Mesa, firmware and governor setup. This is a project preference, not a measured ranking or a promise that every Linux image works

unchanged.

Owner-selected Bazzite guide (https://elektricm.github.io/amd-bc250-docs/linux/bazzite/) Community distribution choices (https://elektricm.github.io/amd-bc250-docs/linux/distributions/)

ASSEMBLY ORDER / PROPOSED | ARTFEDDERSON.TECH / RONIN

# 03 / Prepare the display on the bench

Owner-proposed sequence. Confirm the details in the right-hand boxes before doing the work.

1

## Use the display's matching firmware source and media revision. Compile and check a release before installing it. New LED, action-panel, gamepad and agent features are

planned work. They are not all present in the current firmware.

2

## Prepare a 16-32 GB or larger microSD card, subject to the selected card/filesystem requirements. Put the matching animation and audio assets in a BC250 directory at

the card root.

3

## The current V3 player expects day3, nite3, sleep3 and wake3 assets: .rvj animation files and .pcm audio files. These are firmware-specific media. Copying an ordinary MP4 into

that folder does not replace them.

4

## Check animation, sound and serial resource readings on the bench, then shut down and set the display aside. The existing UART0 resource-monitor link has shown host

values. A new firmware release has not yet been flashed.

## Check before moving on

## Current firmware reads the card at /sdcard/BC250. Keep all four scene pairs from one compatible media release. Preserve the user's card contents. The source player does

not format a failed card mount.

## Still needs confirmation

## A reproducible firmware build, release checksum, card filesystem and complete file manifest still need issuing. Confirm the actual

board model and speaker ratings before wiring.

ASSEMBLY ORDER / PROPOSED | ARTFEDDERSON.TECH / RONIN

# 04 / Install inserts, then magnets

Owner-proposed sequence. Confirm the details in the right-hand boxes before doing the work.

1

## Fit four heat-set inserts to each of the two printed 92 mm fan inserts: eight total. Test

the selected insert and PCTG pocket on a coupon before using the finished parts.

2

## Reserve four more inserts for the printed fan-filter mounts. These mounts are not

designed yet, so their insert holes and installation details remain pending.

3

## Install the 6 x 3 magnets in the printed parts, followed by the 10 x 2 magnets. Use the final pocket and retention method once they are tested. The current modeled counts

are 14 and 6 respectively.

4

## For magnet-to-magnet joints, pair the actual mating magnets and mark their orientation. For a cover that meets a steel screw head, check attraction and seating. A

steel screw head does not identify a magnet's polarity.

## Check before moving on

## All inserts must seat correctly without distorting their pockets. Trial-fit each magnetic joint

before trapping a magnet in a finished part.

## Still needs confirmation

Extra magnet locations, final quantities,

## adhesive or mechanical retention, grade and supplier part numbers remain open. The four

filter inserts are additional proposed hardware.

ASSEMBLY ORDER / PROPOSED | ARTFEDDERSON.TECH / RONIN

# 05 / Prepare the backbone

Owner-proposed sequence. Confirm the details in the right-hand boxes before doing the work.

1

## At the three BC250 mounting holes, prepare the proposed 6 mm spacer joints. The

owner's plan uses countersunk bolts from the rear and board screws from the front.

2

## Resolve that joint before fastening: the current CAD spacer reference is unthreaded nylon. Use a verified through-bolt stack or a correctly selected threaded standoff. Two

screws cannot independently fasten into an unthreaded spacer.

3

## Fit six threaded magnets behind the backbone with countersunk fasteners from the front. Confirm magnet body size, actual thread and screw length against the

purchased parts.

4

## Install the future fan-filter mounts at the bottom of the backbone once their geometry

and hardware are finalized.

## Check before moving on

## Check that front-facing heads sit flush and that no fastener enters board clearance. Trial-fit a rear-cover magnet against its intended

threaded magnet.

## Still needs confirmation

The spacer stack, rear bolt lengths,

## threaded-magnet part number and filter mounts remain unresolved. No torque is

specified before those joints are validated.

ASSEMBLY ORDER / PROPOSED | ARTFEDDERSON.TECH / RONIN

# 06 / Let the aprons hold the display

Owner-proposed sequence. Confirm the details in the right-hand boxes before doing the work.

1

## Install a speaker in each side apron. Fit the power button in the left apron and the USB

hub in the right apron.

2

## Connect the selected right-angle USB cable to the display's UART0 port. Prepare the

LED-control harness at the display only after its connector and pinout are verified.

3

## Slide the display into the left apron's tabs. Keep the speaker cable behind it. Hold the display while sliding the left apron into the backbone. The proposed fit leaves the

front glass slightly proud of the front opening.

4

## Slide in the right apron, guiding the display into its channels and corner tabs. Keep the right speaker cable behind the display. From the rear, connect both speaker cables to

the verified display connectors.

## Check before moving on

Support the glass until both aprons retain it.

## Check that every corner is seated and that no

cable is pinched behind the display.

## Still needs confirmation

## Confirm actual retention clearance, cable bend direction and speaker connectors. The owner's LED connector was unspecified. No display

GPIO or pin assignment is issued here.

ASSEMBLY ORDER / PROPOSED | ARTFEDDERSON.TECH / RONIN

# 07 / Fit the fans and thread the cables

Owner-proposed sequence. Confirm the details in the right-hand boxes before doing the work.

1

## Turn the shroud upside down and place the two 92 mm fans inside it. The owner's

airflow direction exhausts through the side of the shroud that the fan frames contact. Confirm the fans' airflow arrows against the final diagram.

2

## Place one printed fan insert over each fan. Support the backbone upside down or on

its side, then slide the shroud into place.

3

As the shroud enters, guide the USB-hub cable, power cable, LED-control cable,

## display USB cable and both fan cables through the rear opening. Keep all cables away

from fan blades and screw paths.

4

## Secure the assembly in all eight holes with the proposed eight M3 x 45 countersunk

screws, after checking head geometry, engagement and clearance in the real stack.

## Check before moving on

## Turn each fan by hand with power disconnected. Check cable clearance, the eight insert engagements and the intended

intake-to-heatsink airflow path.

## Still needs confirmation

## The replacement countersunk screw part number and filter interfaces remain open. The shroud remix is credited to MandicReally. Its

exact original-model URL is still needed.

ASSEMBLY ORDER / PROPOSED | ARTFEDDERSON.TECH / RONIN

# 08 / Install the PSU and IEC elbow

Owner-proposed sequence. Confirm the details in the right-hand boxes before doing the work.

1

## Return the backbone to its working orientation and slide the Apevia 500 W SFX PSU into the rear. The owner's proposed orientation places its fan away from the

backbone, with the AC inlet and power switch facing down.

2

## Secure it in the four mounting positions using screws that match the actual PSU thread. The owner suggested M3 x 8 countersunk screws or the supplied screws. M3 is

a candidate, not a confirmed PSU thread.

3 With AC disconnected, fit the selected 90-degree IEC adapter so its cable exit faces the

## rear. Check its connector type, rating, bend direction and cover clearance before

turning the assembly over.

4

## Leave the DC cables accessible for routing. Bundle excess PSU length later, after every

connection and cover-removal path is checked.

## Check before moving on

## The PSU is held securely without an overlong screw entering it. Its fan opening, switch and AC

connection remain accessible.

## Still needs confirmation

## Exact PSU SKU, screw thread and IEC-adapter part number are pending. Do not force a candidate screw into the PSU or modify its

supplied mains wiring.

ASSEMBLY ORDER / PROPOSED | ARTFEDDERSON.TECH / RONIN

# 09 / Prepare the heatsink conversion

Owner-proposed sequence. Confirm the details in the right-hand boxes before doing the work.

1

## Use the exact MandicReally conversion instructions and matching cooler adapter before cutting. Record the contact map and take clear photos of both PCB faces and

the original pad locations.

2

Remove the eight stock heatsink screws and retain them with their springs identified. Remove the stock heatsink from the PCB before any metal cutting.

3

## Clean the original paste and pad residue with the owner-specified 99% IPA and a soft

microfiber cloth, using a method suitable for the board. Let everything dry fully.

4

## The owner proposes dividing the heatsink into three sections around the central APU heatpipe section, using a metal-cutting bandsaw in skilled hands. Confirm the cut lines and heatpipe clearance first. Deburr and remove all metal debris before bringing

any section back to the PCB.

## Check before moving on

## Record which components originally contacted pads. Keep the PCB away from cutting and cleaning debris. Every cut section must be clean

and free of sharp edges.

## Still needs confirmation

## The exact creator conversion GitHub/video, cut drawing and fastener stack have not been confirmed. This page records the proposed operation. It does not issue an approved cut

plan.

ASSEMBLY ORDER / PROPOSED | ARTFEDDERSON.TECH / RONIN

# 10 / Refit the front heatsink sections

Owner-proposed sequence. Confirm the details in the right-hand boxes before doing the work.

1

## Use the recorded original contact map to identify the front-side components on either

side of the APU. Keep the APU paste area clear of putty.

2

The owner's UTP-6 starting deposit is approximately 4 mm high before compression. It is a starting amount, not the intended final chip-to-heatsink gap.

3

## Press the two smaller outside heatsink sections gently onto their intended contacts while aligning the screw holes. Check the compressed contact pattern rather than

using screw force to overcome a poor fit.

4

## The proposed stack reuses four original non-spring heatsink screws, with four M3 washers behind the PCB. Verify actual engagement, washer footprint and board

clearance before securing it.

## Check before moving on

Inspect contact coverage and squeeze-out.

## Confirm the sections sit as intended without board bowing or contact with nearby

components.

## Still needs confirmation

## The compressed gaps and putty contact map need physical verification. Four reused screws are a subset of the retained eight, not a new purchase. The four-washer proposal still needs

mapping to the three modeled washers.

ASSEMBLY ORDER / PROPOSED | ARTFEDDERSON.TECH / RONIN

# 11 / Cool the rear VRAM and APU

Owner-proposed sequence. Confirm the details in the right-hand boxes before doing the work.

1

## On each actual rear VRAM module, the owner proposes a UTP-6 ball approximately 6

mm tall before compression. The deposit height is not a final gap specification.

2

## Place the original center heatsink section against the rear VRAM and secure it through the cooler adapter with the correctly selected M3 hardware. Check all chip contacts

and neighboring clearances.

3

## Apply APU thermal paste. Arctic MX-6 is the owner's recommendation. Fit the selected APU cooler with its matching stainless mounting hardware, orienting the fins for the

case's airflow.

4

## After confirming the complete cooler stack, mount the BC250 at the three 6 mm spacer positions. The proposed board screws are three M3 x 8, subject to the

spacer-joint check on stage 05.

## Check before moving on

Verify paste contact, rear VRAM contact,

## adapter fit and PCB flatness. The cooler must not depend on cable pressure or contact with

the covers.

## Still needs confirmation

## Rear-sink screw quantity/length, exact cooler revision, adapter subparts and final thermal gaps remain open. Putty and paste quantities

are not yet a released purchasing specification.

ASSEMBLY ORDER / PROPOSED | ARTFEDDERSON.TECH / RONIN

# 12 / Connect fans and mount the LEDs

Owner-proposed sequence. Confirm the details in the right-hand boxes before doing the work.

1

## Connect the two 92 mm fan leads and the single proposed 120 mm fan to the selected three-to-one splitter. Route the leads through the large backbone opening, then

connect the splitter to CPU_FAN only after checking its electrical limits.

## 2 Mount the two Rainbow on a Matchstick boards and diffusers to their printed LED mounts using verified M3 hardware. Bolt the mounts to the backbone at the owner's

chosen CAD locations.

3

## Route the display-to-first-bar cable through the large left-side opening. The intended

first board is the left Matchstick. The owner describes its input connection at the top.

4

## Route the inter-bar cable from the left board under the PCB, around the lower edge of the rear VRAM heatsink, to the right board. Check actual DIN/DOUT labels against page

22. Physical top or bottom does not prove signal direction.

## Check before moving on

## Only the two ten-LED Matchsticks supply auxiliary RGB. Verify 5 V, ground and data at both ends before power. The reference connectors are not a straight-through

three-wire cable.

## Still needs confirmation

## LED mounts, display pinout, wire sizes, power budget and harness lengths remain open. If the third fan is a P12 Slim, all three fans have a

combined listed running current of 0.36 A.

## Startup current and CPU_FAN capacity are still

unverified.

Blamm / Rainbow on a Matchstick design (https://github.com/VoronDesign/Voron-Hardware/tree/master/Daylight/Rainbow_on_a_matchstick)

ASSEMBLY ORDER / PROPOSED | ARTFEDDERSON.TECH / RONIN

# 13 / Verify power before connecting it

Owner-proposed sequence. Confirm the details in the right-hand boxes before doing the work.

1

Select the exact Mosfet.Party PS_ON adapter and EPS power-adapter revisions. Follow the installation instructions for those purchased boards.

2

## The owner proposes extending the PS_ON ground lead by cutting and soldering an extension, routing it through the same left opening and beneath the PCB to the

identified ground pin. Confirm that modification, pin and insulation before making it.

3

## Provide proper insulation and strain relief. The suggested small amount of hot glue is

retention only. It does not verify a pinout or replace an electrically sound connection.

4

## Route the PSU PCIe and CPU EPS leads through the large left opening and connect each to its correct destination. They are distinct connections. The EPS adapter

supplements the onboard PCIe power. Swapping the leads can damage the board.

## Check before moving on

## With AC disconnected, compare connector labels, purchased-adapter instructions and the actual wiring. Check continuity and clearance

before any powered test.

## Still needs confirmation

## No PS_ON variant, modified ground-pin connection or EPS-board revision is approved by this draft. Do not infer compatibility from

similar connector housings.

Mosfet.Party BC250 hardware and installation references

ASSEMBLY ORDER / PROPOSED | ARTFEDDERSON.TECH / RONIN

# 14 / Relocate the NVMe and add Wi-Fi

Owner-proposed sequence. Confirm the details in the right-hand boxes before doing the work.

## 1 Move the same OS NVMe from the direct board slot to the selected extension assembly. The proposed extension plate uses four M3 screws on its mount. The mount

uses four more M3 screws at the backbone bottom.

2

## Leave the mount temporarily loose while arranging the cable, with the machine

unpowered. Final tightening happens before closure and operation.

3

## Attach the correct antenna leads to the Wi-Fi 7 M.2 board. Install the selected splitter into the BC250 M.2 slot. The owner proposes the Wi-Fi board in the rear slot near the

retaining screw.

4

## Route the NVMe extension along the rear backbone, through a service loop and the

smaller opening beside the BC250, then over the Wi-Fi adapter to the remaining slot.

## Use a bend radius allowed by the cable. The proposed 90-degree change of direction

is not an instruction to crease it.

## Check before moving on

## Confirm slot keying, lane support and the actual Wi-Fi/NVMe topology before tightening. Check

cable retention and the cooler airflow path.

## Still needs confirmation

## Exact splitter, Wi-Fi board, extension cable and mount geometry remain open. The three modeled SSD instances do not mean three OS

drives are required by this sequence.

ASSEMBLY ORDER / PROPOSED | ARTFEDDERSON.TECH / RONIN

# 15 / Finish routing before the covers

Owner-proposed sequence. Confirm the details in the right-hand boxes before doing the work.

1

## Trial-fit the front magnetic cover against its intended screw heads. Check seating and

attraction, then remove it again if it would obstruct cable work.

2

## Route the display and hub USB connections along the rear. Use the chosen extensions or 180-degree adapters as needed. The owner prefers a blue USB 3.1 host port for the display and a black USB 2.0 port for the hub. Verify actual port labels and connector

fit.

3

## Fit the antenna connectors through the rear cover. Secure excess PSU wiring and the smaller USB/audio/LED cables at verified tie points. Keep the fan-to-heatsink-to-top

airflow path clear.

4

## Tighten the NVMe mount and check every cable and fan. Attach the rear cover to the six threaded magnets, checking mating polarity. Fit the top cover to the

backbone/front cover and confirm that all covers remove without pulling on a cable.

## Check before moving on

## A cover should close without acting as a cable

clamp. Remove and refit each cover once.

## Check fans rotate freely and connectors retain

enough service slack.

## Still needs confirmation

## Tie locations, connector angles and final cable lengths still need a physical trial and CAD updates. Steel screw-head attraction and magnet-to-magnet polarity are different

checks.

ASSEMBLY ORDER / PROPOSED | ARTFEDDERSON.TECH / RONIN

# 16 / Commission at stock settings

Owner-proposed sequence. Confirm the details in the right-hand boxes before doing the work.

1

## Connect keyboard, mouse and DisplayPort monitor. Use Ethernet for first startup if

available. Check the cooling connections, then start the machine at stock settings.

2

## Confirm Linux boots, configure Wi-Fi and check storage and USB devices. Install BC250

Control Center using the current release instructions for the selected distribution.

3

## Connect the Ronin host resource-monitor service to the display and compare its readings with the host. The Windows bench monitor has produced readings. Linux

hardware validation and finished companion installers remain pending.

4

## Record idle and load behavior with the covers fitted. Only after the stock build is stable should optional core activation, overclocking or fan-curve changes be

considered. Change one setting at a time and retain a recovery path.

## Check before moving on

## Check fan operation and temperatures under load, plus storage, Wi-Fi, display, speakers and USB. Record the software/BIOS versions with

the results.

## Still needs confirmation

## This draft supplies no promised overclock or performance result. Gamepad wake, advanced ARGB, context-sensitive action buttons and the AI companion portal still need firmware and

host integration.

BC250 Control Center project and releases (https://github.com/movacx/bc250-control-center)

HARDWARE / PROPOSED CHANGES | ARTFEDDERSON.TECH / RONIN

# Build-plan hardware 1 / 8

Owner quantities below are proposals. They are not final required quantities or instructions to order replacements.

Proposed item | Owner qty | Related CAD baseline | Confirm before release
Fan-insert heat-set inserts | 8 | See CSV for related modeled parts | Eight proposed, four per fan insert. Select the insert dimensions and validate the PCTG pocket.
Future fan-filter mount heat-set inserts | 4 | See CSV for related modeled parts | Four additional inserts reserved for the future filter mounts. Their holes and thread are not designed yet.
Printed fan-filter mounts | TBD | No named CAD match | Design the filter mounts and select the filter before fixing mount quantity or hardware.
6 x 3 magnets in printed parts | TBD | See CSV for related modeled parts | Current CAD has 14. More locations are planned. Final count, grade and retention need checking.
10 x 2 magnets in printed parts | TBD | See CSV for related modeled parts | Current CAD has 6. Verify the pockets, mating parts, retention and selected supplier.
Threaded magnets on backbone | 6 | See CSV for related modeled parts | Six behind the backbone. Confirm actual M3 thread, body size and rear-cover mating orientation.

The frozen inventory remains 83 instances / 34 CAD paths. The complete proposed-hardware CSV/JSON contains 59 rows, including context and reused parts. Blank final quantities and purchase part numbers mean unresolved.

HARDWARE / PROPOSED CHANGES | ARTFEDDERSON.TECH / RONIN

# Build-plan hardware 2 / 8

Owner quantities below are proposals. They are not final required quantities or instructions to order replacements.

Proposed item | Owner qty | Related CAD baseline | Confirm before release
Countersunk bolts for threaded magnets | TBD | No named CAD match | Select count, thread, length and countersunk head against the six actual magnet joints.
6 mm BC250 spacers | 3 | See CSV for related modeled parts | Three positions, 6 mm long. Current modeled spacers are unthreaded nylon. Resolve the two-sided screw stack.
Rear countersunk bolts for BC250 spacer joint | TBD | See CSV for related modeled parts | Confirm the rear bolts and their engagement with the selected spacer joint. Existing bolts and nuts may be reused.
BC250-to-spacer screws | 3 | See CSV for related modeled parts | Three M3 x 8 proposed at the board. Verify engagement, insulation and clearance after selecting the spacer joint.
Fan/shroud countersunk screws | 8 | See CSV for related modeled parts | Eight M3 x 45 match the modeled count and nominal length. Select the countersunk head and check the assembled stack.
PSU mounting screws: M3x8 candidate OR supplied screws | 4 | See CSV for related modeled parts | Four screws total. Use the actual PSU thread. M3 x 8 and supplied screws are alternatives, not eight screws.

The frozen inventory remains 83 instances / 34 CAD paths. The complete proposed-hardware CSV/JSON contains 59 rows, including context and reused parts. Blank final quantities and purchase part numbers mean unresolved.

HARDWARE / PROPOSED CHANGES | ARTFEDDERSON.TECH / RONIN

# Build-plan hardware 3 / 8

Owner quantities below are proposals. They are not final required quantities or instructions to order replacements.

Proposed item | Owner qty | Related CAD baseline | Confirm before release
90 degree IEC adapter | 1 | No named CAD match | One right-angle adapter. Confirm IEC type, electrical rating, bend direction and rear-cover clearance.
120 mm fan | 1 | See CSV for related modeled parts | One 120 mm fan in the proposed sequence. Exact model and thickness remain open. Do not automatically add a second cooler fan.
Three-to-one fan splitter | 1 | See CSV for related modeled parts | One three-output splitter. Check total running/startup current, CPU_FAN limit, PWM wiring and a single tach signal.
Original stock heatsink screws removed and retained | 8 | See CSV for related modeled parts | Keep all eight original screws and identify their springs. These retained parts are not a new purchase.
Original screws reused for outer heatsink sections | 4 | See CSV for related modeled parts | Reuse four of the retained eight for the outside heatsink sections. Confirm the exact screw stack.
M3 washers behind PCB for outer sink sections | 4 | See CSV for related modeled parts | Four washers proposed. CAD currently has three washers of unresolved role. Compare joints before deciding what to buy.

The frozen inventory remains 83 instances / 34 CAD paths. The complete proposed-hardware CSV/JSON contains 59 rows, including context and reused parts. Blank final quantities and purchase part numbers mean unresolved.

HARDWARE / PROPOSED CHANGES | ARTFEDDERSON.TECH / RONIN

# Build-plan hardware 4 / 8

Owner quantities below are proposals. They are not final required quantities or instructions to order replacements.

Proposed item | Owner qty | Related CAD baseline | Confirm before release
M3 screws for rear center heatsink through cooler adapter | TBD | See CSV for related modeled parts | Choose quantity, length and head after checking the rear heatsink and cooler adapter. No complete screw stack is confirmed.
Cooler's stainless mounting hardware | TBD | See CSV for related modeled parts | Use the mounting kit that matches the selected cooler and adapter. Confirm each physical part in the imported adapter assembly.
Upsiren UTP-6 thermal putty: front components | TBD | No named CAD match | UTP-6, about 4 mm initial deposit height before compression. Verify the contact map and final gap. Mass remains unknown.
Upsiren UTP-6 thermal putty: rear VRAM | TBD | No named CAD match | UTP-6, about 6 mm initial ball height per rear VRAM module before compression. Confirm coverage and final gap.
Arctic MX-6 thermal paste | TBD | No named CAD match | Arctic MX-6 is the recommended APU paste. Determine the amount from the verified cooler/contact procedure.
Display microSD card | 1 | No named CAD match | One display card, 16-32 GB or larger proposed. Confirm capacity, filesystem, speed and matching firmware media.

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

HARDWARE / PROPOSED CHANGES | ARTFEDDERSON.TECH / RONIN

# Build-plan hardware 5 / 8

Owner quantities below are proposals. They are not final required quantities or instructions to order replacements.

Proposed item | Owner qty | Related CAD baseline | Confirm before release
90 degree USB cable to display UART0 | 1 | See CSV for related modeled parts | One right-angle cable at UART0. Check connector type, exit direction, data support and length.
LED mounts/brackets | TBD | No named CAD match | Mounts are not modeled yet. Confirm PCB-hole dimensions, diffuser clearance, removal access and bracket quantity.
M3 screws for Matchstick/diffuser to mounts | TBD | See CSV for related modeled parts | M3 hardware proposed for board/diffuser mounting. Select quantity and length after the LED mounts are designed.
Bolts for LED mounts to backbone | TBD | No named CAD match | Choose bracket-to-backbone fasteners after checking the available holes, countersinks and electrical clearance.
Display-to-first Matchstick control harness | 1 | No named CAD match | One display-to-left-board harness. Display connector, GPIO, logic level, wire size and power source remain open.
First-to-second Matchstick bridge harness | 1 | No named CAD match | One left-to-right bridge. Verify DIN/DOUT mapping and the measured route around the rear VRAM heatsink.

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

HARDWARE / PROPOSED CHANGES | ARTFEDDERSON.TECH / RONIN

# Build-plan hardware 6 / 8

Owner quantities below are proposals. They are not final required quantities or instructions to order replacements.

Proposed item | Owner qty | Related CAD baseline | Confirm before release
Mosfet.Party PS_ON adapter | 1 | No named CAD match | One Mosfet.Party adapter. Confirm the purchased variant and approved ground connection before extending its lead.
Mosfet.Party power adapter (EPS intent) | 1 | No named CAD match | One Mosfet.Party EPS power adapter. Verify the purchased revision and distinct EPS/PCIe connections.
PS_ON ground extension wire and insulation/strain relief | TBD | No named CAD match | Extension length, gauge, insulation and strain relief depend on the selected adapter and verified route.
NVMe extension cable/assembly | 1 | No named CAD match | One extension assembly. Confirm electrical compatibility, connector fit, length and minimum bend radius.
NVMe extension plate | 1 | No named CAD match | One plate proposed. Confirm its actual design and SSD/extension mounting interfaces.
NVMe mount | 1 | No named CAD match | One bottom mount proposed. Add it to CAD and verify airflow, cable access and cover clearance.

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

HARDWARE / PROPOSED CHANGES | ARTFEDDERSON.TECH / RONIN

# Build-plan hardware 7 / 8

Owner quantities below are proposals. They are not final required quantities or instructions to order replacements.

Proposed item | Owner qty | Related CAD baseline | Confirm before release
M3 screws: extension plate to NVMe mount | 4 | No named CAD match | Four M3 screws, plate to mount. Length and head depend on the final printed stack.
M3 screws: NVMe mount to backbone | 4 | No named CAD match | Four M3 screws, mount to backbone. Arrange wiring while loose, then secure before operation.
Same OS NVMe reused after installation | 1 | See CSV for related modeled parts | The same OS drive moves from direct installation to the extension. It is not an additional drive order.
Wi-Fi 7 M.2 board | 1 | No named CAD match | One Wi-Fi 7 board proposed. Exact radio, keying, driver support and splitter compatibility need documenting.
USB extension cables (alternative) | TBD | No named CAD match | Choose extensions or compatible 180-degree adapters as the route requires. Do not sum both alternatives automatically.
180 degree USB adapters (alternative) | TBD | See CSV for related modeled parts | Alternative to USB extensions where suitable. Confirm connector orientation, data support and clearance.

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

HARDWARE / PROPOSED CHANGES | ARTFEDDERSON.TECH / RONIN

# Build-plan hardware 8 / 8

Owner quantities below are proposals. They are not final required quantities or instructions to order replacements.

Proposed item | Owner qty | Related CAD baseline | Confirm before release
Zip ties | TBD | No named CAD match | Count and size follow the real cable bundles. Keep fans, vents and cover-removal paths clear.
Cable anchors/tie points/harness retention | TBD | No named CAD match | Design tie points and strain relief after routing the actual cables. Cover panels should not support heavy PSU bundles.
Fan filter/media | TBD | No named CAD match | Select filter size/material and service access together with the future printed mounts.

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

BUILD ORDER / SOURCE CHECKS | ARTFEDDERSON.TECH / RONIN
What this revision actually confirms.

The owner supplies the intended order. Linked project sources inform the checks. They do not certify this physical build.

Evidence | Status in this edition
Owner plan and clarification | Assembly intent and proposed hardware are recorded in the companion data. The 4 mm / 6 mm UTP-6 deposits are starting amounts before compression.
BIOS and installer references | Owner-selected wiki and original BIOS project checked. The candidate modified ROM hash is recorded. No new board backup or BIOS flash was performed for this documentation.
Linux choice | Bazzite is the worked installation example. Other compatible distributions remain options. Bazzite and Arch-based choices have dedicated community guidance.
Creator conversion and hardware | MandicReally credit retained. Exact conversion cut plan, selected cooler stack, PS_ON variant, harness pinout and fan-header budget remain open.
Proposed quantities | Eight heat-set inserts for the fans plus four for the filter mounts are proposed allocations. Four reused screws are within the original eight. PSU and USB alternatives are not added together.
Release checks | Final exploded views and installation details follow completed CAD and physical verification. Existing working display behavior stays distinct from planned functions.

See the linked references in this manual. Proposed hardware: BC250_Proposed_Hardware_Rev_0p3.json. The 21-item original open register is preserved; additional build-plan checks add to it.

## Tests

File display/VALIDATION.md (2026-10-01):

# Migration validation

The panel package has moved together into `display/`; paths below are relative to that package. These are the original migration results, not a claim of a new hardware test after the move.

Validated during preparation on Windows x64:

* Public source and media push succeeded; a fresh anonymous clone completed.
* 2,154 text files passed a scan for common credential/private-key patterns before publication. Runtime logs, PID state, raw flash recovery backups and personal path provenance were excluded from publication.
* All 13 dependency ZIPs passed SHA256 and ZIP CRC checks. GitHub's recorded SHA256 digest and size matched every local archive. An anonymous release download also matched its expected hash.
* The relocated Python 3.12 environment imported companion, media and ESP-IDF packages successfully; the relocated Python 3.14 environment ran esptool 5.4.0.
* Seven Windows temperature tests and three collector tests passed using the relocated Python. The older collector test runner requires `PYTHONPATH` to include `project/outputs/Resource-Panel`.
* A complete clean ESP32-P4 firmware build succeeded using only the relocated SDK, compilers, Git and Python environments. The application occupied `0x339630` bytes with 18% of its partition free. The rebuilt binary was not flashed; the previously installed v3 release remains the recommended known device build.

The complete offline package retains private recovery/history data not present here. No board flash, SD reformat or physical wiring change was performed as part of migration. A new PC still needs a live-device check of its own USB port, temperatures and media playback.

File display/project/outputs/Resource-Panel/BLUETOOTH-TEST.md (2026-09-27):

# GameSir display-wake test

Current evidence: the Nova 2 Lite_G paired and opened its BLE HID service on the panel. A/Home presses in that mode did not produce input reports. Android/yellow mode has not yet appeared in the BLE scan. This does not establish that the controller is Classic-only in every mode.

The next firmware wakes the display when a GameSir connection successfully opens. It does not interpret Home-button packets from an already-connected controller, and it does not operate any BC250 power-switch output.

After firmware installation is confirmed:

1. Keep the display awake. Hold Home + RB for two seconds to select G-Touch mode (cyan). If needed, hold Home + Screenshot for three seconds to enter rapid-flashing pairing mode. These are the combinations in GameSir's current official manual; firmware variations may differ.
2. Wait for the display's status to say GameSir connected. Pairing can take several seconds.
3. Turn the controller off and wait for the panel to report disconnected. Put the display to sleep using its touch button.
4. Turn the controller back on using Home in the same mode. Successful reconnection should wake the display. This is the test still requiring physical confirmation.

Simply putting the display to sleep while leaving the controller connected will not create a new connection event. A single Home press in that situation has no mapped wake action yet.

Bluetooth handoff to the BC250's separate adapter is not implemented. Do not assume the controller can be connected to both hosts simultaneously or that the same mode will suit PC gaming. The relay and standby-power wiring are separate future tests.

Official mode reference: https://gamesir.com/support/manuals/gamesir-nova-2-lite

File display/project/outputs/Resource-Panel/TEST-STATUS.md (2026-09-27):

# Sakura dashboard test status

## September 23 media update — installed

User confirmed Windows CPU temperature now works and supplied dayidle, nightidle, sleepytime, and wakeuptime MP4s. User explicitly requested each file's own audio, with transition audio allowed to continue into idle playback.

Prepared full 20.1-second idle loops at 10 fps. Both transition videos have black tails beginning at 5.2 seconds; these video tails were removed while full approximately 7.8/9.13-second audio was preserved. All 506 converted JPEG frames and four PCM tracks validated. Originals and conversion manifest are in video/movies-v3.

Player now uses elapsed-time frame selection and per-clip audio. On transition completion, remaining transition audio plays over the idle scene before handing over to idle audio at the corresponding elapsed position. Muting leaves the media clock running. This behavior still needs physical validation.

The first large-packet upload rejected a packet and aborted safely. Added per-packet CRC32 checks, bounded retries, an 8 KB UART receive buffer, and a larger receiver stack. Corrected firmware built/flashed with verification. All eight v3 files transferred and passed SHA256 checks. After restart, the complete v3 video/audio set loaded with 4,687,060 bytes of PSRAM remaining. Initial measured playback is 10.1 fps. Loading completed about 47 seconds after boot (the built-in scene remains available while loading). Live monitoring resumed without reported companion errors. Physical loop/audio-tail confirmation is pending. Prior v2 media is preserved as fallback.

## Windows temperature live verification — 2026-09-20

Libre Hardware Monitor's installed .NET 10 build returned Invalid namespace for WMI. Its local HTTP feed on port 8085 works with the user-selected 0.0.0.0 listener. The companion connects only to 127.0.0.1. This release supplies unit-bearing strings even in RawValue; the reader now handles Celsius/Fahrenheit strings, decimal commas, numeric values, and missing data. CPU distance-to-TjMax values are excluded. Seven sensor tests passed; a live read selected CPU Package at 69.0 C. The persistent companion restarted successfully with this fix. Physical panel temperature confirmation remains pending. A 0.0.0.0 listener may be accessible on the LAN depending on firewall rules.

## Settings / QR update — 2026-09-20

Added SETTINGS with a 225x225 QR code, literal official Libre Hardware Monitor release URL, installation guidance, Close control, and current USB/temperature-received status. The QR image was independently decoded using ZXing and matched the exact intended HTTPS URL. This is a helper-download link; the companion package has no public hosting URL yet.

Added optional background WMI polling to the Windows companion. Tests passed for CPU package preference, AMD identification, excluding GPU/disk sensors, invalid data, and stale-data expiry; the existing three collector tests also passed. Real Libre Hardware Monitor sensor collection and physical QR scanning are not yet verified. Existing video/audio assets are unchanged.

## Current update — 2026-09-20

User confirmed the earlier video's colors were correct and flashing was absent. The procedural stronger-motion preview was rejected and never installed.

User supplied day.mp4 (day to night) and night.mp4 (night to day), and confirmed day.mp4 is the nature-only audio source. Four playback sections have been prepared and all 124 JPEG frames validated. Source and segment details are in video/user-clips/README.md.

The new firmware caches the four clips in PSRAM, plays transitions once, loops the opening sections, and provides a Mute / Sound control for a shared 4.7-second nature loop. It preserves the original artwork clips as fallback. Physical verification of playback, transitions, and sound remains pending.

The literal `f` readings were caused by using LVGL's minimal formatter with CONFIG_LV_USE_FLOAT disabled. Labels now use libc snprintf followed by lv_label_set_text. The Windows collector returned actual CPU/RAM/disk numbers when checked; temperature remains null because this collector does not provide Windows CPU temperature.

Firmware dashboard-user-movies.bin built and flashed with verification. SHA256: 3A49FC45DFC09D237EE76C71BE90BF0D01F50C8CBE1E78DFCA92F1B13BEF8C51. All four video files and nature2.pcm transferred and passed SHA256 verification. After restart, logs confirm all clips cached in PSRAM and nature audio initialized. Daylight playback measures 10.6 fps against the 12 fps target. Live monitoring resumed. User visual/audio confirmation is pending; successful initialization alone does not establish perceived audio quality or display stability.

## Current update — 2026-09-19

- The inserted 32 GB card mounts successfully alongside the C6 radio. Both day and night clips were transferred over USB serial and SHA256 verified. No card formatting or unrelated file removal occurred.
- Full-screen hardware-JPEG playback is implemented. Each clip contains 60 distinct 800x480 frames, requested at 15 fps. These animate the painted environment; the character's standing/sleeping poses still crossfade.
- Initial actual delivery was about 5.3 fps by day and 7 fps by night. Timing measurements found approximately 103 ms card read, 5 ms decode, and 77 ms waiting to read the scene state per daylight frame. The unnecessary scene-state lock wait is now removed using an atomic state.
- User reported inverted-looking video colors in both scenes. Hardware pixel diagnostics identified byte ordering opposite LVGL's native RGB565. The current update converts decoded video pixels only; the LCD and resource text configuration are unchanged. Physical confirmation remains pending.
- The correction was flashed and hash-verified, and monitoring restarted. First daylight timing is 6.8 fps: setup 0.1 ms, card read 111.2 ms, decode plus pixel conversion 26.6 ms, presentation 7.6 ms. Card reading and the conversion are the next optimization targets; 15 fps has not been achieved.
- The RGB driver now uses internal bounce buffers and the matching bounce-frame-complete synchronization. Earlier fixes did not eliminate long-run flashing; stability of this version still requires a longer physical test.
- GameSir G-Touch BLE pairing previously succeeded. The firmware now requests display wake on a successful new HID connection; user confirmation is pending. No input reports were received during the earlier A/Home test. Home-button mapping, gaming handoff, and BC250 relay output remain unfinished.
- Current experimental binary: firmware/dashboard-video-test.bin. Matching sources: video-dashboard-main.c, panel-video.c, panel-bluetooth.c, display-driver-video.c. Earlier dashboard.bin remains the artwork-only fallback.
- Windows resource monitoring runs persistently in the background. Linux hardware validation, native USB video streaming, and USB microphone/speaker operation remain pending.

Earlier entries below are historical and may describe superseded builds.

- Built for Elecrow Advanced 5-inch ESP32-P4 V1.0, ESP-IDF 5.5.4, LVGL 9.1.0.
- Original factory backup remains in ../Panel-Recovery.
- Day/night assets embedded; 18 moving petals, three drifting mist shapes, 2.2-second pose crossfade.
- First artwork build showed incorrect colors with flashing rectangles during redraw, reported by user.
- Found vendor display configuration `swap_bytes=true` with direct frame buffers. The LVGL port swaps the buffer in place during flush. Disabled byte swapping for the native parallel RGB565 display.
- Corrected app built and flashed to COM10 at 0x10000; flash hash verification passed. Awaiting user's visual confirmation of correction and sleep/touch behavior.
- Corrected dashboard.bin SHA256: 94AED0635D86E43342D9A3C3A43E3AA539AADD51902F79189CF1E820ED9EDF46.
- Companion sensor tests: 3 passed. USB connection on Windows confirmed. Linux hardware test remains pending.
- Host reconnect/resume wake behavior implemented; still requires physical observation. Regular telemetry does not intentionally wake manual display sleep.
- Controller: Nova 2 Lite. User has it ready; asked them to select Android Bluetooth mode (yellow, rapid flash) and leave it unpaired. Awaiting confirmation of that mode.
- Windows BLE scanner prepared at ../../work/scan-controller.py; initial scan before pairing readiness found no matching advertisement, which does not establish incompatibility. No pairing or controller firmware change performed.
- No Bluetooth implementation or BC250 power-switch output is enabled in this dashboard build.

Artwork generated with the built-in image generation tool. Original PNGs and full prompts are in art/. Firmware source is dashboard-main.c; vendor display correction is in display-driver.c. Development project remains ../../work/panel-test.

## Update: confirmed display and working Bluetooth scan

User confirmed resource readings are visible and night scene stable after full-frame double buffering, explicit ivory label colors on a lighter pine-green card, and disabling night mist. 36 petals, swaying transparent sakura branch, water ripples, cloud drift added. Day/night backlight now 60%/12%. Persistent monitor manager starts/stops verified Python processes and captures bounded panel-runtime.log.

Bluetooth test initially failed at startup due to internal-RAM SDIO mempool allocation. Resolved using ESP_HOSTED_MEMPOOL_PREFER_SPIRAM, eight-entry TX/RX queues, Bluetooth allocation from PSRAM first, malloc internal threshold 1024 and FreeRTOS 1000 Hz. Factory C6 reports hosted version 2.3.0, BLE/HCI supported. Its controller-init RPC is unsupported, so the test uses the already-running factory HCI controller. Radio now reaches "BT: searching for GameSir" with no C6 firmware rewrite. Updated diagnostic app flashed and verified; current panel runs dashboard-bluetooth-test.bin. dashboard.bin remains the user-verified art-only fallback.

GameSir Nova 2 Lite_G advertised BLE HID UUID 1812 at [controller address omitted]. Windows connected but did not expose HID service through Bleak; no permanent Windows pairing requested. Panel now scans and attempts HID pairing with the GameSir name. Awaiting user re-entry into rapid-flashing mode. No relay/power output or mapped Home wake action enabled yet. panel_bluetooth.c is in the development project; exports panel_bt_start/panel_bt_poll called by main.c. Public dashboard-main.c remains the art-only fallback source, not the current BT test main.

User has a 16 or 32 GB microSD available. No card formatted or files erased. Elecrow V1.0 Lesson12 bsp_sd uses SDMMC slot0, CLK43 CMD44 D039 width1 at10MHz; C6 uses slot1. Card support is not yet added to dashboard. User asks about full-screen animation and BC250 streaming. Earlier advice favoring layers was too categorical: compressed MJPEG with P4 hardware JPEG decoder should be benchmarked from SD/native USB or Wi-Fi. Current UART0 USB telemetry is115200 and not suitable for video. Need native USB port wiring/speed verification before promising streaming. Keep local night loop for host-off operation. Hardware JPEG docs IDF5.5.4 reports isolated800x480 decode253fps, not end-to-end screen performance. No video renderer/decoder implemented yet.

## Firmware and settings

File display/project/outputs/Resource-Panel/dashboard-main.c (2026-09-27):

#include "main.h"
#include "esp_lvgl_port.h"
#include "esp_system.h"
#include "bsp_mic.h"
#include "bsp_audio.h"
#include "driver/uart.h"
#include "freertos/queue.h"
#include "cJSON.h"
#include <math.h>
#include <string.h>

typedef struct {char host[64];double cpu,ram,used,total,disk,temp;bool has_temp,wake;} metrics_t;
static QueueHandle_t samples;
static lv_obj_t *host_label,*cpu_label,*ram_label,*disk_label,*temp_label,*link_label,*audio_label,*audio_button;
static int64_t last_received;
static bool was_connected,sleeping;
static lv_obj_t *night_image,*panel,*petals[36],*mist[3],*ripples[10],*clouds[3],*branch;
static int night_opacity;
extern const uint8_t branch_data[] asm("_binary_branch_argb_start");
static const lv_image_dsc_t branch_art={.header={.magic=LV_IMAGE_HEADER_MAGIC,.cf=LV_COLOR_FORMAT_ARGB8888,.w=360,.h=150,.stride=1440},.data_size=216000,.data=branch_data};
static void set_sleep(bool value);
extern const uint8_t day_data[] asm("_binary_day_rgb565_start");
extern const uint8_t night_data[] asm("_binary_night_rgb565_start");
static const lv_image_dsc_t day_art={.header={.magic=LV_IMAGE_HEADER_MAGIC,.cf=LV_COLOR_FORMAT_RGB565,.w=800,.h=480,.stride=1600},.data_size=768000,.data=day_data};
static const lv_image_dsc_t night_art={.header={.magic=LV_IMAGE_HEADER_MAGIC,.cf=LV_COLOR_FORMAT_RGB565,.w=800,.h=480,.stride=1600},.data_size=768000,.data=night_data};
static void audio_worker(void *arg){
 (void)arg;esp_err_t err=mic_read_to_audio(5);
 if(lvgl_port_lock(0)){lv_label_set_text(audio_label,err==ESP_OK?"Playback finished":"Audio test failed");lv_obj_remove_state(audio_button,LV_STATE_DISABLED);lvgl_port_unlock();}
 vTaskDelete(NULL);
}
static void record_clicked(lv_event_t *e){
 (void)e;lv_obj_add_state(audio_button,LV_STATE_DISABLED);lv_label_set_text(audio_label,"Speak for 5 seconds...");
 if(xTaskCreate(audio_worker,"audio_test",4096,NULL,5,NULL)!=pdPASS){lv_obj_remove_state(audio_button,LV_STATE_DISABLED);lv_label_set_text(audio_label,"Audio task unavailable");}
}
static bool number(cJSON *j,const char *key,double min,double max,double *out){
 cJSON *v=cJSON_GetObjectItemCaseSensitive(j,key);
 if(!cJSON_IsNumber(v)||!isfinite(v->valuedouble)||v->valuedouble<min||v->valuedouble>max)return false;
 *out=v->valuedouble;return true;
}
static void parse_line(char *line){
 cJSON *j=cJSON_Parse(line);if(!j)return;
 metrics_t m={0};double version;
 bool ok=number(j,"v",1,1,&version)&&number(j,"cpu",0,100,&m.cpu)&&number(j,"ram",0,100,&m.ram)&&number(j,"disk",0,100,&m.disk)&&number(j,"used",0,1000000,&m.used)&&number(j,"total",0.1,1000000,&m.total);
 cJSON *h=cJSON_GetObjectItemCaseSensitive(j,"host");cJSON *o=cJSON_GetObjectItemCaseSensitive(j,"os");
 if(!cJSON_IsString(h)||!cJSON_IsString(o))ok=false;
 if(ok){
  snprintf(m.host,sizeof(m.host),"%.40s | %.16s",h->valuestring,o->valuestring);
  for(char *p=m.host;*p;p++)if((unsigned char)*p<32)*p=' ';
  m.wake=cJSON_IsTrue(cJSON_GetObjectItemCaseSensitive(j,"wake"));
  m.has_temp=number(j,"temp",-40,150,&m.temp);
  xQueueOverwrite(samples,&m);
 }
 cJSON_Delete(j);
}
static void receiver(void *arg){
 (void)arg;char line[512];size_t n=0;bool discard=false;uint8_t bytes[128];
 for(;;){int count=uart_read_bytes(UART_NUM_0,bytes,sizeof(bytes),pdMS_TO_TICKS(200));
  for(int i=0;i<count;i++){
   char c=bytes[i];if(c=='\n'){if(!discard){line[n]=0;parse_line(line);}n=0;discard=false;}
   else if(!discard&&c!='\r'){if(n<sizeof(line)-1)line[n++]=c;else discard=true;}
  }
 }
}
static void update(lv_timer_t *t){
 (void)t;metrics_t m;
 if(xQueueReceive(samples,&m,0)==pdTRUE){
  if(sleeping&&(m.wake||esp_timer_get_time()-last_received>5000000))set_sleep(false);
  last_received=esp_timer_get_time();was_connected=true;
  lv_label_set_text(host_label,m.host);
  lv_label_set_text_fmt(cpu_label,"CPU LOAD\n%.1f %%",m.cpu);
  lv_label_set_text_fmt(ram_label,"RAM\n%.1f %%\n%.1f / %.1f GiB",m.ram,m.used,m.total);
  lv_label_set_text_fmt(disk_label,"SYSTEM DISK\n%.1f %% used",m.disk);
  if(m.has_temp)lv_label_set_text_fmt(temp_label,"CPU TEMP\n%.1f C",m.temp);
  else lv_label_set_text(temp_label,"CPU TEMP\nN/A");
  lv_label_set_text(link_label,"USB connected - live readings");
 }else if(was_connected&&esp_timer_get_time()-last_received>5000000){
  was_connected=false;lv_label_set_text(link_label,"Disconnected - waiting for host");
  lv_label_set_text(cpu_label,"CPU LOAD\n--");lv_label_set_text(ram_label,"RAM\n--");
  lv_label_set_text(disk_label,"SYSTEM DISK\n--");lv_label_set_text(temp_label,"CPU TEMP\n--");
 }
}
static void fade(void *obj,int32_t v){
 night_opacity=v;lv_obj_set_style_opa(obj,v,0);
}
static void fade_done(lv_anim_t *a){(void)a;set_lcd_blight(sleeping?12:60);}
static void set_sleep(bool value){
 if(sleeping==value)return;
 sleeping=value;
 if(value)lv_obj_add_flag(panel,LV_OBJ_FLAG_HIDDEN);
 else {lv_obj_remove_flag(panel,LV_OBJ_FLAG_HIDDEN);set_lcd_blight(60);}
 lv_anim_delete(night_image,fade);
 lv_anim_t a;lv_anim_init(&a);lv_anim_set_var(&a,night_image);lv_anim_set_values(&a,night_opacity,value?255:0);
 lv_anim_set_duration(&a,2200);lv_anim_set_exec_cb(&a,fade);lv_anim_set_path_cb(&a,lv_anim_path_ease_in_out);lv_anim_set_completed_cb(&a,fade_done);lv_anim_start(&a);
}
static void sleep_clicked(lv_event_t *e){(void)e;set_sleep(true);}
static void scene_clicked(lv_event_t *e){(void)e;if(sleeping)set_sleep(false);}
static void atmosphere(lv_timer_t *timer){
 (void)timer;float t=esp_timer_get_time()/1000000.0f;
 lv_image_set_rotation(branch,(int)(8*sinf(t*.33f)));
 lv_image_set_pivot(branch,0,0);
 lv_obj_set_pos(branch,-8,-57+(int)(2*sinf(t*.27f)));
 lv_obj_set_style_image_recolor(branch,lv_color_hex(0x253c62),0);
 lv_obj_set_style_image_recolor_opa(branch,night_opacity*150/255,0);
 for(int i=0;i<10;i++){
  float phase=fmodf(t*.12f+i*.1f,1);
  lv_obj_set_pos(ripples[i],300+(i%4)*36+(int)(4*sinf(t*.4f+i)),337+(i/4)*12);
  lv_obj_set_width(ripples[i],14+(int)(phase*22));
  lv_obj_set_style_border_opa(ripples[i],(int)(sinf(phase*3.14159f)*(sleeping?18:50)),0);
 }
 for(int i=0;i<3;i++){
  lv_obj_set_pos(clouds[i],370+i*65+(int)(18*sinf(t*.04f+i)),105+i*48);
  lv_obj_set_style_bg_opa(clouds[i],sleeping?4:7,0);
 }
 for(int i=0;i<36;i++){
  float y=fmodf(t*(9+i%4*3)+i*19,530)-25;
  float x=fmodf(i*29+t*7,840)-20+12*sinf(t*.7f+i);
  lv_obj_set_pos(petals[i],(int)x,(int)y);
  lv_obj_set_style_bg_opa(petals[i],sleeping?50:150,0);
 }
 for(int i=0;i<3;i++){
  lv_obj_set_pos(mist[i],280+i*38+(int)(12*sinf(t*.22f+i)),310-i*17-(int)(9*sinf(t*.32f+i)));
  lv_obj_set_style_bg_opa(mist[i],sleeping?0:14+(int)(5*sinf(t*.4f+i)),0);
 }
}
static lv_obj_t *text_at(lv_obj_t *parent,int x,int y,int w,const char *text,bool large){
 lv_obj_t *l=lv_label_create(parent);lv_obj_set_pos(l,x,y);lv_obj_set_width(l,w);lv_label_set_text(l,text);lv_obj_set_style_text_color(l,lv_color_hex(0xfff3da),0);
 if(large)lv_obj_set_style_text_font(l,&lv_font_montserrat_24,0);
 return l;
}
static lv_obj_t *button(lv_obj_t *parent,int x,int y,int w,const char *text,lv_event_cb_t cb){
 lv_obj_t *b=lv_button_create(parent);lv_obj_set_pos(b,x,y);lv_obj_set_size(b,w,38);
 lv_obj_set_style_bg_color(b,lv_color_hex(0x374943),0);lv_obj_set_style_bg_opa(b,200,0);lv_obj_set_style_radius(b,8,0);
 lv_obj_set_style_shadow_width(b,0,0);lv_obj_add_event_cb(b,cb,LV_EVENT_CLICKED,NULL);
 lv_obj_t *l=lv_label_create(b);lv_label_set_text(l,text);lv_obj_set_style_text_color(l,lv_color_hex(0xfff8e8),0);lv_obj_center(l);return b;
}
static void build_ui(void){
 lv_obj_t *s=lv_screen_active();lv_obj_remove_flag(s,LV_OBJ_FLAG_SCROLLABLE);lv_obj_set_style_bg_color(s,lv_color_hex(0x101c2b),0);
 lv_obj_set_style_text_color(s,lv_color_hex(0xf7edda),0);
 lv_obj_t *day=lv_image_create(s);lv_image_set_src(day,&day_art);
 night_image=lv_image_create(s);lv_image_set_src(night_image,&night_art);lv_obj_set_style_opa(night_image,0,0);
 lv_obj_t *touch=lv_obj_create(s);lv_obj_remove_style_all(touch);lv_obj_set_size(touch,800,480);
 lv_obj_add_flag(touch,LV_OBJ_FLAG_CLICKABLE);lv_obj_add_event_cb(touch,scene_clicked,LV_EVENT_CLICKED,NULL);
 branch=lv_image_create(s);lv_image_set_src(branch,&branch_art);lv_obj_remove_flag(branch,LV_OBJ_FLAG_CLICKABLE);
 for(int i=0;i<10;i++){
  ripples[i]=lv_obj_create(s);lv_obj_remove_style_all(ripples[i]);lv_obj_set_size(ripples[i],25,5);
  lv_obj_set_style_radius(ripples[i],LV_RADIUS_CIRCLE,0);lv_obj_set_style_border_width(ripples[i],1,0);
  lv_obj_set_style_border_color(ripples[i],lv_color_hex(0xbdd4d9),0);lv_obj_set_style_bg_opa(ripples[i],0,0);lv_obj_remove_flag(ripples[i],LV_OBJ_FLAG_CLICKABLE);
 }
 for(int i=0;i<3;i++){
  clouds[i]=lv_obj_create(s);lv_obj_remove_style_all(clouds[i]);lv_obj_set_size(clouds[i],170,22);
  lv_obj_set_style_radius(clouds[i],LV_RADIUS_CIRCLE,0);lv_obj_set_style_bg_color(clouds[i],lv_color_hex(0xb3bfce),0);lv_obj_remove_flag(clouds[i],LV_OBJ_FLAG_CLICKABLE);
 }
 for(int i=0;i<3;i++){
  mist[i]=lv_obj_create(s);lv_obj_remove_style_all(mist[i]);lv_obj_set_size(mist[i],180,35);
  lv_obj_set_style_radius(mist[i],LV_RADIUS_CIRCLE,0);lv_obj_set_style_bg_color(mist[i],lv_color_hex(0xf3ede4),0);lv_obj_remove_flag(mist[i],LV_OBJ_FLAG_CLICKABLE);
 }
 for(int i=0;i<36;i++){
  petals[i]=lv_obj_create(s);lv_obj_remove_style_all(petals[i]);lv_obj_set_size(petals[i],4+i%3,3+i%2);
  lv_obj_set_style_radius(petals[i],3,0);lv_obj_set_style_bg_color(petals[i],lv_color_hex(0xffc7d5),0);lv_obj_remove_flag(petals[i],LV_OBJ_FLAG_CLICKABLE);
 }
 panel=lv_obj_create(s);lv_obj_set_pos(panel,476,16);lv_obj_set_size(panel,308,448);
 lv_obj_set_style_bg_color(panel,lv_color_hex(0x3a5048),0);lv_obj_set_style_bg_opa(panel,235,0);
 lv_obj_set_style_border_width(panel,1,0);lv_obj_set_style_border_color(panel,lv_color_hex(0xafa88d),0);lv_obj_set_style_border_opa(panel,90,0);
 lv_obj_set_style_radius(panel,16,0);lv_obj_set_style_pad_all(panel,14,0);lv_obj_remove_flag(panel,LV_OBJ_FLAG_SCROLLABLE);
 lv_obj_t *title=text_at(panel,0,0,270,"MOUNTAIN REFUGE",true);lv_obj_set_style_text_color(title,lv_color_hex(0xffc7d5),0);
 host_label=text_at(panel,0,32,278,"RESOURCE PANEL | USB",false);
 cpu_label=text_at(panel,0,64,132,"CPU LOAD\n--",true);
 temp_label=text_at(panel,145,64,133,"CPU TEMP\n--",true);
 ram_label=text_at(panel,0,148,278,"RAM\n--",true);
 disk_label=text_at(panel,0,245,278,"SYSTEM DISK\n--",true);
 link_label=text_at(panel,0,313,278,"Waiting for USB host",false);
 button(panel,0,346,133,"SLEEP DISPLAY",sleep_clicked);
 audio_button=button(panel,143,346,135,"AUDIO TEST",record_clicked);
 audio_label=text_at(panel,0,393,278,"Sakura drift | USB resources",false);
 lv_timer_create(update,250,NULL);lv_timer_create(atmosphere,50,NULL);
}
void app_main(void){
 ESP_ERROR_CHECK(i2c_init());vTaskDelay(pdMS_TO_TICKS(200));ESP_ERROR_CHECK(stc8_i2c_init());ESP_ERROR_CHECK(touch_init());
 ESP_ERROR_CHECK(audio_ctrl_init());ESP_ERROR_CHECK(set_Audio_ctrl(false));ESP_ERROR_CHECK(audio_init());ESP_ERROR_CHECK(mic_init());ESP_ERROR_CHECK(display_init());
 samples=xQueueCreate(1,sizeof(metrics_t));assert(samples);
 if(lvgl_port_lock(0)){build_ui();lvgl_port_unlock();}
 ESP_ERROR_CHECK(set_lcd_blight(60));
 const uart_config_t cfg={.baud_rate=115200,.data_bits=UART_DATA_8_BITS,.parity=UART_PARITY_DISABLE,.stop_bits=UART_STOP_BITS_1,.flow_ctrl=UART_HW_FLOWCTRL_DISABLE,.source_clk=UART_SCLK_DEFAULT};
 ESP_ERROR_CHECK(uart_param_config(UART_NUM_0,&cfg));ESP_ERROR_CHECK(uart_driver_install(UART_NUM_0,2048,0,0,NULL,0));
 assert(xTaskCreate(receiver,"telemetry_rx",6144,NULL,4,NULL)==pdPASS);
}

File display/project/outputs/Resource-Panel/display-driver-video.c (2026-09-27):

/**
 * @file bsp_illuminate.c
 * @brief Teaching source for 5inch_P4_IDF_09_LVGL_Lighting_Control.
 *
 * This file is part of the CrowPanel Advanced 5-inch ESP32-P4 course.
 * The comments explain module responsibilities and observable behavior
 * without changing the original program logic.
 */

/*————————————————————————————————————————Header file declaration————————————————————————————————————————*/
#include "bsp_illuminate.h"  // Include BSP display header (LCD and related configurations)
#include "bsp_stc8h1kxx.h"   // Include header for STC8H1KXX microcontroller (used for PWM control)
#include "bsp_display.h" 
/*——————————————————————————————————————Header file declaration end——————————————————————————————————————*/

/*——————————————————————————————————————————Variable declaration—————————————————————————————————————————*/

esp_lcd_panel_handle_t panel_handle = NULL;          /* Type of LCD panel handle */
static lv_display_t *my_lvgl_disp = NULL;            /* Backward compatibility with LVGL 8 */

static lv_obj_t *color_obj;                          // LVGL canvas object pointer
lv_color_t *color_buffer;                            // LVGL color buffer pointer

static lv_indev_t *my_touch_indev;
/*————————————————————————————————————————Variable declaration end———————————————————————————————————————*/

/*—————————————————————————————————————————Functional function———————————————————————————————————————————*/

static esp_err_t blight_init(void)  // Initialize LCD backlight (PWM control)
{
    return ESP_OK;  // Return success (currently no specific initialization)
}

/* brightness -  (0 - 100) */
/**
 * @brief Perform the set lcd blight operation.
 *
 * Called by the application when this module operation is required.
 * @param brightness Input or output value used by this operation.
 * @return Result produced by the operation; see the function implementation for success and error values.
 */
esp_err_t set_lcd_blight(uint32_t brightness)
{
    esp_err_t err = ESP_OK;                                     // Define error status variable
    stc8_set_pwm_duty(STC8_PWM_LCD_BL_EN, brightness);          // Set the PWM duty cycle for LCD backlight brightness
    return err;                                                 // Return success
}

/**
 * @brief Perform the display port init operation.
 *
 * Called during application startup before the related peripheral is used.
 * @return Result produced by the operation; see the function implementation for success and error values.
 */
static esp_err_t display_port_init(void)
{
    esp_err_t err = ESP_OK;                                     // Define error status variable

    esp_lcd_rgb_panel_config_t panel_config = {                 /* RGB LCD configuration structure */
        .data_width = RGB_DATA_BUS_WIDTH,                       /* Data width: 16 bits */
#if ESP_IDF_VERSION < ESP_IDF_VERSION_VAL(5, 3, 0)
        .psram_trans_align = 64,                                // Alignment for PSRAM buffer (older IDF version)
#else
        .dma_burst_size = 64,                                   /* DMA burst size alignment for PSRAM buffer */
#endif
        .num_fbs = 2,                                           /* Number of frame buffers */
        .bounce_buffer_size_px = 10 * RGB_LCD_H_RES, // Internal DMA staging reduces contention with the C6 SDIO bus.
        .clk_src = LCD_CLK_SRC_DEFAULT,                         /* Clock source for RGB LCD peripheral */
        .disp_gpio_num = RGB_PIN_NUM_DISP_EN,                   /* Display enable control pin, -1 if unused */
        .pclk_gpio_num = RGB_PIN_NUM_PCLK,                      /* PCLK signal pin */
        .vsync_gpio_num = RGB_PIN_NUM_VSYNC,                    /* VSYNC signal pin (not required in DE mode) */
        .hsync_gpio_num = RGB_PIN_NUM_HSYNC,                    /* HSYNC signal pin (not required in DE mode) */
        .de_gpio_num = RGB_PIN_NUM_DE,                          /* DE (Data Enable) signal pin */
        .data_gpio_nums = {                                     // RGB data pins
            RGB_PIN_NUM_DATA0,
            RGB_PIN_NUM_DATA1,
            RGB_PIN_NUM_DATA2,
            RGB_PIN_NUM_DATA3,
            RGB_PIN_NUM_DATA4,
            RGB_PIN_NUM_DATA5,
            RGB_PIN_NUM_DATA6,
            RGB_PIN_NUM_DATA7,
            RGB_PIN_NUM_DATA8,
            RGB_PIN_NUM_DATA9,
            RGB_PIN_NUM_DATA10,
            RGB_PIN_NUM_DATA11,
            RGB_PIN_NUM_DATA12,
            RGB_PIN_NUM_DATA13,
            RGB_PIN_NUM_DATA14,
            RGB_PIN_NUM_DATA15,
#if CONFIG_RGB_LCD_DATA_LINES > 16
            RGB_PIN_NUM_DATA16,
            RGB_PIN_NUM_DATA17,
            RGB_PIN_NUM_DATA18,
            RGB_PIN_NUM_DATA19,
            RGB_PIN_NUM_DATA20,
            RGB_PIN_NUM_DATA21,
            RGB_PIN_NUM_DATA22,
            RGB_PIN_NUM_DATA23
#endif  
        },                                          
        .timings = {                                /* RGB LCD timing parameters */
            .pclk_hz = RGB_LCD_PIXEL_CLOCK_HZ,      /* Pixel clock frequency */
            .h_res = RGB_LCD_H_RES,                 /* Horizontal resolution (pixels per line) */
            .v_res = RGB_LCD_V_RES,                 /* Vertical resolution (lines per frame) */
            .hsync_back_porch = RGB_LCD_HBP,        /* Horizontal back porch (PCLK cycles between HSYNC and active data) */
            .hsync_front_porch = RGB_LCD_HFP,       /* Horizontal front porch (PCLK cycles between active data and next HSYNC) */
            .hsync_pulse_width = RGB_LCD_HSYNC,     /* HSYNC pulse width (in PCLK cycles) */
            .vsync_back_porch = RGB_LCD_VBP,        /* Vertical back porch (blank lines between VSYNC and frame start) */
            .vsync_front_porch = RGB_LCD_VFP,       /* Vertical front porch (blank lines between frame end and next VSYNC) */
            .vsync_pulse_width = RGB_LCD_VSYNC,     /* VSYNC pulse width (in lines) */
            .flags = {
                .hsync_idle_low = false,            /*!< HSYNC signal is low in IDLE state */
                .vsync_idle_low = false,            /*!< VSYNC signal is low in IDLE state */
                .de_idle_high = false,              /*!< DE signal is high in IDLE state */
                .pclk_active_neg = true,            /* RGB data is sampled on falling edge of PCLK */
                .pclk_idle_high = true,             /* PCLK remains high during idle periods */
            },
        },
        .flags.fb_in_psram = true,                  /* Allocate frame buffer in PSRAM */
    };
    err = esp_lcd_new_rgb_panel(&panel_config, &panel_handle);  /* Create a new RGB panel instance */
    if (err != ESP_OK)
        return err;                                 // Return error if panel creation fails
    ESP_ERROR_CHECK(esp_lcd_panel_reset(panel_handle)); /* Reset the RGB panel */
    
    ESP_ERROR_CHECK(esp_lcd_panel_init(panel_handle));  /* Initialize the RGB panel */
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

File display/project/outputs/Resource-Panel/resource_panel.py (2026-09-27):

import argparse, json, math, os, platform, time
from pathlib import Path
import psutil
import serial
from serial.tools import list_ports


def cpu_temperature():
    getter = getattr(psutil, 'sensors_temperatures', None)
    if getter:
        try:
            sensors = getter()
            for group in ('coretemp', 'k10temp', 'cpu_thermal', 'cpu-thermal', 'zenpower'):
                values = [s.current for s in sensors.get(group, []) if s.current is not None and math.isfinite(s.current)]
                if values:
                    return round(max(values), 1)
        except (OSError, RuntimeError):
            pass
    if platform.system() == 'Linux':
        for zone in Path('/sys/class/thermal').glob('thermal_zone*'):
            try:
                if zone.joinpath('type').read_text().strip() in ('cpu-thermal', 'cpu_thermal', 'x86_pkg_temp'):
                    return round(int(zone.joinpath('temp').read_text()) / 1000, 1)
            except (OSError, ValueError):
                pass
    if platform.system() == 'Windows':
        from windows_temperature import reader
        return reader.read()
    return None


def sample(disk):
    memory = psutil.virtual_memory()
    return {'v': 1, 'host': platform.node()[:40], 'os': platform.system(),
            'cpu': round(psutil.cpu_percent(interval=None), 1),
            'ram': round(memory.percent, 1), 'used': round((memory.total-memory.available)/2**30, 1),
            'total': round(memory.total/2**30, 1), 'disk': round(psutil.disk_usage(disk).percent, 1),
            'temp': cpu_temperature()}


def main():
    parser = argparse.ArgumentParser(description='USB resource dashboard for the Elecrow P4 panel')
    parser.add_argument('--port', help='COM10 on Windows; /dev/serial/by-id/... on Linux')
    parser.add_argument('--list-ports', action='store_true')
    parser.add_argument('--once', action='store_true', help='Print one sample without opening USB')
    parser.add_argument('--disk', default=os.path.abspath(os.sep), help='Filesystem to monitor; default system root')
    parser.add_argument('--seconds', type=float, default=0, help='Stop after this many seconds; default runs until Ctrl+C')
    parser.add_argument('--panel-log', type=Path, help='Optional local diagnostic log from the display (limited to 2 MB)')
    args = parser.parse_args()
    if args.list_ports:
        for port in list_ports.comports():
            print(f'{port.device}: {port.description}')
        return
    if not args.port and not args.once:
        parser.error('Specify --port or use --list-ports')
    psutil.cpu_percent(interval=None)
    time.sleep(1)
    if args.once:
        print(json.dumps(sample(args.disk), allow_nan=False))
        return
    end = time.monotonic()+args.seconds if args.seconds else float('inf')
    connection = None
    last_sent = None
    try:
        while time.monotonic() < end:
            try:
                if connection is None:
                    connection = serial.Serial()
                    connection.port=args.port
                    connection.baudrate=115200
                    connection.timeout=0
                    connection.write_timeout=2
                    connection.dtr=False
                    connection.rts=False
                    connection.open()
                    last_sent = None
                    print(f'Connected to {args.port}', flush=True)
                frame = sample(args.disk)
                now = time.time()
                frame['wake'] = last_sent is None or now-last_sent > 5
                payload = json.dumps(frame, separators=(',', ':'), ensure_ascii=True, allow_nan=False).encode()+b'\n'
                if len(payload)>511:
                    raise ValueError('Telemetry packet exceeds panel limit')
                connection.write(payload)
                last_sent = now
                # Drain the panel log to prevent the host receive buffer from filling.
                incoming = connection.read(connection.in_waiting)
                if incoming and args.panel_log:
                    mode = 'wb' if args.panel_log.exists() and args.panel_log.stat().st_size > 2_000_000 else 'ab'
                    with args.panel_log.open(mode) as log:
                        log.write(incoming)
                time.sleep(1)
            except (serial.SerialException, OSError) as error:
                print(f'USB unavailable; retrying: {error}', flush=True)
                if connection:
                    connection.close()
                connection=None
                time.sleep(2)
    except KeyboardInterrupt:
        pass
    finally:
        if connection:
            connection.close()

if __name__=='__main__':
    main()

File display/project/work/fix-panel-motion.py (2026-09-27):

from pathlib import Path
p=Path('work/panel-test/peripheral/bsp_illuminate/bsp_illuminate.c')
s=p.read_text();a=s.index('#if CONFIG_DISPLAY_LVGL_FULL_REFRESH');b=s.index('        },',a)
s=s[:a]+'''            .full_refresh = true, // Redraw both complete buffers; avoid stale rectangles during transparent animation.
            .direct_mode = false,
'''+s[b:];p.write_text(s)
p=Path('work/panel-test/main/main.c');s=p.read_text()
s=s.replace('lv_obj_set_width(l,w);lv_label_set_text(l,text);','lv_obj_set_width(l,w);lv_label_set_text(l,text);lv_obj_set_style_text_color(l,lv_color_hex(0x182c25),0);')
s=s.replace('lv_label_set_text(l,text);lv_obj_center(l);return b;', 'lv_label_set_text(l,text);lv_obj_set_style_text_color(l,lv_color_hex(0xfff8e8),0);lv_obj_center(l);return b;')
s=s.replace('lv_color_hex(0x162923),0);lv_obj_set_style_bg_opa(panel,205','lv_color_hex(0xf4ead7),0);lv_obj_set_style_bg_opa(panel,245')
s=s.replace('set_lcd_blight(40)','set_lcd_blight(60)').replace('sleeping?8:40','sleeping?12:60')
s=s.replace('lv_obj_remove_flag(s,LV_OBJ_FLAG_SCROLLABLE);','lv_obj_remove_flag(s,LV_OBJ_FLAG_SCROLLABLE);lv_obj_set_style_bg_color(s,lv_color_hex(0x101c2b),0);')
s=s.replace('lv_obj_set_style_bg_opa(mist[i],(sleeping?8:14)+(int)(5*sinf(t*.4f+i)),0);','lv_obj_set_style_bg_opa(mist[i],sleeping?0:14+(int)(5*sinf(t*.4f+i)),0);')
p.write_text(s)

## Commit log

2026-09-27 Preserve panel firmware, companion, original media and migration handover
    [partitions.csv]
2026-09-27 Pin downloadable SDK and toolchain archives with SHA256 checksums
2026-09-27 Add Bazzite display concept and 48-pixel LED control preview
2026-10-01 Add BC250 case CAD and complete rendering snapshot
    [10x2_Magnet.SLDPRT, 16mm_Power_Button.SLDPRT, 180degree_USB_Adapter.SLDPRT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]
2026-10-01 Make the BC250 case the repository landing page and move display package
    [partitions.csv]
2026-10-02 Clarify cover types in BC250 Ronin description
    Updated description for BC250 Ronin case design to clarify cover types.
2026-10-04 Publish V6c extended Matchstick commercial and current imagery
2026-10-04 docs: publish Ronin build manual draft with revision warnings
    [BC250_CAD_BOM_Rev_0p3.csv, BC250_Open_Items_Rev_0p3.csv, BC250_Proposed_Hardware_Rev_0p3.csv]
2026-10-06 docs: distinguish current display prototype from repository baseline
2026-10-07 Document Ronin branding, ordered LED adapter and NVMe harness revision
